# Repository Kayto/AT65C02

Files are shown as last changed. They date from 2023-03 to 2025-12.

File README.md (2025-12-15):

# AT65C02

**Latest News 15/12/2025**

**ATOS Software Released!** The main software suite for AT65C02 is now available in the Software_ATOS directory. ATOS (AT65C02 Operating System) provides a complete ROM-based monitor (SMON), interactive shell, trace/debugging commands, loadable program support, and integrated EhBASIC. The codebase has been extensively cleaned up and optimized with comprehensive documentation. This is now the recommended primary software for the AT65C02 platform.

**Hardware ideas 29/05/2025**

Picking up a few ideas for updates and improvements of the AT65C02.

1. How useful is the modem? Will i ever get around to testing this and integrating code? My vote is swinging to remove it. Opportunity to tidy the layout to better group a pinout for onboard rom programming.
2. I didn't add the possibility of using a MOS 6502! Looks like a simple jumper addition would allow this. 
3. The wireless UART doesnt have flow control - is there an alternative plug in wireless board that can provide this?
4. The HEX board resistor values...[sigh]!

**Previous News**
* **Minor fixes/additions to PCB to address some of the issues (see below revisions section).**
* **I am likely to pick up a futher revision 005 to address and consolidate some of the outstanding issues.**

## Introduction

Who doesn't want to build an 8 bit computer, if you don't, look away now.
I'm not a great coder or really an experienced maker but have enjoyed the magic of tinkering around with electronics since an early age. Whilst I have dabbled with 8 bit computing since the 80s, 40 years later I realise that I still do not really understand the inner workings of them. This project was to fill this knowledge gap.

Some of the best learning is obtained from example, making mistakes and getting your hands dirty. The only way for me is to actually break things down into individual steps, unpick the items then see how they all fit together and contribute.

I cant really credit myself with "designing" the AT65C02 - it borrows heavily from the work of others. However in breaking down these designs, incorporating changes and putting them together into my very own customised board, I have in many ways gained a much better understanding of how an 8 bit computer works. Result!

## Credits and thanks

Credits and thanks are worthy of being up front especially as I have leaned heavily on the work of others. Please follow the links to their respective documentation, they are far better at explaining and documenting than I can ever provide.

* <b>[Ben Eater's 8 bit computer](https://eater.net/8bit/)</b> \- the original inspiration\.
* <b>[Dawid Buchwald's](https://github.com/dbuchwald/6502)</b> DB6502 - this is brilliantly described and the designs form the basis for the AT65C02. The code examples and build environment are also the best for getting a solid base for coding. I recommend the github and [hackaday](https://hackaday.io/project/174128-db6502) report entries to really provide a deeper explanation of the design.
* <b>[Daryl Rictor](https://sbc.rictor.org/decoder.html)</b> \- for the DEC\-1 design\. The overall site also provides some great hobby computer examples\.
* <b>[AndersBNielsen](https://github.com/AndersBNielsen/SimpleModem)</b> for the "Simple Universal Modem" design.
* <b>[TEBL](https://github.com/tebl/C64-BlinkenDiag)</b> for the basis of the Blinkenlights.
* <b>[Michael Billington](https://github.com/mike42/6502-computer)</b> 65C02 computer - my first 65C02 build, super compact and a great starter for this journey.

## General Aims

* A 6502 build, as I am most familiar with this CPU and have at least a start at knowing some code and hardware requisities.
* Provide a learning platform for both the hardware and software. Ideally have a ready code base to get started with quickly.
* Avoid the hassles of masses of wiring and connections. To suit limited space, no mass of breadboards and able to tuck away in a cupboard to pick up quick.
* No great purist aspirations on the hardware, readily available components and no need to learn other code to get things running.

## Bespoke Aims

Some of these are really down to personal preference and perhaps held back a little by lack of knowledge.

* A load and save interface - to avoid pulling and burning ROMs every code example.
* Plenty of expansion - allows to tinker with interfacing displays and add ons.
* Wireless serial - the less wires the better.
* Adjustable memory decoder - because I can be indecisive and like to tinker.
* Blinkies - so I can get a real look at monitoring whats going on at an individual control signal, data and address line level.

## Final Features



In no particular order the main features in the final board are as follows.

* Onboard Step clock with manual and automatic tick. Speeds aprox 1-500Hz.
* Onboard 1mhz fixed clock.
* Seperate onboard serial clock.
* Blinky indicators - main signals, data and address, individual on/off switches.
* UART interface for external USB serial interface.
* ESP interface for wireless UART interface.
* Level shifter port for 5v and 3.3v signal conversion.
* Onboard 3.3v power regulator.
* Flexible IO and memory decoder via programable GAL. (this is now an add on board - it was too much to include on the same board).
* 2No VIAs - one for Keyboard, LCB and Blink LED - one spare for projects.
* Keyboard interface port (nice to have).
* LCD interface port.
* Onboard Blink LED (VIA1).
* VIA2 interface port.
* 4No. System Bus expansion interfaces (1No. via blinky latches).
* Modem audio interface.
* CPU extra signal breakout.
* LED brightness and LCD contrast adjusters - for late night blinky watching.
* Breakouts for ROM allow programming onboard via an Arduino or see below for ZIF option.
* Optional ZIF socket for ROM. Its a tight space but PCB ammended to accomodate the option of a ZIF socket at U8. **Please note that the ZIF socket interfers with the HEX expansion board. You will need a greater standoff to fit. The ZIF handle may also need shortening**.

## Memory Map

As will become clear when you tinker with 6502 builds, the hardware decisions up front impact the available memory size and locations.
Dawid Buchwald DB6502 provides a great explanation of the decisions around the choice of memory map and the differences with Ben Eater's design.
The default memory map for the AT65C02 is the same as DB6502 as follows.

| Segment | AT65C02 | Comment |
| --- | --- | --- |
| RAM | 0x0000-0x7fff | 32K |
| VIA1 | 0x9000 | Connected to keyboard/LCD/blink LED |
| VIA2 | 0x8800 | VIA 2 port |
| ACIA | 0x8400 |  |
| ROM | 0xa000-0xffff | 24K First 8K of 32K ROM are not accessible |

Given I can be indecisive and to allow some experimentation with alternative memory maps I have included the option of switching to a programmable memory decoder. This uses the DEC-1 design by Daryl Rictor. The default DEC-1 map is as follows but with a bit of programming of the GALV22V10, you can experiment with other maps.

| Segment | DEC-1 | Comment |
| --- | ----- | --- |
| RAM | $0000-$01FF | zero page and stack space |
| IO Device #1 | $0200-$020F | (16 bytes) |
| IO Device #2 | $0210-$021F | (16 bytes) |
| IO Device #3 | $0220-$022F | (16 bytes) |
| IO Device #4 | $0230-$023F | (16 bytes) |
| Unassigned | $0240-$02FF |  |
| RAM | $0300-$7FFF | 32K |
| ROM | $8000-$FFFF | 32K |

## AT65C02 Build

The Final Rev004 PCB corrects the errors in my test builds. This first (Rev002) and second (Rev003) and third (Rev004) build was documented on [twitter](https://twitter.com/AdamT117). Feel free to check out those posts.

**Rev003 Spolier Alert** \- I had high hopes that Rev003 would be the final but alas things never work out as they should\, especially when learning\. Rev003 board undergoing testing\. ROM and VIA address decoding \- tested working\. RAM was troublesome\. I had a short between RAM OE and the RAM CS at the 74HC00 gates\. Oddly this was still there with all ICs unpopulated so must be a hidden short or trace damage\. The bare PCBs were ok\, so ruled that one out\. Given lack of time and parts I couldn't face another full build of a spare board\. Temporarily bodging the 74HC00 \(until i can find time to reassemble another board\)\, the Programmable memory decoder works when added to the dedicated expansion port\. Tested working alternative map with ROM at $8000\. OS/1 tested working via wireless serial add ons\. There is an issue on loading anything over 1K via wireless serial but this looks to be a software problem\.

**Rev002 Spolier alert** -The issues I found were mainly related to incorporating the adjustable address decoder. In trying to incorporate both a fixed and programmable GAL decoder I inadvertently bridged the RAM and ROM OE/CS lines. This was fixed with a trace cut and bodge but rendered the programmable memory decoder useless. Troubleshooting for the rev003 modifications involved temporary wires and jumpers. Other minor issues were silkscreen errors, this led me down a rabbit hole on a few occasions. The UART labels were mixed up, the level shifter pinout order was on the bottom of the board, the oscillator orientation was not clearly marked etc. I also took the opportunity to add in additional breakout headers for some unused CPU lines and for the ROM - allowing onboard ROM programming.

The repository provides the files for you to create your very own AT65C02.

* [Schematics](https://github.com/Kayto/blob/main/KiCad/Rev004/AT65C02_Schematic.pdf)
* [KiCad project files](https://github.com/Kayto/tree/main/KiCad/Rev004)
* [Gerber files](https://github.com/Kayto/tree/main/Gerbers)
* [BOM](https://github.com/Kayto/blob/main/KiCad/Rev004/AT_65C02_Computer_Rev004.csv)


### REVISION STATUS & ISSUES

**REV 004 - for final issue**

* Main board, Hex board and Programmable Memory Decoder Tested working.
* Modem - UNTESTED AT THE MOMENT

**Slight annoyances (which may or may not be investigated/fixed)**

* Hex board - for data FF the low F is very low brightness. It really needs some further balancing of the resistor values and grounding.
* Blinkies - Data lines have a bit of jitter with the clock. No biggie but OCD spotted it.
* Wireless Serial - using Xmodem is fine with very small code uploads but the larger files fail. Workaround is to use a wired serial. I am hoping this can be helped with code but might wait until I can acquire the skills to troubleshoot! **Update 06/2024. Rather stupidly I forgot that the ESP-01 does not have flow control. Therefore anything bigger than the buffer (like large file transfers) fails. The ESP-01 therefore provides a useful serial input but its use is limited.**
* Wired UART Interface - Silkscreen RTS and CTS need swapping. Bit of a mistake as I was looking at a direct FTDI plug in. As FTDI programmers vary its no big issue to use jumper wires. **Fixed 08/2023**.
* Wireless or wired serial switching - would have been nice to have a jumper to switch out the wireless ESP-01 module rather than unplugging. **Fixed 08/2023**.
* Breakouts for x2 spare level shifter channels. **Fixed 08/2023**.
* Standardise some headers to even sizes. **Fixed 08/2023**.

## JUMPERS

There are a number of jumpers/headers on the PCB which may need some explanation?
I have created a separate page [here](https://github.com/Kayto/blob/main/Jumpers.md) to explain them.

## Software

### ATOS - Primary Software Suite (RECOMMENDED)

**[Software_ATOS](https://github.com/Kayto/AT65C02/tree/main/Software/Software%20_ATOS)** is the main firmware and software suite for the AT65C02. It provides a complete operating environment with ROM-based SMON monitor, interactive shell, comprehensive debugging tools, and loadable program support.

**Key Features:**
- ROM-based SMON monitor with full debugging capabilities
- Interactive shell with command history
- Trace commands: single-step (TW), breakpoints (TB), run-to-address (TQ/TS)
- Loadable program support via Intel HEX format
- Integrated EhBASIC interpreter
- LCD and serial I/O drivers
- Multiple UART support (6551, 6522, 6850)
- Complete build system using Docker (cc65 toolchain)
- VS Code integration with build tasks

**Quick Start:**
```bash
cd Software_ATOS
docker run --rm -v '${PWD}:/mnt/project' dawidbuchwald/cc65-tools-make all
```

See the [ATOS README]([Software_ATOS](https://github.com/Kayto/AT65C02/tree/main/Software/Software%20_ATOS)/README.md) for complete documentation.

### Alternative Software Options

As stated earlier Dawid Buchwald provides a suite of ROM and loadable sources in his github repo. This will get you on your way to coding quickly. If you are struggling with a build environment then he also has great tutorial examples and even provides a [docker image](https://github.com/dbuchwald/cc65-tools), great work.

I am trying to avoid duplication of the original code repos so where possible will only include the new or revised code. Please check the original author licence included in the folders and in the acknowledgments.

| Reference | Description | Credit |
| --- | --- | --- |
| **[50\_mem\_read](https://github.com/Kayto/tree/main/Software/50_mem_read)** | RAM test, VIA1 and VIA 2 test blinks | by me - needs to be combined with the DB6502 repo for compilation. |
| **[sbc2os](https://github.com/Kayto/tree/main/Software/sbc2os)** | I include here the revised TASS source as it needed changes for the default AT65C02 memory map. A binary is also included for those who may struggle with TASS. | Original by [Daryl Rictor](https://sbc.rictor.org/sbcos.html). The original author README is included. |
| **[EhBasic](https://github.com/Kayto/tree/main/Software/EhBasic)** | Using the DB6502 docker image for compilation | Refer to the included [license](https://github.com/Kayto/blob/main/Software/EhBasic/LICENSE) file. |
| **[smon6502](https://github.com/Kayto/tree/main/Software/smon6502)** | [dhansel smon6502](https://github.com/dhansel/smon6502) Using the DB6502 VASM docker image for compilation. | Refer to the included [Readme](https://github.com/Kayto/blob/main/Software/smon6502/readme.md) file. |
| **[sysmon65](https://github.com/Kayto/tree/main/Software/SYSMON65-main)** | [jdimeglio sysmon65](https://github.com/jdimeglio/SYSMON65) | Binary only ATM. Will include the relevant modified source files shortly. Use original source and replace files that have been modified. Compilation requires the Michal Kowalski assembler/simulator |

The only other code requirement is for the ATTiny4313, for the onboard keyboard controller. An explanation of this is in the [Arduino](https://github.com/Kayto/tree/main/Software/Arduino) folder.

## Expansion

### Hex Board



Gerbers and KiCad is provided in this repo for an expansion board. This PCB plugs into the expansion port next to the blinkies. It provides hexidecmal display output aligned with the blinkenlights. Look in the software folder for the .jed files for programming the GALs.

### Programmable IO and memory decoder



This is now a seperate PCB that plugs into the relevant marked ports. Gerbers and KiCad provided. Allows tinkering with IO and memory maps. The design is based on the DEC-1 so refer to the links to Daryl Rictor's site for the .jed file for the GAL.

## Future Expansion

I have a number of aspirations for future expansion boards which are part way into development or at least have me thinking about. Most will rely on code development so really have no fixed date for release.

#### Floppy Drive controller

Allowing connection and control of a 5.25inch floppy disc drive. There are a few existing examples by some clever folk that could be adapted for use. I envisage a vertical board into an expansion slot - there are also plenty of additional breakouts on the AT65C02 that could be jumper wired if needed. A connector on an expansion board is not that robust. I thought of providing space for a DIN connector on the main board to serve this future item - but will save as just an idea for now.

#### Case

This could be an easy one as by some fluke the board size seems to fit some IKEA storage boxes I use. Most of the switches used on the board can be jumpered as I have used header pins. Similarily any expansion could be wired up too.



#### Debugger Plug-in

**Coming Soon -** A plug in board to allow degugging and onboard ROM programming via an Arduino.

## Licenses & acknowledgement

Further to the links in the credit section.
The design is an extension of Ben Eater's 6502 computer tutorial, which is itself based on the work of the 6502.org community.

**6502 KiCad Library**

The PCB files use modified versions of the 6502 KiCad Library. Copyright 2018, Nicholas Parks Young. All Rights Reserved. The 6502 KiCad Library library is licensed under the GNU LGPL v2.1

**EhBASIC**

With the exception of the files noted below, code base © 2021 Michael Billington, and is licensed under a Creative Commons Attribution 4.0 International License.
The files in EhBasic/basic/ are derived from EhBASIC, developed by Lee Davidson. The EhBASIC license allows for non-commerical use only. The most recent release and manual is hosted here, and a mirror of Lee's website can be found here.

EhBASIC is free but not copyright free. For non commercial use there is only one restriction, any derivative work should include, in any binary image distributed, the string "Derived from EhBASIC" and in any distribution that includes human readable files a file that includes the above string in a human readable form e.g. not as a comment in an HTML file.

**DB6502 Code**

OS/1, related code examples and Arduino code is Copyright (c) 2020 Dawid Buchwald and is licensed under a MIT License.

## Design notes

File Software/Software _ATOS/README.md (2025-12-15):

# ATOS - AT65C02 Operating System

ATOS is the main firmware and software suite for the [AT65C02 computer](https://github.com/Kayto/AT65C02). It provides a complete operating environment with ROM-based monitor, shell, and loadable program support.

## Overview

ATOS combines SMON with an enhanced shell, LCD support, and EhBASIC integration to create a complete operating system for the AT65C02. The system supports loading and running programs from serial input, provides a comprehensive debugging environment, and includes built-in BASIC interpreter.

**Key Features:**

* ROM-based monitor (SMON) with full debugging support
* Interactive shell with command history and help system
* Trace/debugging commands: single-step, breakpoints, run-to-address
* Loadable program support via Intel HEX format
* Integrated EhBASIC interpreter
* LCD and serial I/O support
* Multiple UART options (6551, 6522, 6850)

## Quick Start

### Building Everything

``` bash
docker run --rm -v '${PWD}:/mnt/project' dawidbuchwald/cc65-tools-make all
```

This builds:

* **ROM firmware** (ATOS.ext.bin) - Flash to EEPROM at $A000-$FFFF
* **All loadable programs** \- Load via SMON `.L` command

### Building Just the ROM

``` bash
docker run --rm -v '${PWD}:/mnt/project' dawidbuchwald/cc65-tools-make -C rom/ATOS all
```

Output: `build/rom/ATOS.ext.bin` (24KB)

### Installing to EEPROM

``` bash
docker run --rm -v '${PWD}:/mnt/project' dawidbuchwald/cc65-tools-make -C rom/ATOS all install
```

Requires minipro programmer.

## Directory Structure

```
Software_ATOS/
├── rom/ATOS/           # ROM firmware source
│   ├── smon.s          # SMON monitor
│   ├── shell.s         # Interactive shell
│   ├── lcd.s           # LCD driver
│   ├── boot_anim.s     # Boot animation
│   ├── basic_rom.s     # EhBASIC integration
│   ├── kernal.s        # Kernal functions & UART drivers
│   ├── config.s        # System configuration
│   ├── uart_6551.s     # WDC 65C51 ACIA driver
│   ├── uart_6522.s     # MOS 6522 VIA UART driver
│   ├── uart_6850.s     # MC6850 UART driver
│   └── atos.cfg        # Linker configuration
├── load/               # Loadable programs
│   ├── ehbasic/        # EhBASIC loadable version ($2000)
│   ├── trace_test/     # SMON trace command test program
│   ├── lcd_hello/      # LCD hello world example
│   ├── serial_hello/   # Serial hello world example
│   ├── via2_led_flash/ # VIA2 LED flasher
│   ├── via_alternate/  # VIA LED alternate blink
│   └── via2_flash_trace/ # VIA2 with trace test
├── common/             # Build infrastructure
│   ├── makefile        # Common build rules
│   ├── load.cfg        # Loadable program linker config
│   ├── bin2hex.py      # Binary to Intel HEX converter
│   └── loadtrim.py     # Loadable binary trimmer
└── BASIC/              # EhBASIC example programs
```

## Memory Map

ATOS uses the DB6502-compatible memory map:

| Address Range | Usage | Size |
| --- | ----- | ---- |
| $0000-$00FF | Zero page | 256 bytes |
| $0100-$01FF | Stack | 256 bytes |
| $0200-$0FFF | System RAM | 3.5 KB |
| $1000-$7FFF | User RAM | 28 KB |
| $8000-$8FFF | Filler (unmapped) | 4 KB |
| $9000-$9FFF | VIA1 | 4 KB window |
| $8800-$8FFF | VIA2 | 2 KB window |
| $8400-$87FF | ACIA | 1 KB window |
| $A000-$FFFF | ROM (ATOS) | 24 KB |

**Hardware addresses:**

* VIA1: $9000 (Keyboard/LCD/Blink LED)
* VIA2: $8800 (Expansion port)
* ACIA: $8400 (Serial communication)

**Loadable programs** run from $1000-$3000 (trace\_test, lcd\_hello, serial\_hello) or $2000-$8000 (ehbasic).

## SMON Monitor Commands

SMON provides a comprehensive debugging and development environment:

### Memory Operations

* `M xxxx yyyy` \- Memory dump from xxxx to yyyy
* `:xxxx nn nn...` \- Store bytes starting at xxxx
* `C xxxx yyyy zzzz` \- Copy memory from xxxx\-yyyy to zzzz
* `F xxxx yyyy nn` \- Fill memory from xxxx to yyyy with byte nn

### Execution & Tracing

* `G xxxx` \- Run to BRK from address xxxx \(fast execution\)
* `TW xxxx` \- Single\-step with keypress \(trace walk\)
* `TB xxxx nn` \- Breakpoint with hit count \(trace breakpoint\)
* `TQ xxxx` \- Run to breakpoint\, then single\-step \(trace queue\)
* `TS xxxx yyyy` \- Run until address \(trace stop\)

### Loading & Running

* `.L` \- Load Intel HEX file from serial
* `.T xxxx` \- Test/hexdump memory from xxxx
* `.R` \- Reset system
* `B` \- Run EhBASIC \($A000\)

### Disassembly & Utilities

* `D xxxx yyyy` \- Disassemble from xxxx to yyyy
* `A xxxx` \- Assemble at address xxxx
* `R` \- Display/modify registers
* `? xxxx+yyyy` \- Add hex values
* `? xxxx-yyyy` \- Subtract hex values
* `# xxxx` \- Convert hex to decimal
* `$ nnnn` \- Convert decimal to hex
* `% bbbb` \- Convert binary to hex
* `H` \- Display help

### Configuration

* `O` \- Display configuration
* `W n` \- Set UART type \(1=6522\, 2=6551\, 3=6850\)

See [load/trace\_test/TESTING.md](load/trace_test/TESTING.md) for detailed trace command examples and debugging workflow.

## Loadable Programs

### Loading Programs

1. Build the program to generate `.hex` file
2. Connect to ATOS via serial (19200 baud, 8N1)
3. Enter SMON command: `.L`
4. Send the Intel HEX file content via the terminal
5. Run with `G xxxx` (where xxxx is load address)

### Example Programs

**trace\_test** ($1000) - SMON trace command test suite

```
.L [send trace_test.load.hex]
TW 1000    # Single-step through program
TB 1004 3  # Breakpoint at $1004, stop on 3rd hit
```

**lcd\_hello** ($1000) - LCD "Hello World" demonstration

```
.L [send lcd_hello.load.hex]
G 1000     # Run program
```

**serial\_hello** ($1000) - Serial "Hello World"

```
.L [send serial_hello.load.hex]
G 1000
```

**ehbasic** ($2000) - Full EhBASIC interpreter (loadable version)

```
.L [send ehbasic.hex]
G 2000     # Start BASIC
```

Or use ROM-based version: `B` command

## Building Custom Programs

### Minimal Assembly Program

``` assembly
; Load at $1000
.org $1000

start:
    LDA #$FF      ; Your code here
    BRK           ; Return to SMON
```

### Build with Common Makefile

Create `makefile`:

``` makefile
PROJECT_NAME=myprogram
BUILD_TYPE=load

ASM_SOURCES=myprogram.s
C_SOURCES=

include ../../common/makefile
```

Build:

``` bash
docker run --rm -v '${PWD}:/mnt/project' dawidbuchwald/cc65-tools-make -C load/myprogram all
```

Output: `build/load/myprogram/myprogram.load.hex`

## Configuration

### UART Selection

Edit [rom/ATOS/config.s](rom/ATOS/config.s):

``` assembly
; UART options: 6522, 6551, or 6850
UART_TYPE = 6551
```

Rebuild ROM after changes.

### System Parameters

**config.s** settings:

* `VIA` \- VIA1 base address \(default $9000\)
* `RAMTOP` \- Highest RAM address \(default $7FFF\)
* `CPU_CLOCK_RATE` \- Clock frequency for UART timing \(default 1MHz\)
* `UART_TYPE` \- UART chip selection

## VS Code Integration

The project includes VS Code tasks for common operations:

* **Ctrl+Shift+B** \- Build All \(default\)
* Build ATOS - ROM firmware only
* Build Loadable Program - Select from list
* Clean All / Clean ATOS / Clean Loadable Program
* Install ATOS to EEPROM - Build and flash

## Testing

### Trace Test Suite

The [trace\_test](load/trace_test) program validates all SMON trace commands:

```
.L [send trace_test.load.hex]
TW 1000        # Walk through each instruction
TB 1004 0E     # Break on 15th hit of loop
TQ 1000
TS 1000 1011        # Run until after subroutine
```

See [TESTING.md](load/trace_test/TESTING.md) for complete test procedures.

### LCD Hello Test

Assuming you have a 20 x 4 LCD connected.

```
.L [send lcd_hello.load.hex]
G 1000
```

Should display:

```
Line 1: Hello
Lin2 2: World
Line 3: Test!
Line 4: Done!
```

## Troubleshooting

### Build Issues

**Docker not found:**

``` bash
# Install Docker Desktop or Docker Engine
# Verify: docker --version
```

**Permission denied:**

``` bash
# Linux/Mac - ensure proper volume mount permissions
docker run --rm -v "$(pwd):/mnt/project" ...
```

**Windows path issues:**

``` powershell
# Use forward slashes in PowerShell
docker run --rm -v '${PWD}:/mnt/project' ...
```

### Runtime Issues

**No serial output:**

* Check UART\_TYPE matches your hardware (config.s)
* Verify baud rate: 19200 8N1
* Check serial cable wiring (TX/RX crossed)

**Program won't load:**

* Verify `.L` command entered before sending HEX
* Check Intel HEX format (starts with `:`)
* Ensure no extra characters in HEX file

**Trace commands slow:**

* TB/TQ/TS use VIA timer (normal \~30s per screen)
* For faster execution use `G xxxx` (runs at full speed to BRK)

**LCD not working:**

* Check LCD wiring to VIA1 port
* Verify 4-bit mode connections (PB4-PB7 data, PB1-PB3 control)
* Adjust contrast potentiometer

## Build System

ATOS uses a unified makefile-based build system:

**Root makefile** \- Orchestrates ROM and loadable builds
**rom/ATOS/Makefile** \- Standalone ROM firmware build \(ca65/ld65\)
**common/makefile** \- Shared rules for loadable programs
**load/\*/makefile** \- Individual program makefiles

All builds use Docker container: `dawidbuchwald/cc65-tools`

## License

ATOS is composed of multiple components with different licenses:

**SMON Monitor** \- Public domain \(1984 magazine code\, adapted by David Hansel\)
**AT65C02 Modifications** \- MIT License \(kayto@github\.com\)
**EhBASIC** \- Non\-commercial use only \(Lee Davidson\)
**Build Infrastructure** \- MIT License \(Dawid Buchwald\)
**Build Tools (cc65)** \- BSD\-style license

See [LICENSE.txt](LICENSE.txt) and [NOTICE.txt](NOTICE.txt) for complete details.

## Credits

**SMON Monitor** \- Originally published in 1984 by Norfried Mann and Dietrich Weineck\, extensively modified by David Hansel \([dhansel/smon6502](https://github.com/dhansel/smon6502))

**AT65C02 Hardware** \- Designed by kayto \([Kayto/AT65C02](https://github.com/Kayto/AT65C02))

**Build System & Framework** \- Dawid Buchwald \([dbuchwald/6502](https://github.com/dbuchwald/6502))

**EhBASIC** \- Lee Davidson's Enhanced BASIC for 6502

**cc65 Toolchain** \- Ullrich von Bassewitz and contributors

## Resources

* [AT65C02 Hardware Repository](https://github.com/Kayto/AT65C02) \- PCB designs\, schematics\, BOM
* [SMON Documentation](https://github.com/dhansel/smon6502) \- Original SMON source and docs
* [DB6502 Project](https://github.com/dbuchwald/6502) \- Build system inspiration
* [cc65 Documentation](https://cc65.github.io/) \- Assembler and toolchain docs
* [6502.org](http://6502.org/) \- 6502 programming resources

## Contributing

Contributions are welcome! Please:

1. Fork the repository
2. Create a feature branch
3. Make your changes
4. Test on actual AT65C02 hardware if possible!

**Areas for contribution:**

* Additional loadable programs
* Shell command enhancements
* Hardware driver improvements
* Documentation updates
* Bug fixes

## Changelog

**December 2025**

* First issue v0.1

## Support

For hardware issues, see the [AT65C02 repository](https://github.com/Kayto/AT65C02).

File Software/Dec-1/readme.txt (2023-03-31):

DEC-1 Memory Decoder Project

DEC-1.PLD is the WinCUPL Source file
DEC-1.JED is the JEDEC output file

Source file compiled with WinCUPL V5.30.4

ALL material is (c) 2010 by Daryl Rictor

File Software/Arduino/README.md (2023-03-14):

# Attiny4313

The code is available from Dawid Buchwald's DB6502 project. I include a precompiled file in this my repo for ease.

I must admit this chip can be quite elusive and perhaps breaks one of my aims of using readily available chips. That said its not critical to have it - it just allows connection of a PS/2 keyboard directly to the board. You can still interact via terminal keyboard if you dont have it.

Programming the chip could also be more involved if you are not familiar with microcontroller programming and dont already have a programmer handy.

You need a USBAsp programmer, to program on the board or you can remove the chip to program in a seperate programer like say the TL866.

Some steps to program the chip are included here.

* Disconnect AT65C02 from the power and use the onboard headers to connect the USBAsp programmer.

* Sometimes the USBAsp programmer can be a pain to get connected, this is due to the default speed setting of the chip versus the programmer speed. The best option for me was to use AVRDudess (avrdude GUI), look for the -B Bit Clock setting and lower the default value. This should get you connected. From this you can change the fuses and lock bits. Make sure the "divide clock by 8 internally; [CKDIV8=0]" is not set by changing the Low bit to 0xE2.

* Setup the ATTiny boards within the ArduinoIDE. Add the following into your additional boards http://drazzy.com/package_drazzy.com_index.json and add the board via board manager.
* Grab the ATTinycore arduino libraries.

* Having changed the Low bit you now should be able to compile and upload the code to the chip from the ArduinoIDE. The only setting I fiddled with was to make sure the clock was set to 8Mhz(internal). Dont forget to change the programmer to USBAsp in "tools" and upload via "sketch"-"Upload using programmer", rather than the normal verify and upload route.

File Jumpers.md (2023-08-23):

## Jumpers

There are numerous jumpers/headers/sockets on the board to adjust the function and provide expansion. It was worthy of more explanation - hence a fresh page.

Note that all on/off switches have been substituted for 2.54mm pitch male pin headers that require shunts to bridge for on/off etc. Similarily this applies to chip select/enables and all LEDs on the board with the exception of the power light. This approach was mainly to save cost but there is something about slide switches that never last that long. If you dont want to waste the headers you can just default bridge the through holes.

Personally I find it useful that you can enable/disable the blinkies - given that at clock speeds over 500Hz they really cannot be read and waste power - carbon saving bonus. 

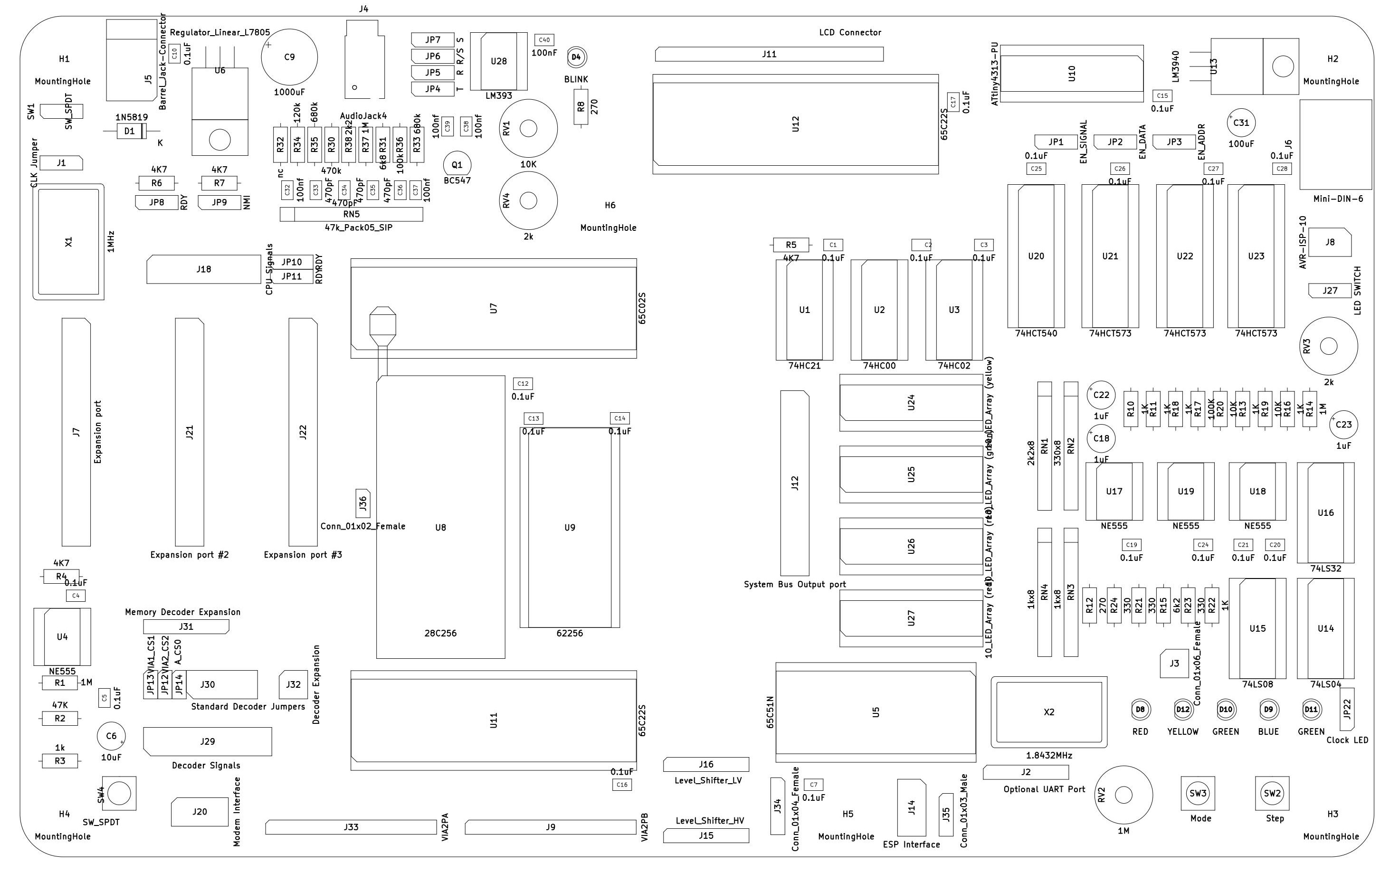
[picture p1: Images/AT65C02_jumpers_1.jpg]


The following **ports** are located on the board with a brief explanation.

| PCB Reference| Description | Comment |
|---|---|---|
| J2 | UART port |- |
| J3 | Clock signal breakout |- |
| J4 | Modem Audio input/output |- |
| J5 | Power connector 12v DC |- |
| J6 | Mini DIN for Keyboard |- |
| J7 | Expansion port #1 |- |
| J8 | AVR ISP port for programming keyboard controller |- |
| J9 | VIA2PB |VIA 2 Port B |
| J11 | LCD Connector |LCD port (4- bit) |
| J12 | System Bus Output port |Output port via blinky latches |
| J14 | ESP Interface |Wireless (ESP) port |
| J15 | HV Level Shifter port H1, H2 |HV Level Shifter port |
| J16 | LV Level shifter port L1, L2 |LV Level shifter port |
| J18 | CPU Signal Port |Breakout port for various CPU signals. **Note - ROM WE needs wire jumper to +5V or else all hell breaks loose!**|
| J20 | Modem Interface |- |
| J21 | Expansion port #2 |- |
| J22 | Expansion port #3 |- |
| J29 | Decoder Signals |memory decoder signal port - default bridge all for onboard decoder |
| J30 | Standard Decoder Jumpers | IO and RAM signal port -  default bridge all for onboard decoder |
| J31 | Memory Decoder Expansion |address signal port for adjustable decoder |
| J32 | Decoder Expansion |memory decoder signal port - default bridge all for onboard decoder |
| J33 | VIA2PA |VIA 2 Port A |
| J34 | H1,H2,L1,L2 port |Breakout port for spare level shifter I/O |
| J36 | ROM OE CS port for onboard ROM programming |- |
| JP4 | T |Modem jack TRRS pattern jumpers |
| JP5 | R |Modem jack TRRS pattern jumpers |
| JP6 | R/S |Modem jack TRRS pattern jumpers |
| JP7 | S |Modem jack TRRS pattern jumpers |
| JP8 | RDY HI  LO - CPU RDY pin tie |adjustable - default pulled up to +5V through a pull-up resistor |
| JP9 | NMI HI  LO -CPU NMI pin tie |adjustable - default pulled up to +5V through a pull-up resistor |
| JP10 | SO HI  LO -CPU SO pin tie |adjustable - default pulled up to +5V |
| JP11 | BE HI  LO -CPU BE pin tie |adjustable - default pulled up to +5V |
| JP12 | Onboard VIA2_CS2 enable |When bridged enables onboard VIA |
| JP13 | Onboard VIA1_CS1 enable |When bridged enables onboard ACIA |
| JP14 | Onboard A_CS0 enable |When bridged enables onboard VIA |

The following **switch headers** are located on the board with a brief explanation.
| PCB Reference| Description | Comment |
|---|---|---|
| J1 | Clock Selector |Switch between fixed clock and step clock |
| J27 | LED On Off |On/Off for Signal/Data/Address Blink LED |
| J35 | ESP On Off |On/Off for Wireless (ESP) port |
| JP1 | Signal LED On Off |enables/disables blinky latch Chip Select |
| JP2 | Data LED On Off |enables/disables blinky latch Chip Select |
| JP3 | Address LED On Off |enables/disables blinky latch Chip Select |
| JP22 | CLK LED On Off |On/Off for step clock LEDs |
| SW1 | Power On Off |Power Switch |
| SW2 | Single Step push button |Switch between fixed clock and step clock |
| SW3 | Mode selector button - step or continuous |Mode selector button - step or continuous |
| SW4 | Reset push button |Reset push button |

Default jumper setting are shown below.

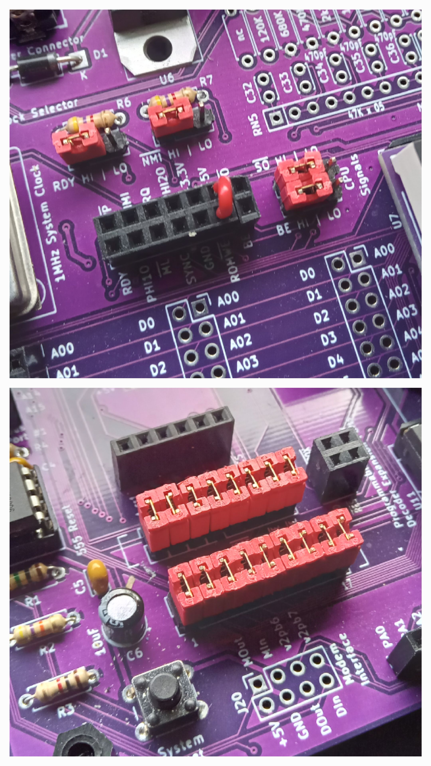
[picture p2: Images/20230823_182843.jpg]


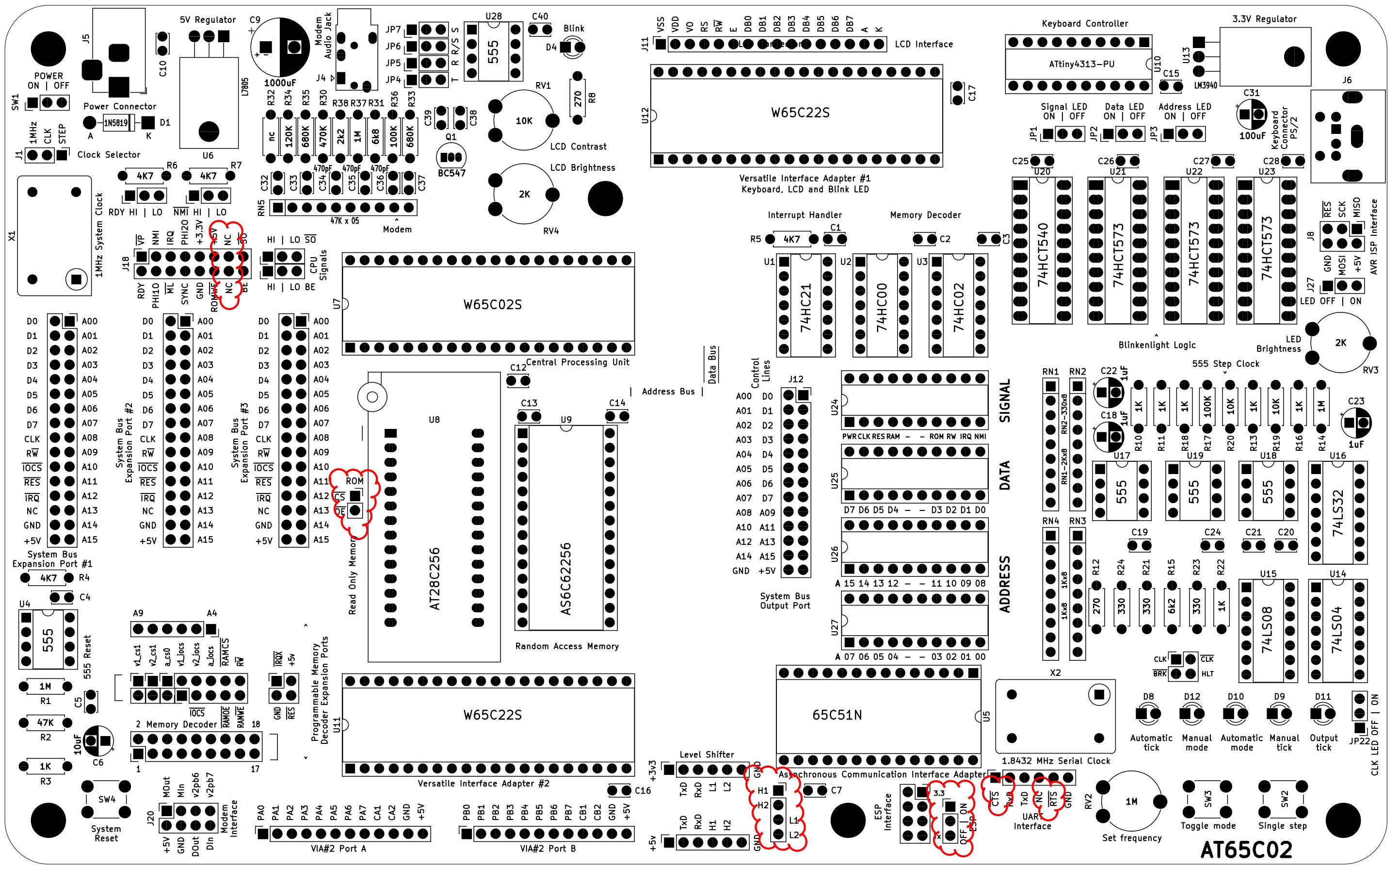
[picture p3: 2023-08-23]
Images/AT65C02_PCB_Silkscreen_1.jpg

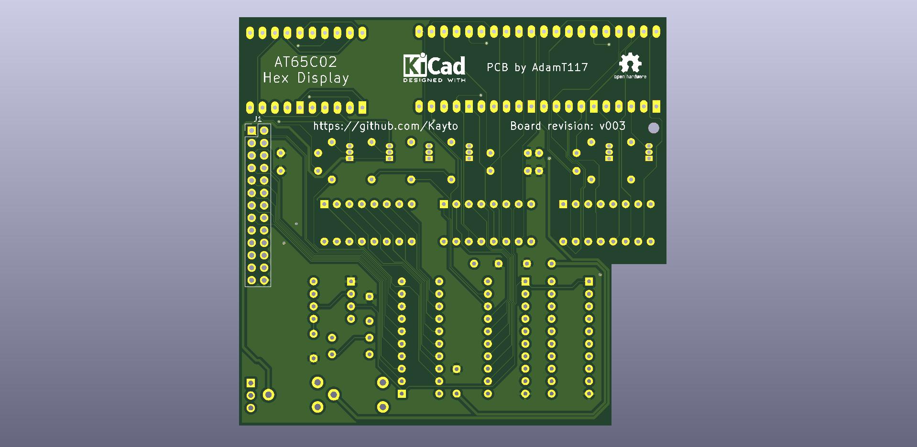
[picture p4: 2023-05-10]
KiCad/Hex Display Rev003/AT65C02_HEX_rev003_PCB_BACK.jpg

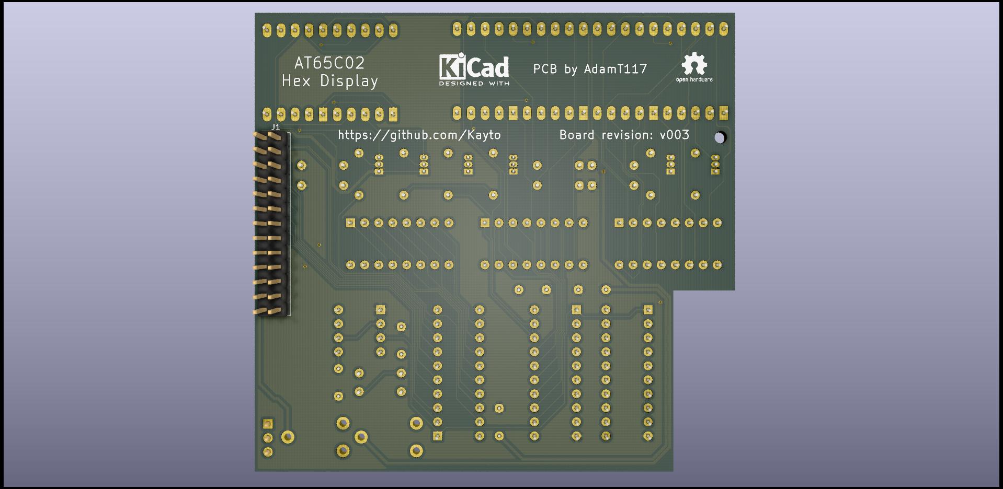
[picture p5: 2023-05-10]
KiCad/Hex Display Rev003/AT65C02_HEX_rev003_BACK.jpg

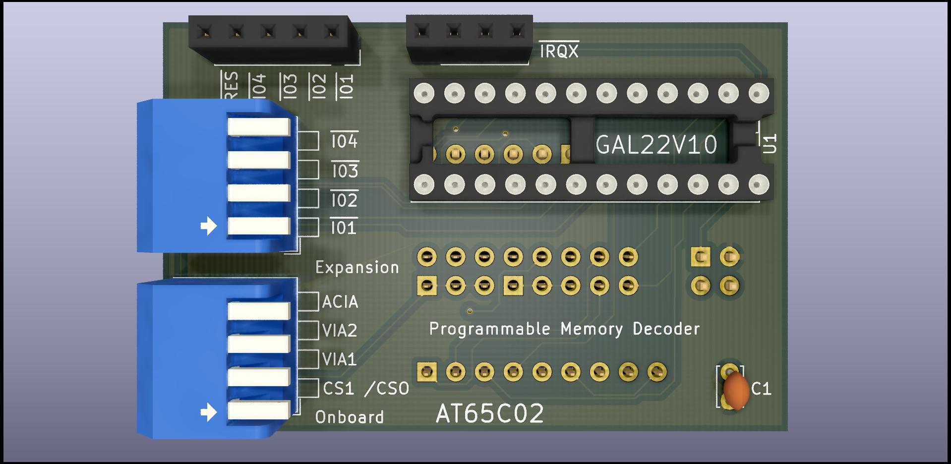
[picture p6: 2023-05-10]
KiCad/Memory Decoder/Memory Decoder_front.jpg

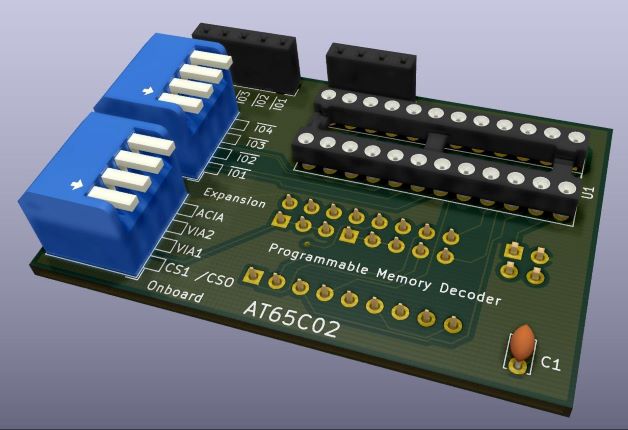
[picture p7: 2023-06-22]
KiCad/Hex Display Rev003/Memory Decoder.jpg

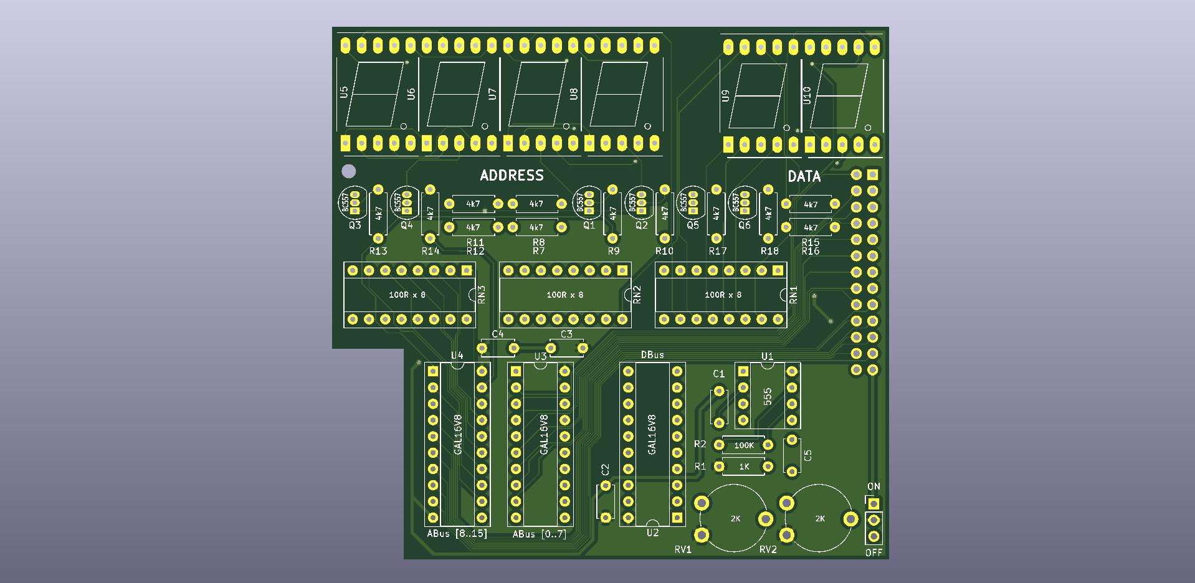
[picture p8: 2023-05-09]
KiCad/Hex Display Rev003/AT65C02_HEX_rev003_PCB_FRONT.jpg

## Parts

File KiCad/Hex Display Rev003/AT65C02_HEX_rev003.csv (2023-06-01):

Source: | C:\Users\Adam\Documents\GitHub\AT_65C02\KiCad\Hex Display Rev003\AT65C02_HEX_rev003.sch
Date: | 01/06/2023 16:07:12
Tool: | Eeschema (5.1.9)-1
Generator: | C:\Program Files\KiCad\bin\scripting\plugins/bom_csv_grouped_by_value.py
Component Count: | 43
Individual Components:
Item | Qty | Reference(s) | Value | LibPart | Footprint | Datasheet
 |  | C1 | 0.01uF | Device:C | Capacitor_THT:C_Disc_D5.0mm_W2.5mm_P5.00mm | ~
 |  | C2 | 100n | Device:C | Capacitor_THT:C_Disc_D5.0mm_W2.5mm_P5.00mm | ~
 |  | C3 | 100n | Device:C | Capacitor_THT:C_Disc_D5.0mm_W2.5mm_P5.00mm | ~
 |  | C4 | 100n | Device:C | Capacitor_THT:C_Disc_D5.0mm_W2.5mm_P5.00mm | ~
 |  | C5 | 0.01uF | Device:C | Capacitor_THT:C_Disc_D5.0mm_W2.5mm_P5.00mm | ~
 |  | H1 | MountingHole | Mechanical:MountingHole | MountingHole:MountingHole_2.2mm_M2 | ~
 |  | J1 | Expansion Connector | Connector_Generic:Conn_02x13_Odd_Even | Connector_PinHeader_2.54mm:PinHeader_2x13_P2.54mm_Vertical | ~
 |  | J3 | Conn_01x03 | Connector_Generic:Conn_01x03 | Connector_PinHeader_2.54mm:PinHeader_1x03_P2.54mm_Vertical | ~
 |  | Q1 | BC557 | Transistor_BJT:BC557 | Package_TO_SOT_THT:TO-92_Inline | https://www.onsemi.com/pub/Collateral/BC556BTA-D.pdf
 |  | Q2 | BC557 | Transistor_BJT:BC557 | Package_TO_SOT_THT:TO-92_Inline | https://www.onsemi.com/pub/Collateral/BC556BTA-D.pdf
 |  | Q3 | BC557 | Transistor_BJT:BC557 | Package_TO_SOT_THT:TO-92_Inline | https://www.onsemi.com/pub/Collateral/BC556BTA-D.pdf
 |  | Q4 | BC557 | Transistor_BJT:BC557 | Package_TO_SOT_THT:TO-92_Inline | https://www.onsemi.com/pub/Collateral/BC556BTA-D.pdf
 |  | Q5 | BC557 | Transistor_BJT:BC557 | Package_TO_SOT_THT:TO-92_Inline | https://www.onsemi.com/pub/Collateral/BC556BTA-D.pdf
 |  | Q6 | BC557 | Transistor_BJT:BC557 | Package_TO_SOT_THT:TO-92_Inline | https://www.onsemi.com/pub/Collateral/BC556BTA-D.pdf
 |  | R1 | 1k | Device:R | Resistor_THT:R_Axial_DIN0207_L6.3mm_D2.5mm_P7.62mm_Horizontal | ~
 |  | R2 | 100k | Device:R | Resistor_THT:R_Axial_DIN0207_L6.3mm_D2.5mm_P7.62mm_Horizontal | ~
 |  | R7 | 4k7 | Device:R | Resistor_THT:R_Axial_DIN0207_L6.3mm_D2.5mm_P7.62mm_Horizontal | ~
 |  | R8 | 4k7 | Device:R | Resistor_THT:R_Axial_DIN0207_L6.3mm_D2.5mm_P7.62mm_Horizontal | ~
 |  | R9 | 18k | Device:R | Resistor_THT:R_Axial_DIN0207_L6.3mm_D2.5mm_P7.62mm_Horizontal | ~
 |  | R10 | 18k | Device:R | Resistor_THT:R_Axial_DIN0207_L6.3mm_D2.5mm_P7.62mm_Horizontal | ~
 |  | R11 | 4k7 | Device:R | Resistor_THT:R_Axial_DIN0207_L6.3mm_D2.5mm_P7.62mm_Horizontal | ~
 |  | R12 | 4k7 | Device:R | Resistor_THT:R_Axial_DIN0207_L6.3mm_D2.5mm_P7.62mm_Horizontal | ~
 |  | R13 | 18k | Device:R | Resistor_THT:R_Axial_DIN0207_L6.3mm_D2.5mm_P7.62mm_Horizontal | ~
 |  | R14 | 18k | Device:R | Resistor_THT:R_Axial_DIN0207_L6.3mm_D2.5mm_P7.62mm_Horizontal | ~
 |  | R15 | 2k2 | Device:R | Resistor_THT:R_Axial_DIN0207_L6.3mm_D2.5mm_P7.62mm_Horizontal | ~
 |  | R16 | 2k2 | Device:R | Resistor_THT:R_Axial_DIN0207_L6.3mm_D2.5mm_P7.62mm_Horizontal | ~
 |  | R17 | 680 | Device:R | Resistor_THT:R_Axial_DIN0207_L6.3mm_D2.5mm_P7.62mm_Horizontal | ~
 |  | R18 | 680 | Device:R | Resistor_THT:R_Axial_DIN0207_L6.3mm_D2.5mm_P7.62mm_Horizontal | ~
 |  | RN1 | 100 | Device:R_Pack08 | Package_DIP:DIP-16_W7.62mm_Socket | ~
 |  | RN2 | 100 | Device:R_Pack08 | Package_DIP:DIP-16_W7.62mm_Socket | ~
 |  | RN3 | 100 | Device:R_Pack08 | Package_DIP:DIP-16_W7.62mm_Socket | ~
 |  | RV1 | R_POT_Small | Device:R_POT_Small | Potentiometer_THT:Potentiometer_Piher_PT-10-V10_Vertical | ~
 |  | RV2 | R_POT_Small | Device:R_POT_Small | Potentiometer_THT:Potentiometer_Piher_PT-10-V10_Vertical | ~
 |  | U1 | NE555P | Timer:NE555P | Package_DIP:DIP-8_W7.62mm_Socket | http://www.ti.com/lit/ds/symlink/ne555.pdf
 |  | U2 | GAL16V8 | Logic_Programmable:GAL16V8 | Package_DIP:DIP-20_W7.62mm_Socket
 |  | U3 | GAL16V8 | Logic_Programmable:GAL16V8 | Package_DIP:DIP-20_W7.62mm_Socket
 |  | U4 | GAL16V8 | Logic_Programmable:GAL16V8 | Package_DIP:DIP-20_W7.62mm_Socket
 |  | U5 | E10561 | Display_Character:LuckyLight_KWI-561AVB | Display_7Segment:7SegmentLED_LTS6760_LTS6780 | http://www.kingbrightusa.com/images/catalog/SPEC/sc39-11gwa.pdf
 |  | U6 | E10561 | Display_Character:LuckyLight_KWI-561AVB | Display_7Segment:7SegmentLED_LTS6760_LTS6780 | http://www.kingbrightusa.com/images/catalog/SPEC/sc39-11gwa.pdf
 |  | U7 | E10561 | Display_Character:LuckyLight_KWI-561AVB | Display_7Segment:7SegmentLED_LTS6760_LTS6780 | http://www.kingbrightusa.com/images/catalog/SPEC/sc39-11gwa.pdf
 |  | U8 | E10561 | Display_Character:LuckyLight_KWI-561AVB | Display_7Segment:7SegmentLED_LTS6760_LTS6780 | http://www.kingbrightusa.com/images/catalog/SPEC/sc39-11gwa.pdf
 |  | U9 | E10561 | Display_Character:LuckyLight_KWI-561AVB | Display_7Segment:7SegmentLED_LTS6760_LTS6780 | http://www.kingbrightusa.com/images/catalog/SPEC/sc39-11gwa.pdf
 |  | U10 | E10561 | Display_Character:LuckyLight_KWI-561AVB | Display_7Segment:7SegmentLED_LTS6760_LTS6780 | http://www.kingbrightusa.com/images/catalog/SPEC/sc39-11gwa.pdf
Collated Components:
Item | Qty | Reference(s) | Value | LibPart | Footprint | Datasheet
1 | 2 | C1, C5 | 0.01uF | Device:C | Capacitor_THT:C_Disc_D5.0mm_W2.5mm_P5.00mm | ~
2 | 3 | C2, C3, C4 | 100n | Device:C | Capacitor_THT:C_Disc_D5.0mm_W2.5mm_P5.00mm | ~
3 | 1 | H1 | MountingHole | Mechanical:MountingHole | MountingHole:MountingHole_2.2mm_M2 | ~
4 | 1 | J1 | Expansion Connector | Connector_Generic:Conn_02x13_Odd_Even | Connector_PinHeader_2.54mm:PinHeader_2x13_P2.54mm_Vertical | ~
5 | 1 | J3 | Conn_01x03 | Connector_Generic:Conn_01x03 | Connector_PinHeader_2.54mm:PinHeader_1x03_P2.54mm_Vertical | ~
6 | 6 | Q1, Q2, Q3, Q4, Q5, Q6 | BC557 | Transistor_BJT:BC557 | Package_TO_SOT_THT:TO-92_Inline | https://www.onsemi.com/pub/Collateral/BC556BTA-D.pdf
7 | 1 | R1 | 1k | Device:R | Resistor_THT:R_Axial_DIN0207_L6.3mm_D2.5mm_P7.62mm_Horizontal | ~
8 | 1 | R2 | 100k | Device:R | Resistor_THT:R_Axial_DIN0207_L6.3mm_D2.5mm_P7.62mm_Horizontal | ~
9 | 4 | R7, R8, R11, R12 | 4k7 | Device:R | Resistor_THT:R_Axial_DIN0207_L6.3mm_D2.5mm_P7.62mm_Horizontal | ~
10 | 4 | R9, R10, R13, R14 | 18k | Device:R | Resistor_THT:R_Axial_DIN0207_L6.3mm_D2.5mm_P7.62mm_Horizontal | ~
11 | 2 | R15, R16 | 2k2 | Device:R | Resistor_THT:R_Axial_DIN0207_L6.3mm_D2.5mm_P7.62mm_Horizontal | ~
12 | 2 | R17, R18 | 680 | Device:R | Resistor_THT:R_Axial_DIN0207_L6.3mm_D2.5mm_P7.62mm_Horizontal | ~
13 | 3 | RN1, RN2, RN3 | 100 | Device:R_Pack08 | Package_DIP:DIP-16_W7.62mm_Socket | ~
14 | 2 | RV1, RV2 | R_POT_Small | Device:R_POT_Small | Potentiometer_THT:Potentiometer_Piher_PT-10-V10_Vertical | ~
15 | 1 | U1 | NE555P | Timer:NE555P | Package_DIP:DIP-8_W7.62mm_Socket | http://www.ti.com/lit/ds/symlink/ne555.pdf
16 | 3 | U2, U3, U4 | GAL16V8 | Logic_Programmable:GAL16V8 | Package_DIP:DIP-20_W7.62mm_Socket
17 | 6 | U5, U6, U7, U8, U9, U10 | E10561 | Display_Character:LuckyLight_KWI-561AVB | Display_7Segment:7SegmentLED_LTS6760_LTS6780 | http://www.kingbrightusa.com/images/catalog/SPEC/sc39-11gwa.pdf

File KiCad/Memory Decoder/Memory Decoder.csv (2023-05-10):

Source: | C:\Users\Adam\Documents\GitHub\AT_65C02\KiCad\Memory Decoder\Memory Decoder.sch
Date: | 10/05/2023 20:40:51
Tool: | Eeschema (5.1.9)-1
Generator: | C:\Program Files\KiCad\bin\scripting\plugins/bom_csv_grouped_by_value.py
Component Count: | 11
Individual Components:
Item | Qty | Reference(s) | Value | LibPart | Footprint | Datasheet
 |  | C1 | 0.1uF | Memory-Decoder-rescue:C-Device-65C02_Computer-rescue | Capacitor_THT:C_Disc_D3.4mm_W2.1mm_P2.50mm | ~
 |  | J1 | IOCS/Decoder Signals Expansion #5 | Connector_Generic:Conn_02x05_Odd_Even | Connector_PinSocket_2.54mm:PinSocket_2x05_P2.54mm_Vertical | ~
 |  | J2 | Conn_02x02_Odd_Even | Connector_Generic:Conn_02x02_Odd_Even | Connector_PinHeader_2.54mm:PinHeader_2x02_P2.54mm_Vertical | ~
 |  | J3 | Decoder Signals | Connector_Generic:Conn_01x09 | Connector_PinSocket_2.54mm:PinSocket_1x09_P2.54mm_Vertical | ~
 |  | J4 | Conn_02x03_Odd_Even | Connector_Generic:Conn_02x03_Odd_Even | Connector_PinSocket_2.54mm:PinSocket_2x03_P2.54mm_Vertical | ~
 |  | J5 | Memory Decoder Expansion | Connector:Conn_01x06_Male | Connector_PinHeader_2.54mm:PinHeader_1x06_P2.54mm_Vertical | ~
 |  | J6 | ~IOx | Connector_Generic:Conn_01x05 | Connector_PinSocket_2.54mm:PinSocket_1x05_P2.54mm_Vertical | ~
 |  | J7 | ~IRQx | Connector_Generic:Conn_01x04 | Connector_PinSocket_2.54mm:PinSocket_1x04_P2.54mm_Vertical | ~
 |  | SW1 | SW_DIP_x04 | Switch:SW_DIP_x04 | Button_Switch_THT:SW_DIP_SPSTx04_Piano_10.8x11.72mm_W7.62mm_P2.54mm | ~
 |  | SW2 | SW_DIP_x04 | Switch:SW_DIP_x04 | Button_Switch_THT:SW_DIP_SPSTx04_Piano_10.8x11.72mm_W7.62mm_P2.54mm | ~
 |  | U1 | Flexible Memory Decoder | Logic_Programmable:PAL20RS10 | Package_DIP:DIP-24_W7.62mm_Socket
Collated Components:
Item | Qty | Reference(s) | Value | LibPart | Footprint | Datasheet
1 | 1 | C1 | 0.1uF | Memory-Decoder-rescue:C-Device-65C02_Computer-rescue | Capacitor_THT:C_Disc_D3.4mm_W2.1mm_P2.50mm | ~
2 | 1 | J1 | IOCS/Decoder Signals Expansion #5 | Connector_Generic:Conn_02x05_Odd_Even | Connector_PinSocket_2.54mm:PinSocket_2x05_P2.54mm_Vertical | ~
3 | 1 | J2 | Conn_02x02_Odd_Even | Connector_Generic:Conn_02x02_Odd_Even | Connector_PinHeader_2.54mm:PinHeader_2x02_P2.54mm_Vertical | ~
4 | 1 | J3 | Decoder Signals | Connector_Generic:Conn_01x09 | Connector_PinSocket_2.54mm:PinSocket_1x09_P2.54mm_Vertical | ~
5 | 1 | J4 | Conn_02x03_Odd_Even | Connector_Generic:Conn_02x03_Odd_Even | Connector_PinSocket_2.54mm:PinSocket_2x03_P2.54mm_Vertical | ~
6 | 1 | J5 | Memory Decoder Expansion | Connector:Conn_01x06_Male | Connector_PinHeader_2.54mm:PinHeader_1x06_P2.54mm_Vertical | ~
7 | 1 | J6 | ~IOx | Connector_Generic:Conn_01x05 | Connector_PinSocket_2.54mm:PinSocket_1x05_P2.54mm_Vertical | ~
8 | 1 | J7 | ~IRQx | Connector_Generic:Conn_01x04 | Connector_PinSocket_2.54mm:PinSocket_1x04_P2.54mm_Vertical | ~
9 | 2 | SW1, SW2 | SW_DIP_x04 | Switch:SW_DIP_x04 | Button_Switch_THT:SW_DIP_SPSTx04_Piano_10.8x11.72mm_W7.62mm_P2.54mm | ~
10 | 1 | U1 | Flexible Memory Decoder | Logic_Programmable:PAL20RS10 | Package_DIP:DIP-24_W7.62mm_Socket

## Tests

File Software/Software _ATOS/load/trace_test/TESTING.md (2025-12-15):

# Trace Test - SMON Command Validation

## Intel HEX to Load

```hex
:10100000A200A9AA9D0002E8E010D0F8201510A9BE
:0B101000FF00EAEAEAA0048888600004
:00000001FF
```

## Program Disassembly

```
$1000: A2 00        LDX #$00           ; Initialize counter to 0
$1002: A9 AA        LDA #$AA           ; Load test pattern $AA
$1004: 9D 00 02     STA $0200,X        ; Store to memory [LOOP START]
$1007: E8           INX                ; Increment X
$1008: E0 10        CPX #$10           ; Compare with 16
$100A: D0 F8        BNE $1004          ; Loop back if X != 16
$100C: 20 15 10     JSR $1015          ; Call subroutine at $1015
$100F: A9 FF        LDA #$FF           ; Load final value $FF
$1011: 00           BRK                ; Return to monitor
$1012: EA           NOP                ; Padding
$1013: EA           NOP                ; Padding
$1014: EA           NOP                ; Padding
$1015: A0 04        LDY #$04           ; Subroutine: Load Y=4
$1017: 88           DEY                ; Y=3
$1018: 88           DEY                ; Y=2
$1019: 60           RTS                ; Return
```

---

## Test Procedure

### Load Program

```
> M
.L
:10100000A200A9AA9D0002E8E010D0F8201510A9BE
:0B101000FF00EAEAEAA0048888600004
:00000001FF
+++
```

### Verify Load

```
.M 1000 101A
:1000 A2 00 A9 AA 9D 00 02 E8  E0 10 D0 F8 20 15 10 A9         ........ .... ...
:1010 FF 00 EA EA EA A0 04 88  88 60 00                        ........ .`.

.D 1000 1019
,1000  A2 00     LDX #00
,1002  A9 AA     LDA #AA
,1004  9D 00 02  STA 0200,X
,1007  E8        INX
,1008  E0 10     CPX #10
,100A  D0 F8     BNE 1004
,100C  20 15 10  JSR 1015
,100F  A9 FF     LDA #FF
,1011  00        BRK
,1012  EA        NOP
,1013  EA        NOP
,1014  EA        NOP
,1015  A0 04     LDY #04
,1017  88        DEY
,1018  88        DEY
,1019  60        RTS
```

---

## Test 1: G Command (Run to BRK)

**Purpose:** Basic execution test - run program until BRK

**Status:** ✓ **WORKING**

```
.G 1000         ; Run from start

Expected output:
  PC  SR AC XR YR SP  NV-BDIZC
;1012 B1 FF 10 02 FD  10110001

Result: ✓ PASS
- PC=1012 (after BRK at $1011)
- A=FF (from LDA #$FF at $100F)
- X=10 (loop ran 16 times, 0→F, then incremented to 10)
- Y=02 (subroutine set Y=4, then DEY twice)
- SP=FD (decreased from FF)
```

---

## Test 2: TW (Trace Walk - Single Step with Keypress)

**Purpose:** Execute program ONE INSTRUCTION AT A TIME, waiting for keypress after each

**Expected Behavior:**
- Execute ONE instruction
- Display register state
- **WAIT for keypress:**
  - Press **any key** (SPACE, ENTER, etc.): Execute next instruction
  - Press **ESC**: Abort trace, return to monitor prompt
  - Press **J**: Execute current subroutine in real-time (if at JSR)

**Status:** ✓ **WORKING**

```
.TW 1000        ; Single-step from $1000

<WAIT FOR KEYPRESS>
(user presses key)
 1002 23 FF 00 02 FD  LDA #AA
Display: After LDX #$00 executed, X=00

<WAIT FOR KEYPRESS>
(user presses key)
 1004 A1 AA 00 02 FD  STA 0200,X
Display: After LDA #$AA executed, A=AA

<WAIT FOR KEYPRESS>
(user presses key)
 1007 A1 AA 00 02 FD  INX
Display: After STA executed, memory[$0200]=AA

<WAIT FOR KEYPRESS>
(user presses key)
 1008 21 AA 01 02 FD  CPX #10
Display: After INX executed, X=01

... (user continues pressing key through 16 loop iterations) ...

Loop iteration examples showing X incrementing:
 1004 A0 AA 01 02 FD  STA 0200,X    ; X=1
 1004 A0 AA 02 02 FD  STA 0200,X    ; X=2
 1004 A0 AA 03 02 FD  STA 0200,X    ; X=3
 ...
 1004 A0 AA 0F 02 FD  STA 0200,X    ; X=F (last iteration)

After loop completes:
 100A 23 AA 10 02 FD  BNE 1004      ; X=10, Z set, branch not taken
 100C 23 AA 10 02 FD  JSR 1015      ; About to call subroutine

Inside subroutine (if stepping through):
 1015 23 AA 10 02 FB  LDY #04       ; SP=FB (decreased from JSR)
 1017 21 AA 10 04 FB  DEY           ; Y=3
 1018 21 AA 10 03 FB  DEY           ; Y=2
 1019 21 AA 10 02 FB  RTS           ; Return

After subroutine:
 100F 21 AA 10 02 FD  LDA #FF       ; SP=FD (restored)
 1011 A1 FF 10 02 FD  BRK           ; Final instruction

  PC  SR AC XR YR SP  NV-BDIZC
;1013 B1 FF 10 02 FD  10110001
```

**Result:** ✓ PASS - TW correctly waits for keypress after each instruction

**Key Features Verified:**
- ✓ Executes one instruction per keypress
- ✓ Displays register state after each instruction
- ✓ Shows loop iterations clearly (X incrementing 0→10)
- ✓ Shows JSR/RTS with SP changes (FF→FB→FD)
- ✓ Can step through entire program instruction-by-instruction (73 instructions total)
- ⚠️ ESC abort (needs testing)
- ⚠️ J (jump over subroutine) (needs testing)

---

## Test 3: TB (Trace Breakpoint) + TQ (Trace Quick)

**Purpose:** Set breakpoint with hit count, run at full speed, break into single-step mode

**How it works:**
1. **TB xxxx yy** - Set breakpoint at address xxxx, trigger after (yy+1) hits
2. **TQ xxxx** - Run from xxxx at full speed
3. When breakpoint triggers, switches to TW single-step mode (waits for keypress)

**Status:** ✓ **WORKING**

### Test Case 1: Break on 15th loop iteration (TB 1004 0E)

```
.TB 1004 0E     ; Break on (14+1)=15th hit at $1004
.TQ 1000        ; Run from $1000 at full speed

Actual output:
 1004 A0 AA 0E 02 FD  STA 0200,X    ; X=0E (14th iteration completed)
 1007 A0 AA 0E 02 FD  INX           ; X becomes 0F
 1008 20 AA 0F 02 FD  CPX #10       ; Compare X=0F with 16
 100A A0 AA 0F 02 FD  BNE 1004      ; Branch back (15th iteration)
 1004 A0 AA 0F 02 FD  STA 0200,X    ; 15th hit! Breakpoint triggered
 1007 A0 AA 0F 02 FD  INX           ; Now in single-step mode
 1008 20 AA 10 02 FD  CPX #10       ; X=10, loop done
 100A 23 AA 10 02 FD  BNE 1004      ; Don't branch (Z set)
 100C 23 AA 10 02 FD  JSR 1015      ; Call subroutine
 1015 23 AA 10 02 FB  LDY #04       ; SP=FB
 1017 21 AA 10 04 FB  DEY           ; Y=3
 1018 21 AA 10 03 FB  DEY           ; Y=2
 1019 21 AA 10 02 FB  RTS           ; Return
 100F 21 AA 10 02 FD  LDA #FF       ; SP=FD
 1011 A1 FF 10 02 FD  BRK           ; Break

  PC  SR AC XR YR SP  NV-BDIZC
;1013 B1 FF 10 02 FD  10110001
```

**Result:** ✓ PASS
- Runs first 14 iterations at full speed (no output)
- Hits breakpoint on 15th iteration at $1004 when X=0F
- Switches to TW single-step mode
- User presses keys to step through remaining instructions
- Shows complete execution from breakpoint to BRK

### Test Case 2: Break on 11th loop iteration (TB 1004 0A)

```
.TB 1004 0A     ; Break on (10+1)=11th hit at $1004
.TQ 1000        ; Run from $1000 at full speed

Actual output:
 1004 A0 AA 0A 02 FD  STA 0200,X    ; 11th hit! X=0A (10)
 1007 A0 AA 0A 02 FD  INX           ; Single-step mode
 1008 20 AA 0B 02 FD  CPX #10       ; X=0B
 100A A0 AA 0B 02 FD  BNE 1004      ; Branch back
 1004 A0 AA 0B 02 FD  STA 0200,X    ; X=0B
 1007 A0 AA 0B 02 FD  INX           ; X=0C
 1008 20 AA 0C 02 FD  CPX #10
 100A A0 AA 0C 02 FD  BNE 1004
 1004 A0 AA 0C 02 FD  STA 0200,X    ; X=0C
 1007 A0 AA 0C 02 FD  INX           ; X=0D
 1008 20 AA 0D 02 FD  CPX #10
 100A A0 AA 0D 02 FD  BNE 1004
 1004 A0 AA 0D 02 FD  STA 0200,X    ; X=0D
 1007 A0 AA 0D 02 FD  INX           ; X=0E
 1008 20 AA 0E 02 FD  CPX #10
 100A A0 AA 0E 02 FD  BNE 1004
 1004 A0 AA 0E 02 FD  STA 0200,X    ; X=0E
 1007 A0 AA 0E 02 FD  INX           ; X=0F
 1008 20 AA 0F 02 FD  CPX #10
 100A A0 AA 0F 02 FD  BNE 1004
 1004 A0 AA 0F 02 FD  STA 0200,X    ; X=0F (last iteration)
 1007 A0 AA 0F 02 FD  INX           ; X=10
 1008 20 AA 10 02 FD  CPX #10       ; Equal!
 100A 23 AA 10 02 FD  BNE 1004      ; Don't branch
 100C 23 AA 10 02 FD  JSR 1015      ; Call subroutine
 1015 23 AA 10 02 FB  LDY #04
 1017 21 AA 10 04 FB  DEY
 1018 21 AA 10 03 FB  DEY
 1019 21 AA 10 02 FB  RTS
 100F 21 AA 10 02 FD  LDA #FF
 1011 A1 FF 10 02 FD  BRK

  PC  SR AC XR YR SP  NV-BDIZC
;1013 B1 FF 10 02 FD  10110001
```

**Result:** ✓ PASS
- Runs first 10 iterations at full speed (no output)
- Hits breakpoint on 11th iteration at $1004 when X=0A
- Switches to TW single-step mode
- Shows remaining 6 loop iterations (X=0A through 0F)
- User presses keys to step through to completion

**Key Features Verified:**
- ✓ TB sets breakpoint with correct hit count
- ✓ TQ runs at full speed until breakpoint
- ✓ Breakpoint triggers at exact iteration (yy+1)
- ✓ Automatically switches to TW single-step mode
- ✓ User can step through remaining code after breakpoint
- ✓ Shows complete register state at each step

---

## Test 4: TS (Trace Stop - Run Until Address)

**Purpose:** Run at full speed from xxxx until PC reaches yyyy, then display registers

**Status:** ✓ **WORKING**

### Test Case 1: Stop at loop start (TS 1000 1004)

```
.TS 1000 1004   ; Run from $1000 until PC=$1004

  PC  SR AC XR YR SP  NV-BDIZC
;1004 B0 AA 00 02 FD  10110000

Result: ✓ PASS
- Stopped at $1004 (loop start)
- A=AA (loaded by LDA #$AA)
- X=00 (initialized by LDX #$00)
- Executed: LDX #$00, LDA #$AA
```

### Test Case 2: Stop at branch decision (TS 1004 100A)

```
.TS 1004 100A   ; Run from $1004 until PC=$100A

  PC  SR AC XR YR SP  NV-BDIZC
;100A B0 AA 01 02 FD  10110000

Result: ✓ PASS
- Stopped at $100A (BNE instruction)
- X=01 (incremented once)
- Executed: STA $0200,X, INX, CPX #10
```

### Test Case 3: Stop at BRK (TS 1000 1011)

```
.TS 1000 1011   ; Run from $1000 until PC=$1011 (BRK)

  PC  SR AC XR YR SP  NV-BDIZC
;1011 B1 FF 10 02 FD  10110001

Result: ✓ PASS
- Stopped at $1011 (BRK instruction)
- A=FF (from LDA #$FF)
- X=10 (loop completed 16 iterations)
- Y=02 (subroutine executed: LDY #$04, DEY, DEY)
- Complete program execution verified
```

**Key Features Verified:**
- ✓ Runs at full speed from start to stop address (silent)
- ✓ Stops exactly when PC reaches target address
- ✓ Displays register state at stop point
- ✓ Can be used to skip to any address in program
- ✓ Perfect for skipping known-good code sections

---

## Test 5: Memory Verification

**Purpose:** Verify loop wrote to memory

```
.M 0200 020F
:0200 AA AA AA AA AA AA AA AA  AA AA AA AA AA AA AA AA
Expected: 16 bytes of $AA at $0200-$020F
```

**Result:** ✓ PASS if all 16 bytes are $AA

---

## Test 6: G Command (Run to BRK)

**Purpose:** Basic execution test

```
.G 1000         ; Run from start

Hello World from SMON!

  PC  SR AC XR YR SP  NV-BDIZC
;1011 34 FF 10 02 FB  00110100
Expected: PC=1011 (at BRK), A=FF, X=10, Y=02
```

**Result:** ✓ PASS if stops at BRK with correct registers

---

## Summary of Test Results

| Test | Command | Expected Behavior | Actual Result | Status |
|---|---|---|---|---|
| **Test 1** | **G xxxx** | Run to BRK at full speed | Runs to BRK correctly | ✓ **PASS** |
| **Test 2** | **TW xxxx** | Single-step, wait for keypress | Waits for keypress | ✓ **PASS** |
| **Test 3** | **TB/TQ xxxx** | Set breakpoint, run, switch to single-step | Works perfectly | ✓ **PASS** |
| **Test 4** | **TS xxxx yyyy** | Run until address yyyy | Stops at target address | ✓ **PASS** |
| **Test 5** | **M xxxx yyyy** | Display memory | Works | ✓ **PASS** |
| **Test 6** | **D xxxx yyyy** | Disassemble | Works | ✓ **PASS** |

### Working Trace Commands - All Verified! ✓

✓ **G xxxx** - Run to BRK at full speed  
✓ **TW xxxx** - Single-step with keypress (ESC aborts, J skips subroutines)  
✓ **TB xxxx yy** - Set breakpoint with hit count (triggers after yy+1 hits)  
✓ **TQ xxxx** - Run to breakpoint at full speed, then switch to single-step  
✓ **TS xxxx yyyy** - Run from xxxx until PC reaches yyyy (silent, fast)

---

## Memory Map

- **$1000-$1019**: Program code (26 bytes)
- **$0200-$020F**: Loop writes $AA here (16 bytes)
- **Stack**: Grows down from $01FF (SP starts at $FF)

## Key Findings

✓ **ALL trace commands work perfectly!**  
✓ **TW** - Single-steps with keypress wait, shows register state after each instruction  
✓ **TB/TQ** - Breakpoints with hit counts, seamless switch to single-step mode  
✓ **TS** - Fast execution to specific address, perfect for skipping code sections  
✓ **VIA timer fully functional** - Required for TB/TQ/TS breakpoint/address monitoring  
✓ **G command reliable** - Fast execution to BRK

## Recommended Debugging Workflow

1. **Quick test**: Use `G 1000` to verify program runs correctly
2. **Skip to problem area**: Use `TS 1000 xxxx` to jump to specific address
3. **Break at iteration**: Use `TB xxxx yy` to break at specific loop iteration, then single-step
4. **Detailed debug**: Use `TW 1000` to see every instruction from start
5. **Check results**: Use `M xxxx yyyy` to verify memory, `R` for registers

## Quick Reference

| Command | Purpose | Example | Notes |
|---|---|---|---|
| **G xxxx** | Run to BRK (fast) | G 1000 | Silent execution |
| **TW xxxx** | Single-step mode | TW 1000 | Press key to advance, ESC to abort |
| **TB xxxx yy** | Set breakpoint | TB 1004 0E | Break on (yy+1)th hit |
| **TQ xxxx** | Run to breakpoint | TQ 1000 | Runs fast until breakpoint |
| **TS xxxx yyyy** | Run until address | TS 1000 100C | Silent, stops at yyyy |
| **M xxxx yyyy** | Display memory | M 1000 101A | Shows hex dump |
| **D xxxx yyyy** | Disassemble | D 1000 1019 | Shows assembly |
| **R** | Display registers | R | Current CPU state |
| **X** | Exit to shell | X | Leave monitor |

---

## Practical Example: Debugging lcd_hello Program

This example shows how to use trace commands with a real program that prints 4 lines to the LCD.

### Program Structure (lcd_hello.load.hex)

```assembly
$1000: JSR $104C          ; LCD init
$1003: LDA #$80           ; Line 1 position
$1005: JSR $10BA          ; Set cursor
$1008-$1014: Print "Line 1: Hello" (loop)
$1015: LDA #$C0           ; Line 2 position
$1017: JSR $10BA          ; Set cursor
$101A-$1026: Print "Line 2: World" (loop)
$1027: LDA #$94           ; Line 3 position
$1029: JSR $10BA          ; Set cursor
$102C-$1038: Print "Line 3: Test!" (loop)
$1039: LDA #$D4           ; Line 4 position
$103B: JSR $10BA          ; Set cursor
$103E-$104A: Print "Line 4: Done!" (loop)
$104B: BRK                ; End
```

### Use Case: Test LCD After First 2 Lines

**Goal:** Check LCD display after printing Lines 1 and 2 (halfway point)

```
> M
.L
:10100000204C10A98020BA10A200BD5611F0062075
:10101000C410E8D0F5A9C020BA10A200BD6411F038
:101020000620C410E8D0F5A99420BA10A200BD7221
:1010300011F00620C410E8D0F5A9D420BA10A200FF
:10104000BD8011F00620C410E8D0F500AD02900973
:10105000FE8D0290A964204C11A930209B10A90597
:10106000204C11A930209B10A901204C11A930203F
:101070009B10A901204C11A920209B10A901204CF4
:1010800011A92820BA10A90C20BA10A90120BA1061
:10109000A902204C11A90620BA106048AD00902981
:1010A0000185206829F005208D009009088D0090A9
:1010B000EAEAEAEA49088D0090601820C910A901FF
:1010C000204C11603820C910604808201A11286887
:1010D0008522B006A90085218004A9028521AD00E2
:1010E00090290105218521AD029009FE8D0290A570
:1010F0002229F005218D009009088D009049088D66
:101100000090A522290F0A0A0A0A05218D009009DC
:10111000088D009049088D009060AD02902901096A
:101120000E8D0290AD0090290109048D00900908F0
:101130008D0090AD0090852349088D009009088DA1
:10114000009049088D0090A52330D960AAA0FA88A4
:10115000D0FDCAD0F8604C696E6520313A204865F0
:101160006C6C6F004C696E6520323A20576F726C60
:1011700064004C696E6520333A2054657374210015
:0E1180004C696E6520343A20446F6E65210084
:00000001FF
+++

.TB 1027 00     ; Breakpoint at Line 3 start (after Line 1+2 printed)
.TQ 1000        ; Run from start (VIA steps through, takes ~30 seconds)

<Wait for VIA to step through instructions>
<VIA monitors PC at each step>
<Eventually reaches $1027>

 1027 ... ... .. .. ..  LDA #94        ; Breakpoint hit!

<Check LCD now shows:>
┌────────────────────┐
│Line 1: Hello       │
│Line 2: World       │
│                    │  <-- Lines 3 & 4 not printed yet
│                    │
└────────────────────┘

Options from here:
1. Press ESC to return to monitor (LCD stays as-is)
2. Press keys to single-step through Line 3 character-by-character (~50 keypresses)
3. Press ESC, then G to complete at full speed
```

### Performance Notes

**TQ with VIA Stepping:**
- VIA timer steps through each instruction checking for breakpoint
- Takes time (~30 seconds for 200+ instructions to reach $1027)
- No keypresses needed - runs automatically
- **After breakpoint hits**, switches to TW single-step mode (requires keypresses)

**Fast Alternative (No Breakpoint Check):**
```
.TS 1000 1027   ; Run until $1027 (VIA monitors, ~30 seconds)
                ; Stops at $1027, shows registers
                ; Back at monitor prompt (no single-step mode)
```

**Fastest (No Monitoring):**
```
.G 1000         ; Run to completion at full CPU speed
                ; No VIA monitoring overhead
                ; Shows all 4 lines instantly
```

### Other Useful Breakpoints for lcd_hello

```
.TB 1003 00     ; After LCD init, before any printing
.TB 1015 00     ; After Line 1 printed
.TB 1027 00     ; After Lines 1+2 printed (halfway)
.TB 1039 00     ; After Lines 1+2+3 printed
.TB 104B 00     ; At BRK (all 4 lines printed)
```

### Speed Comparison

| Method | Speed | Monitoring | LCD Check Points |
|---|---|---|---|
| **G 1000** | ⚡ Instant | None | End only (all 4 lines) |
| **TS 1000 1027** | 🐌 ~30s | VIA checks PC | At $1027 (2 lines) |
| **TB/TQ** | 🐌 ~30s + keypresses | VIA checks PC + hit count | At breakpoint + single-step |
| **TW 1000** | 👆 100s+ of keypresses | VIA steps + keypress | Every instruction |

**Recommendation:** Use **TS** for checkpoints without debugging, **TB/TQ** when you need to debug after the checkpoint.

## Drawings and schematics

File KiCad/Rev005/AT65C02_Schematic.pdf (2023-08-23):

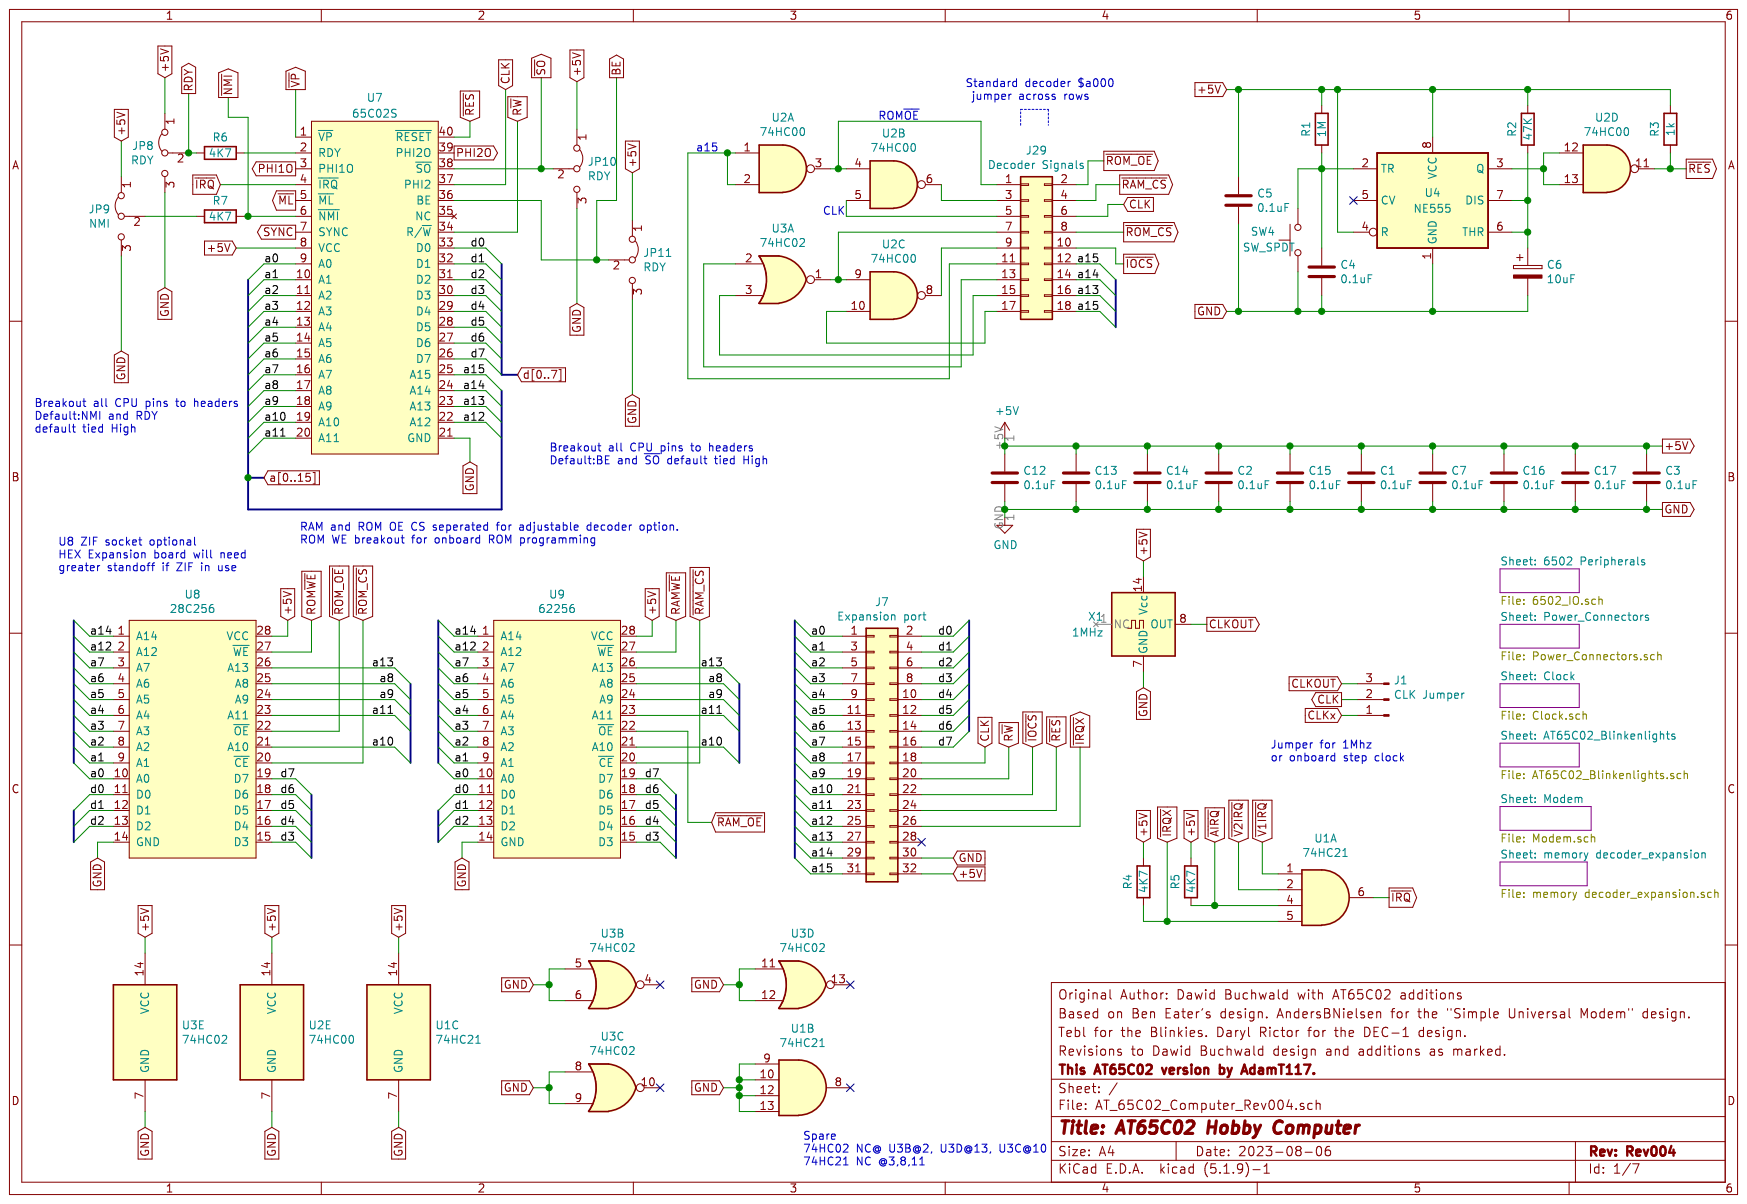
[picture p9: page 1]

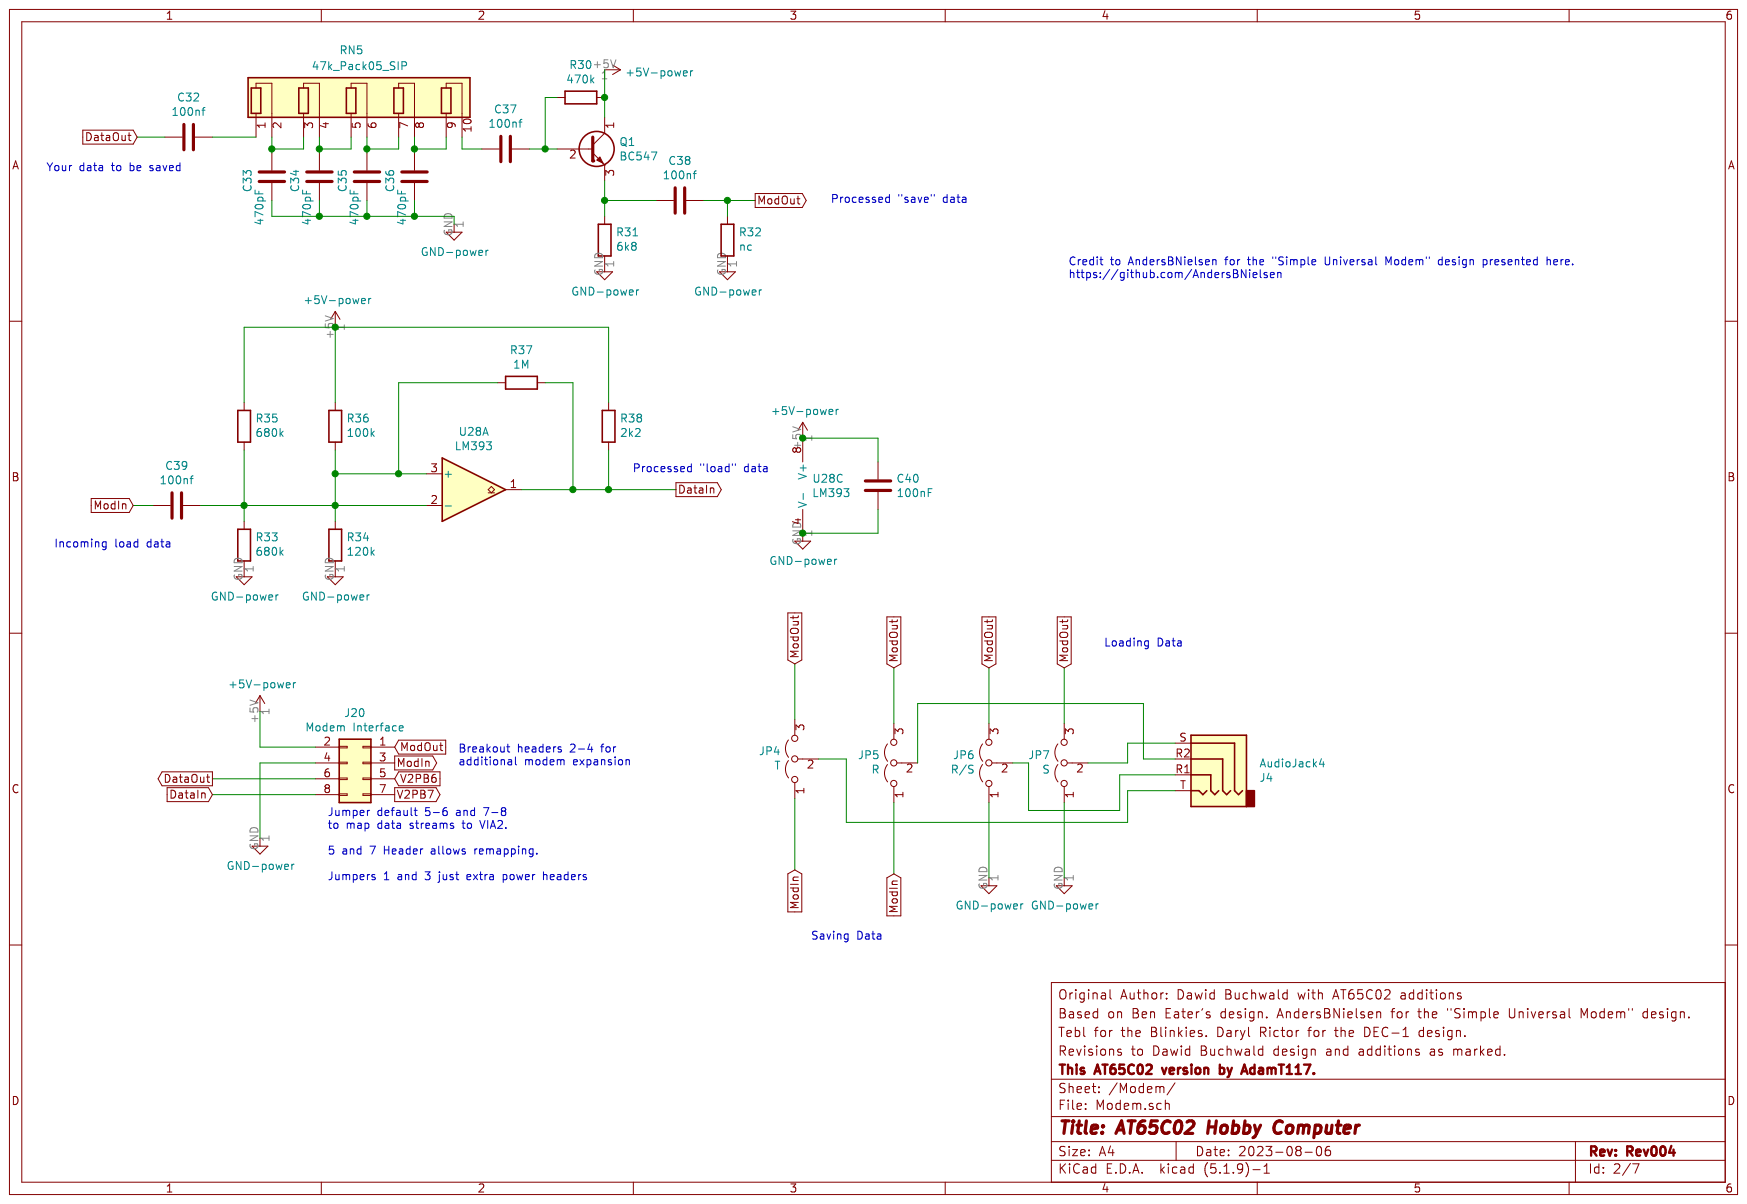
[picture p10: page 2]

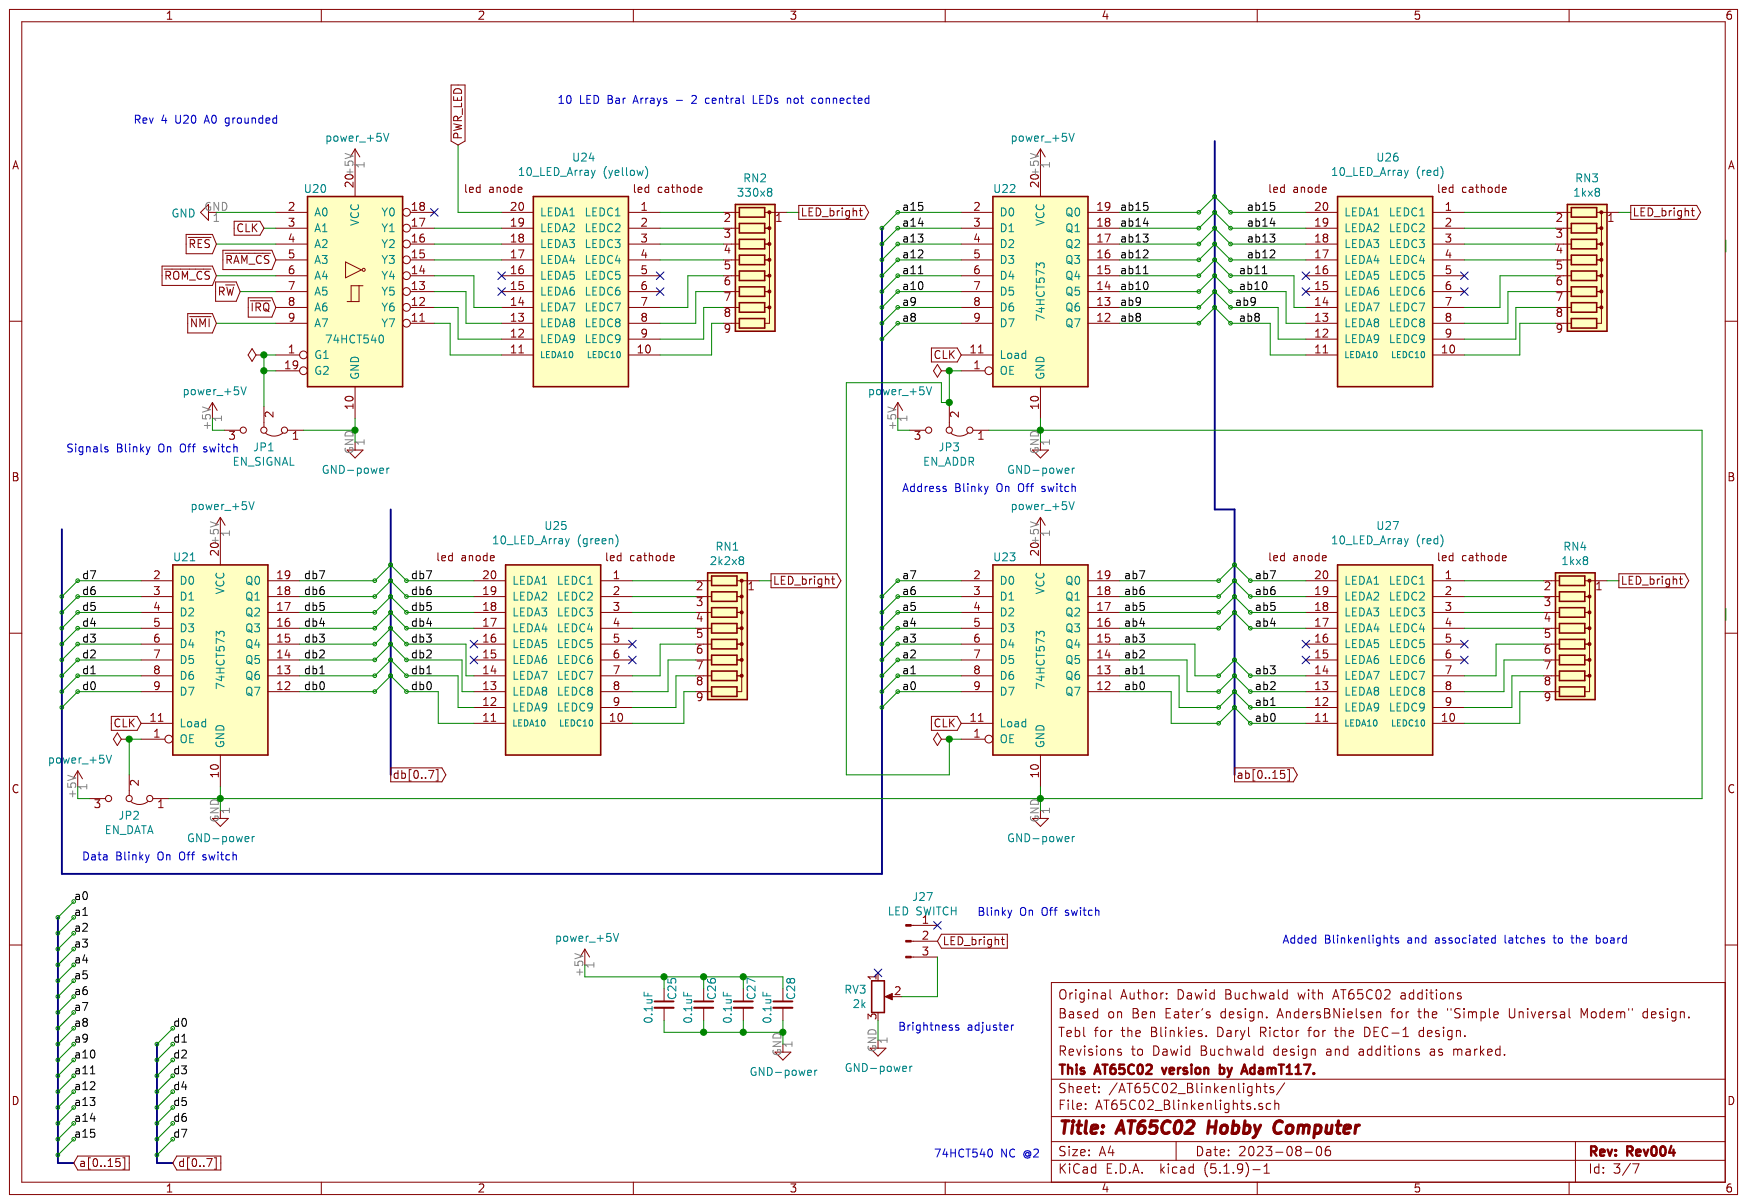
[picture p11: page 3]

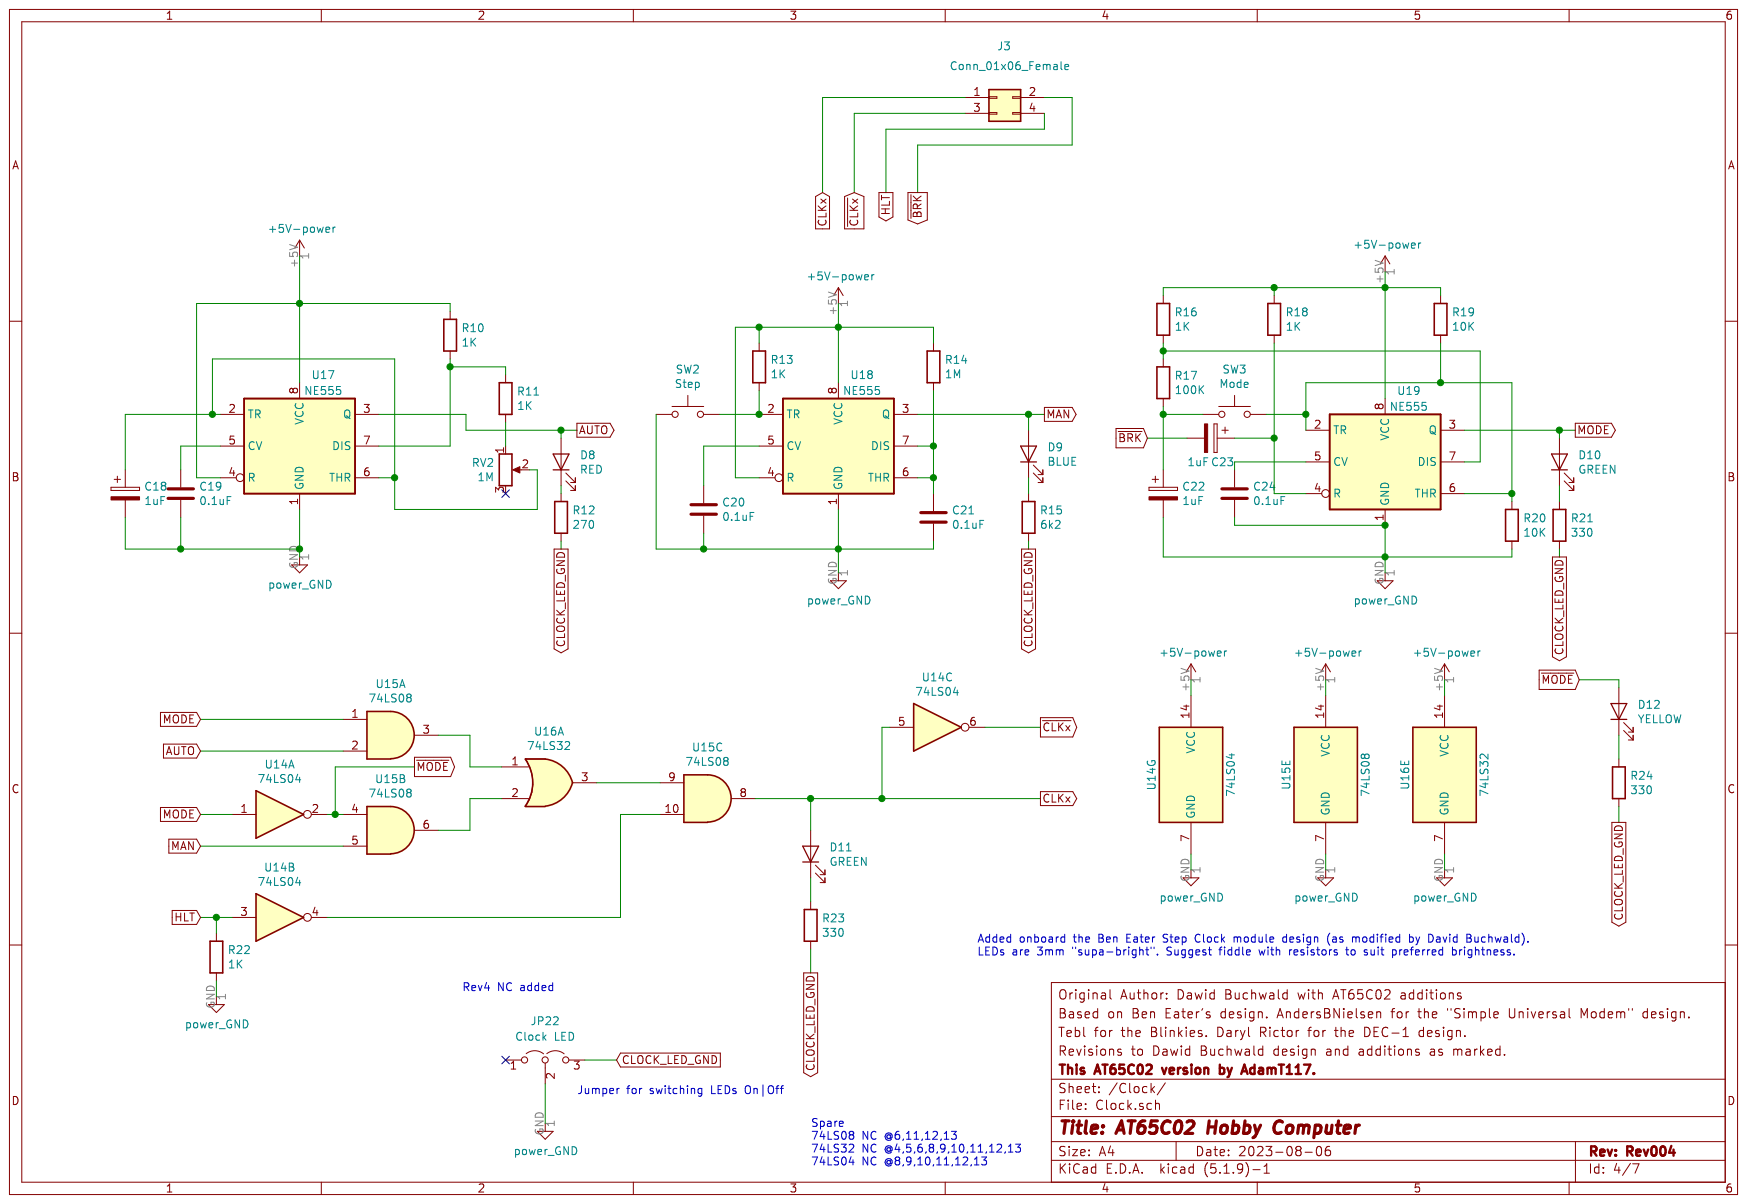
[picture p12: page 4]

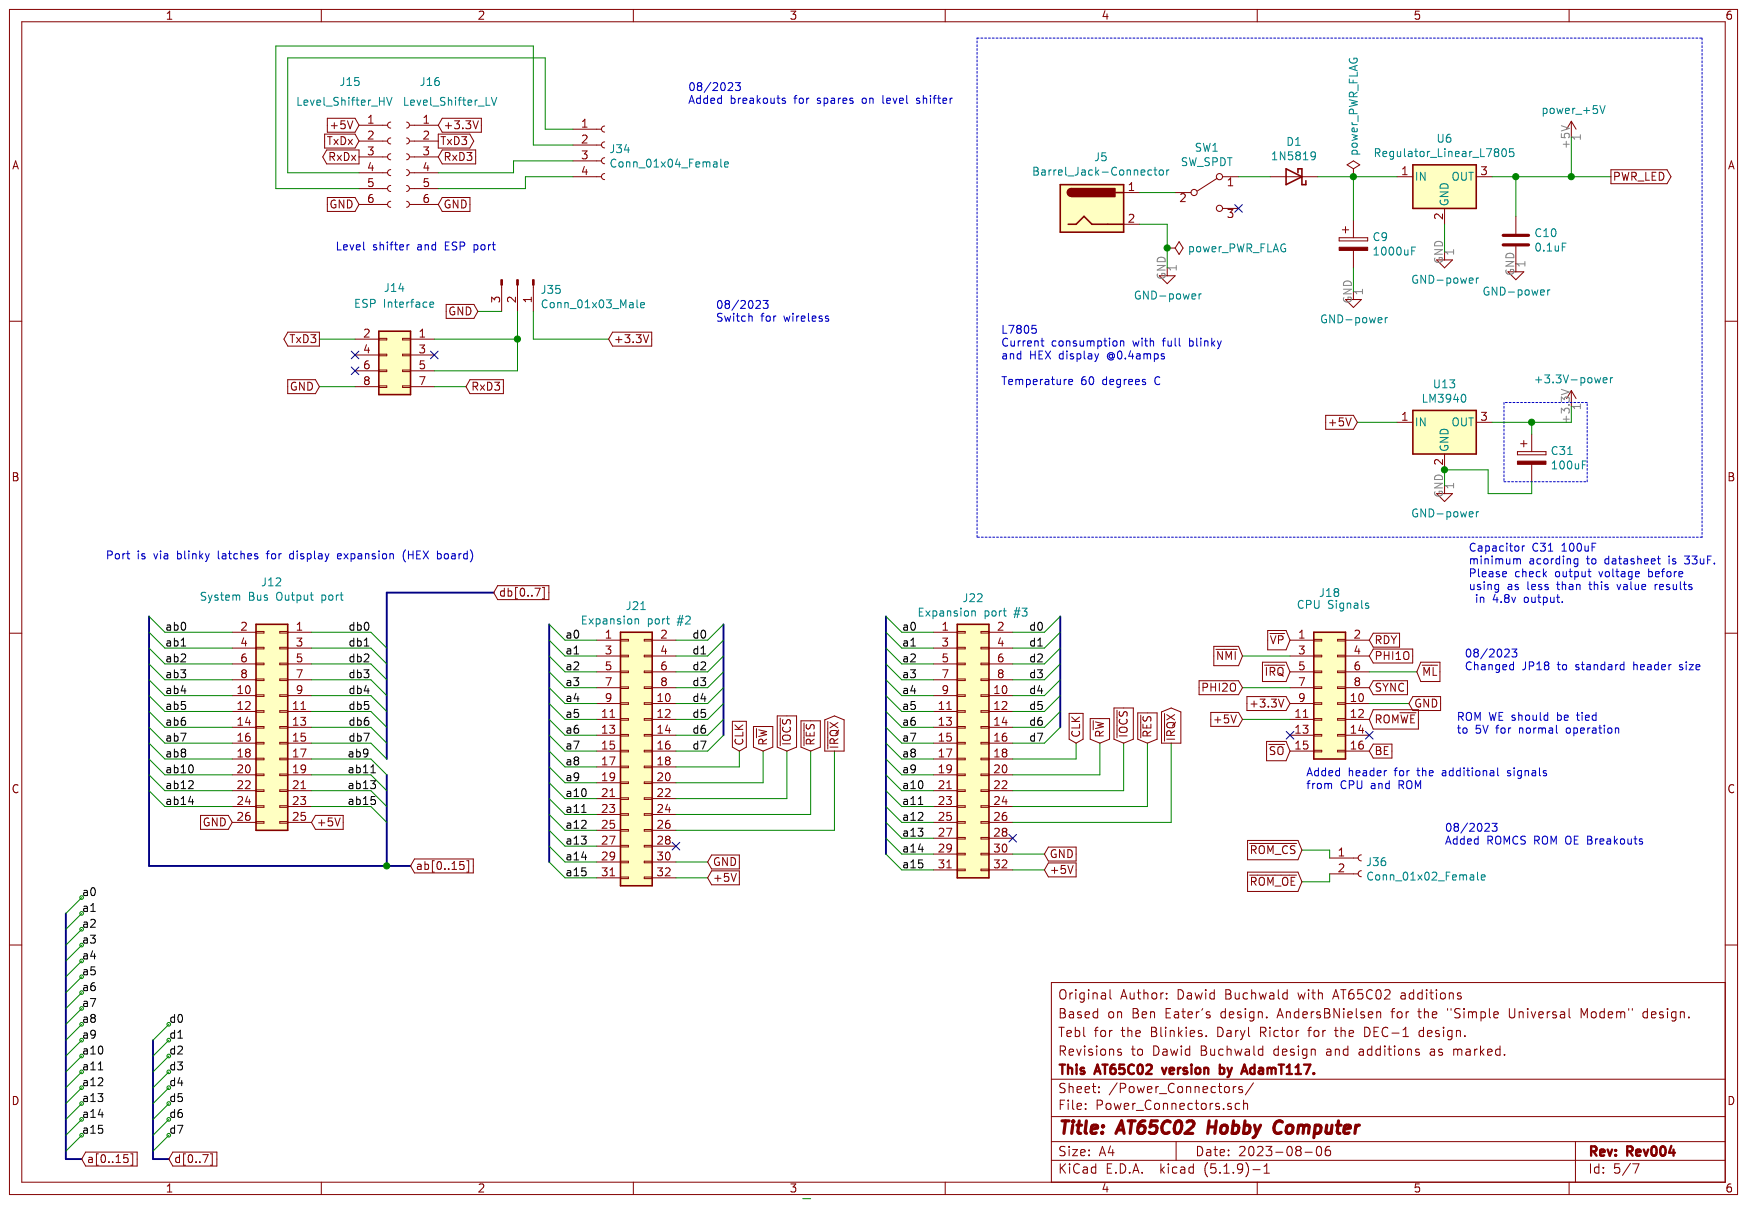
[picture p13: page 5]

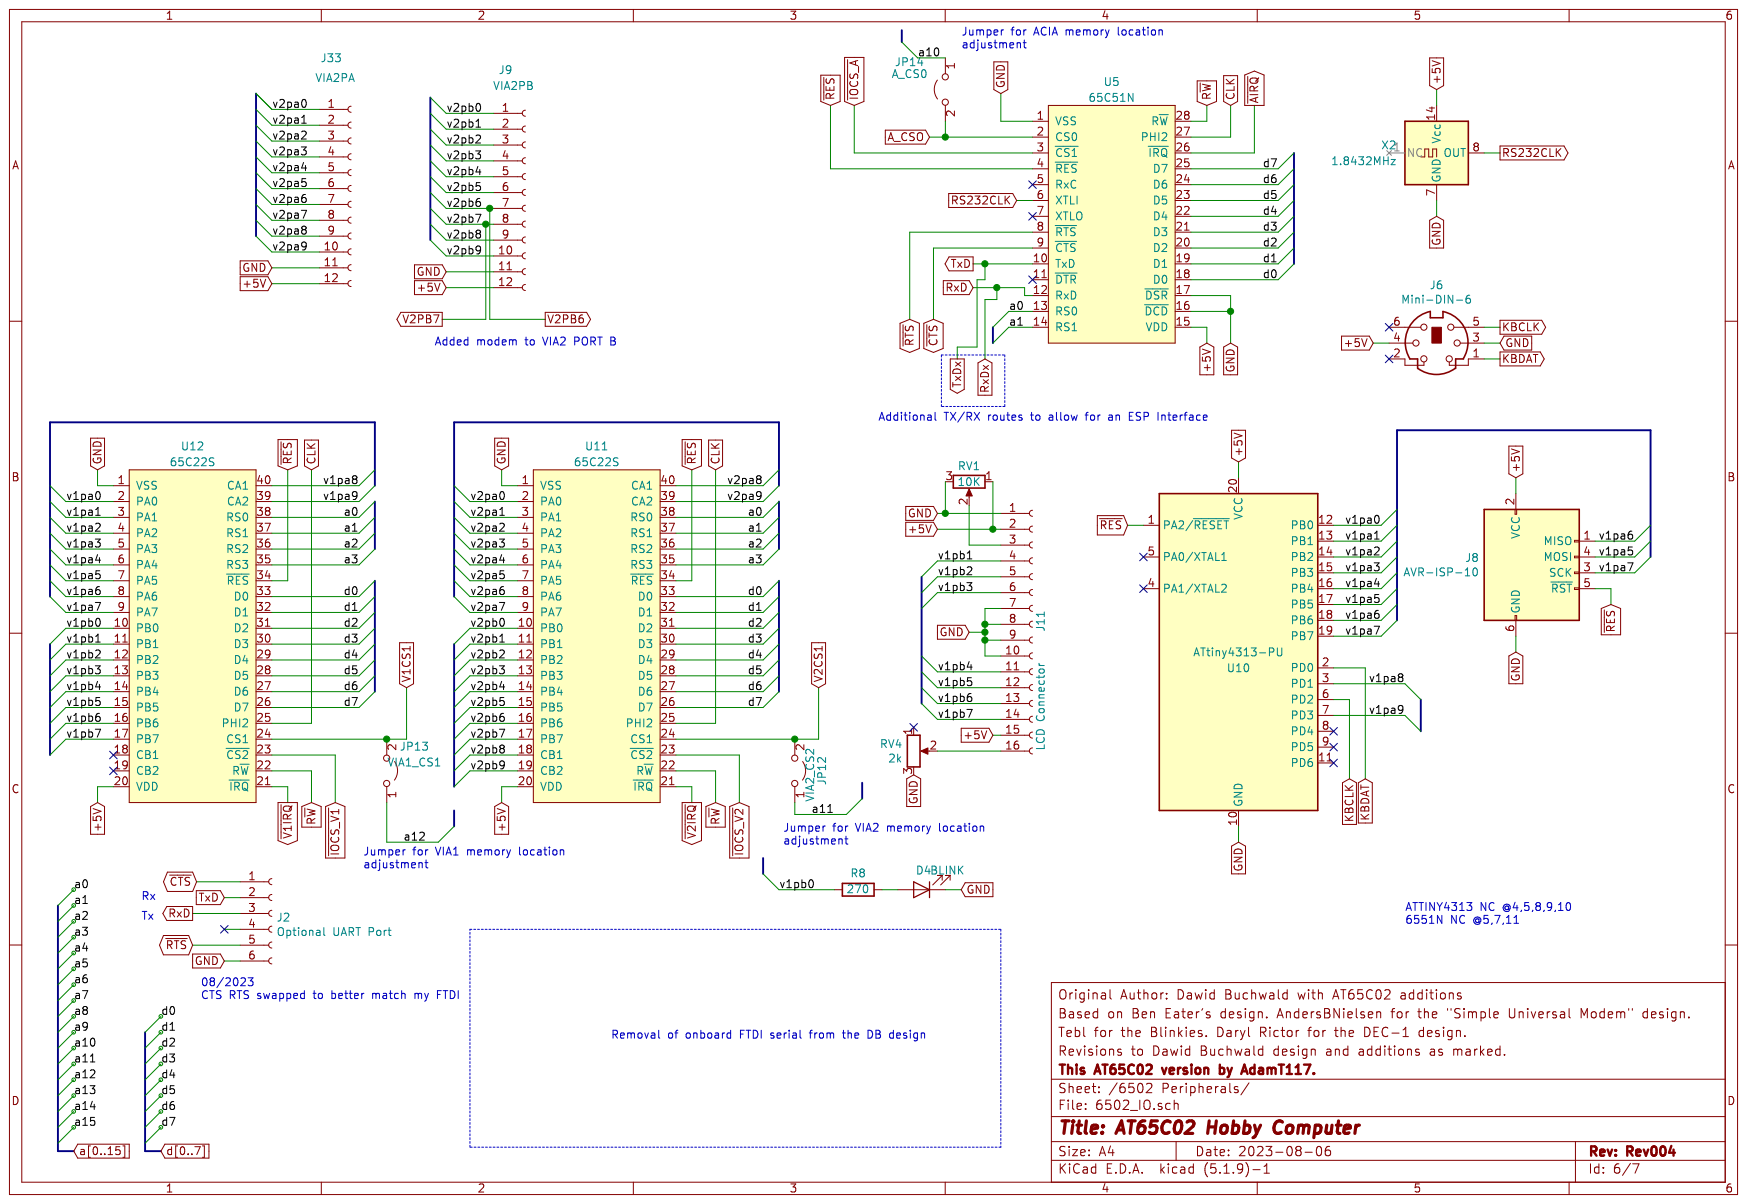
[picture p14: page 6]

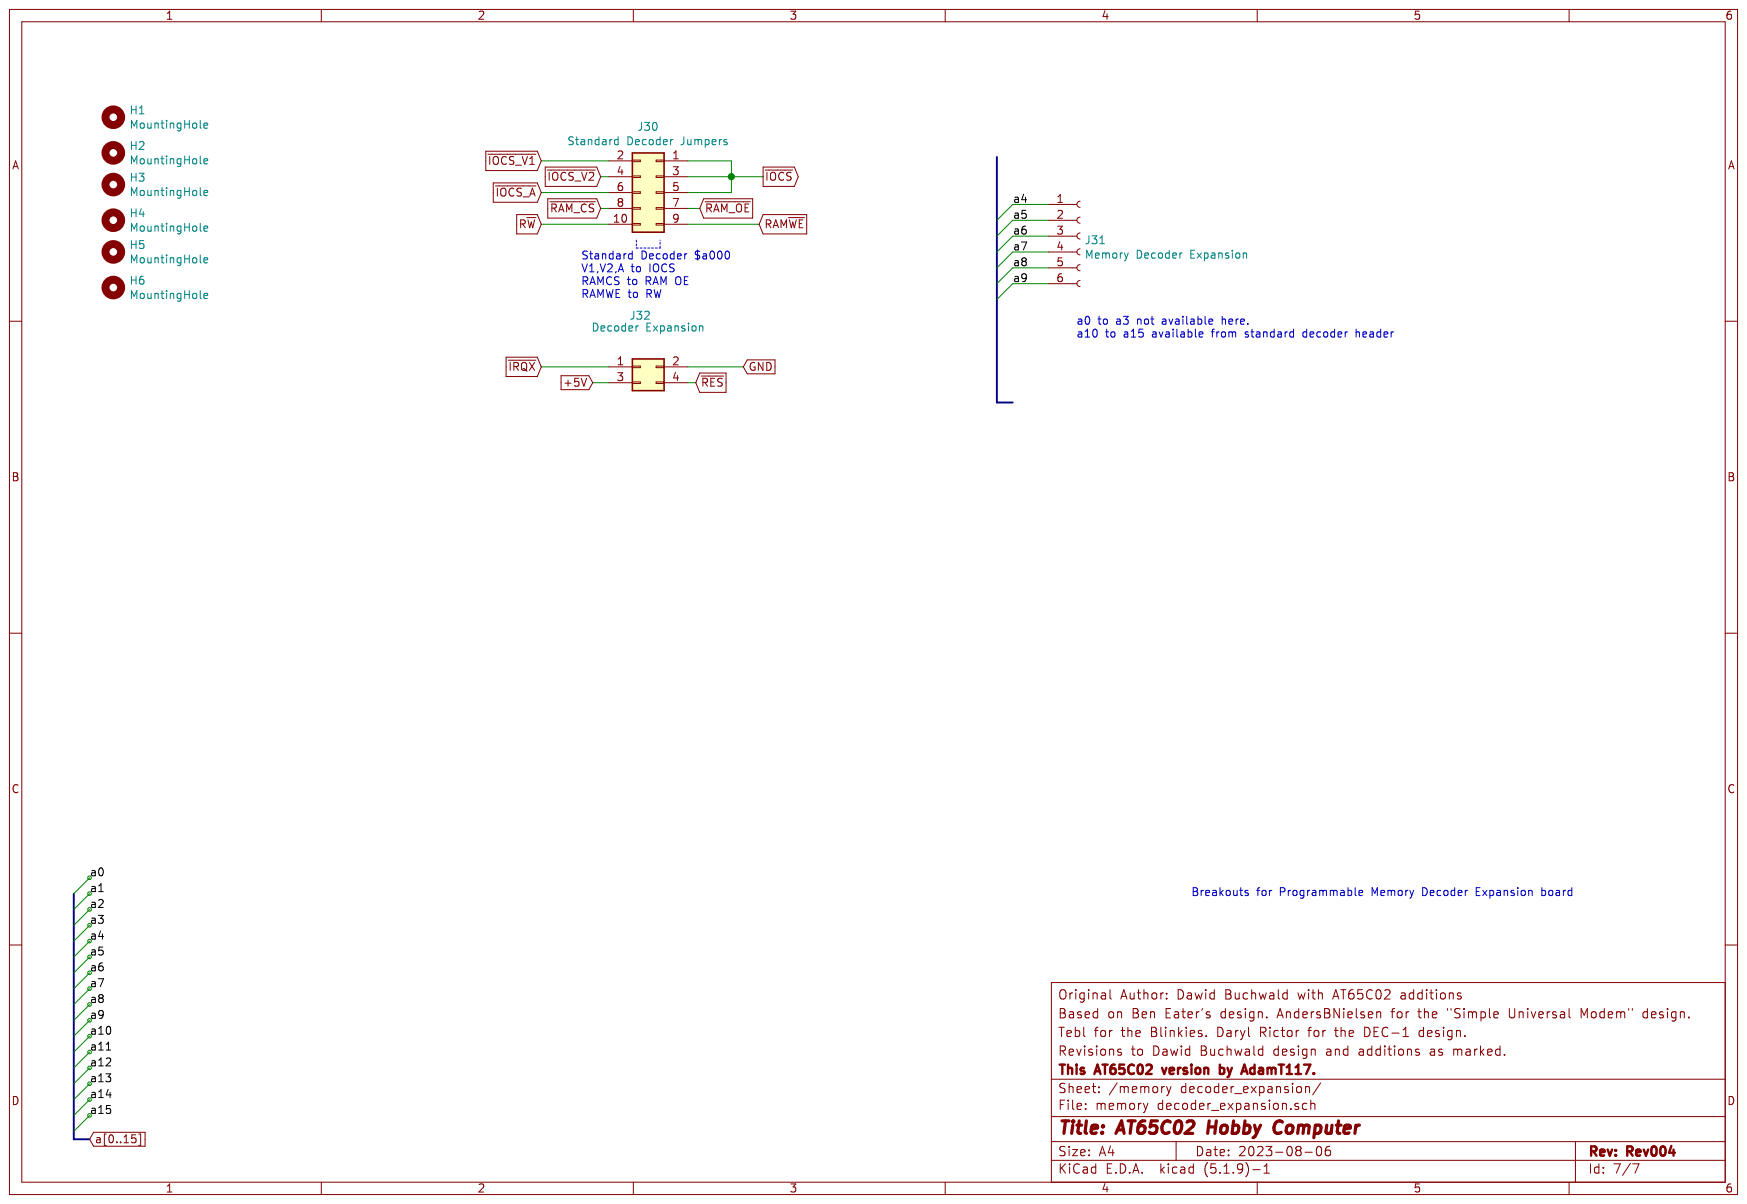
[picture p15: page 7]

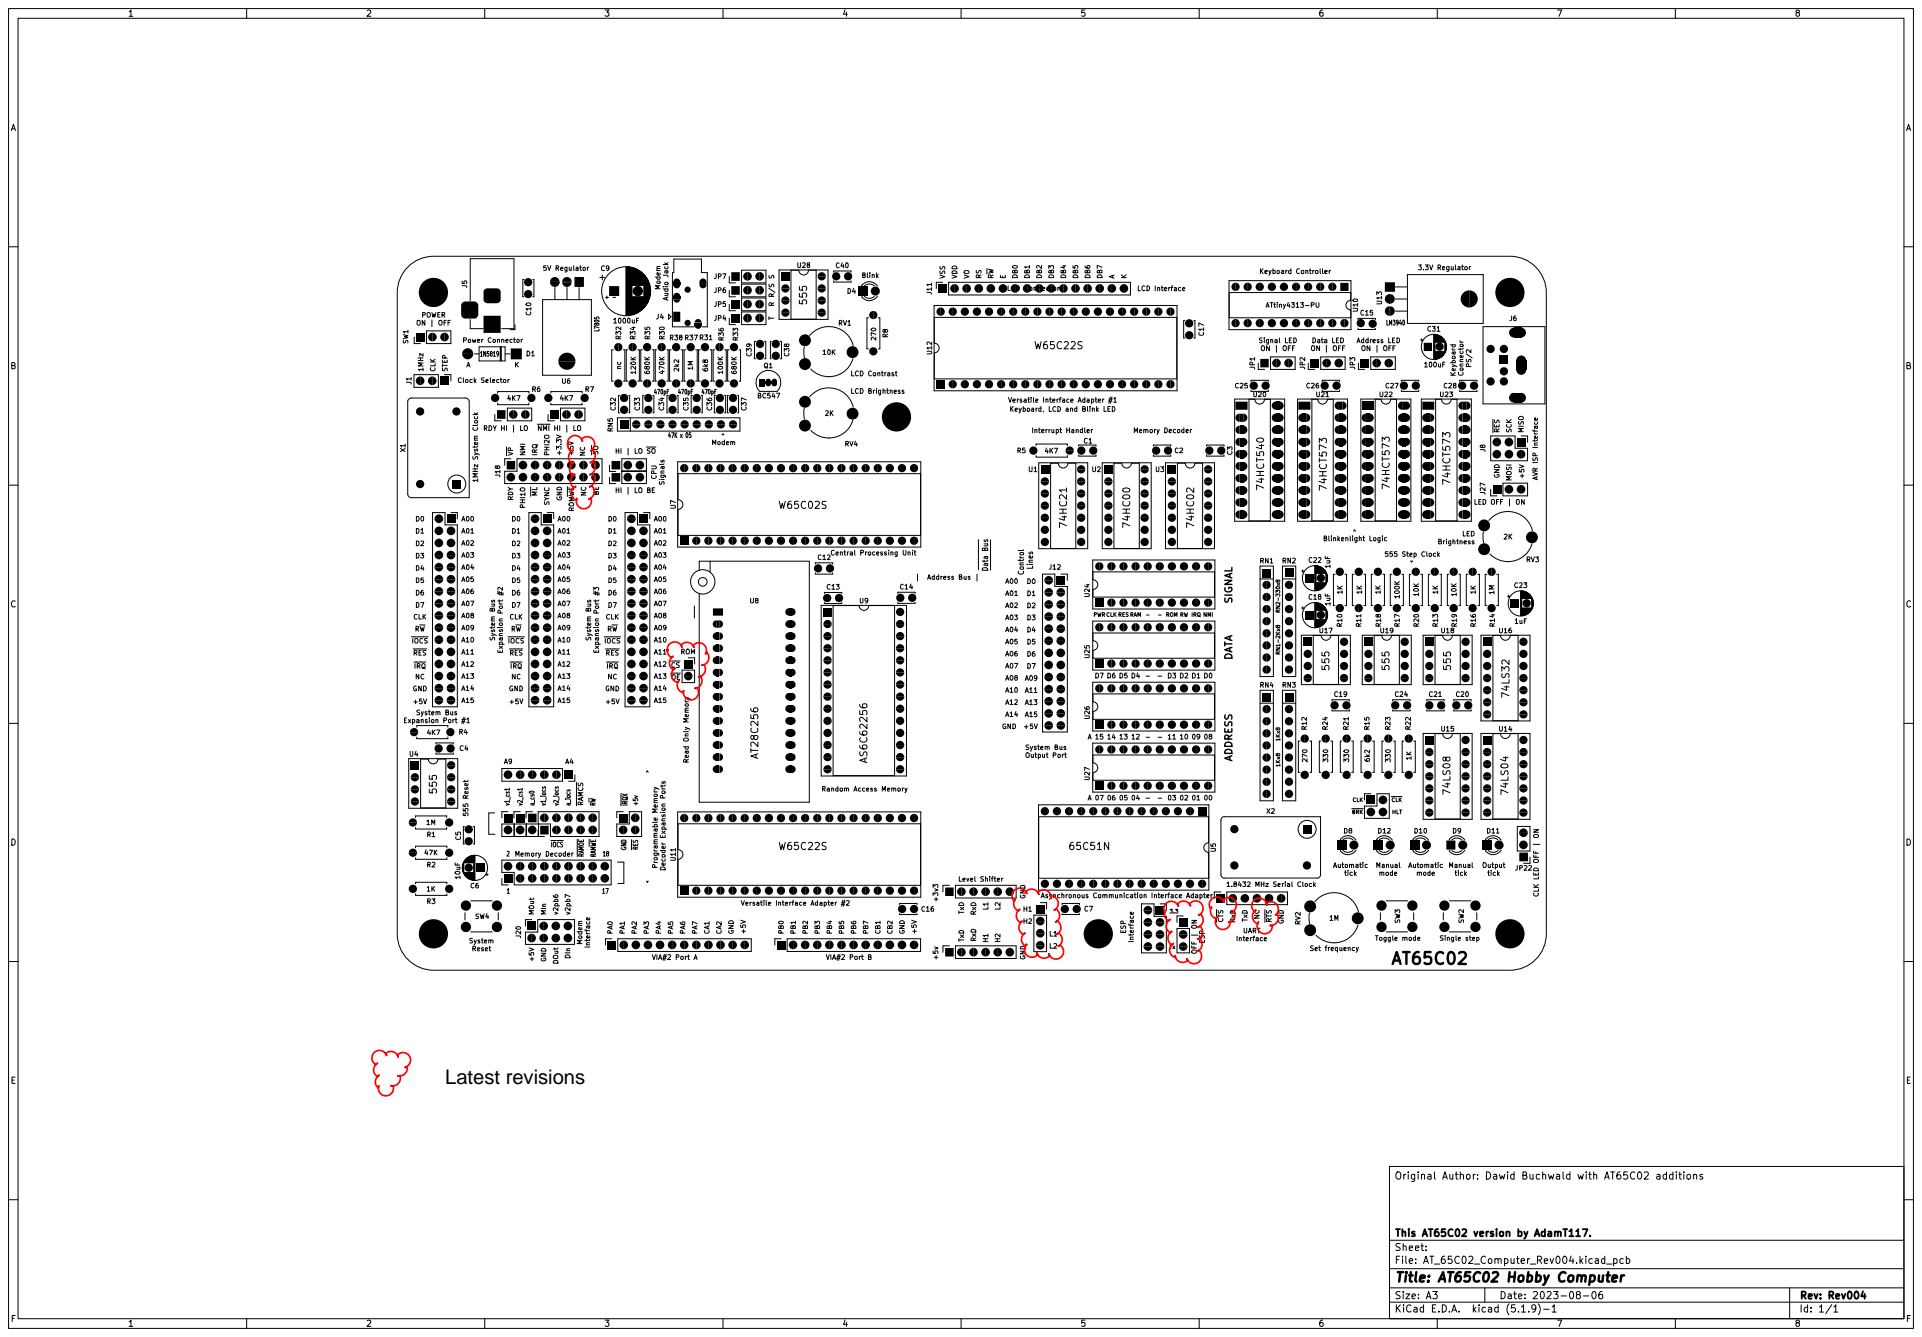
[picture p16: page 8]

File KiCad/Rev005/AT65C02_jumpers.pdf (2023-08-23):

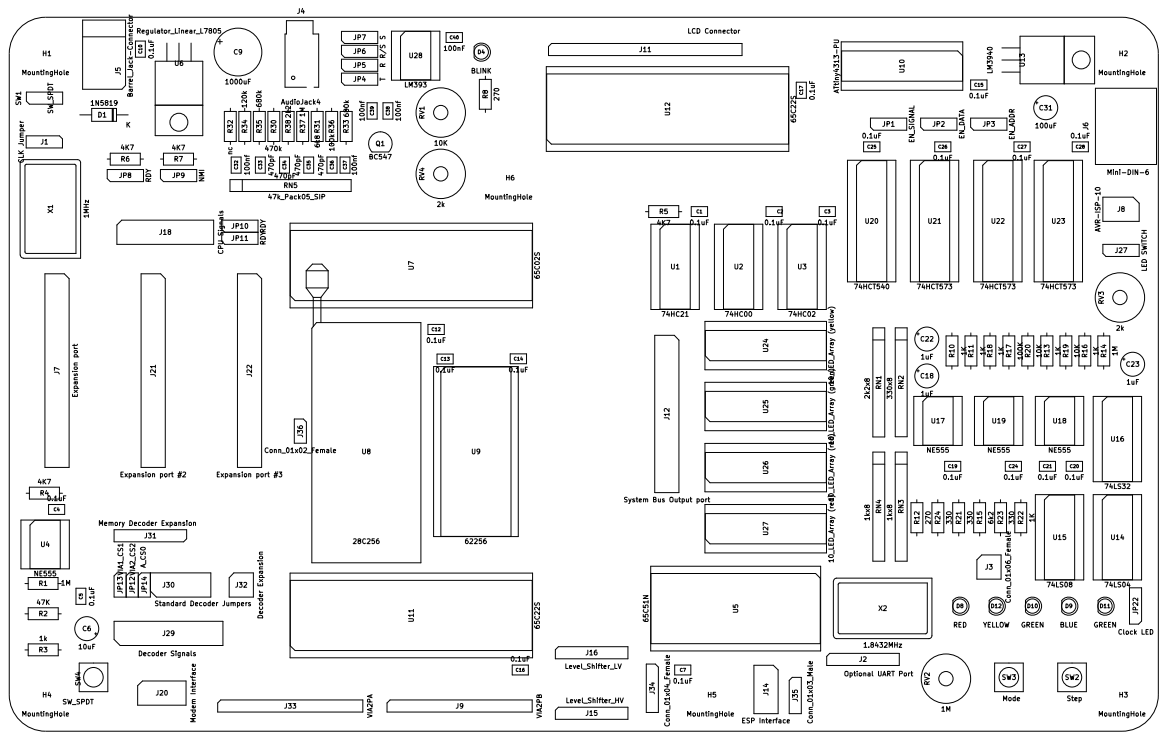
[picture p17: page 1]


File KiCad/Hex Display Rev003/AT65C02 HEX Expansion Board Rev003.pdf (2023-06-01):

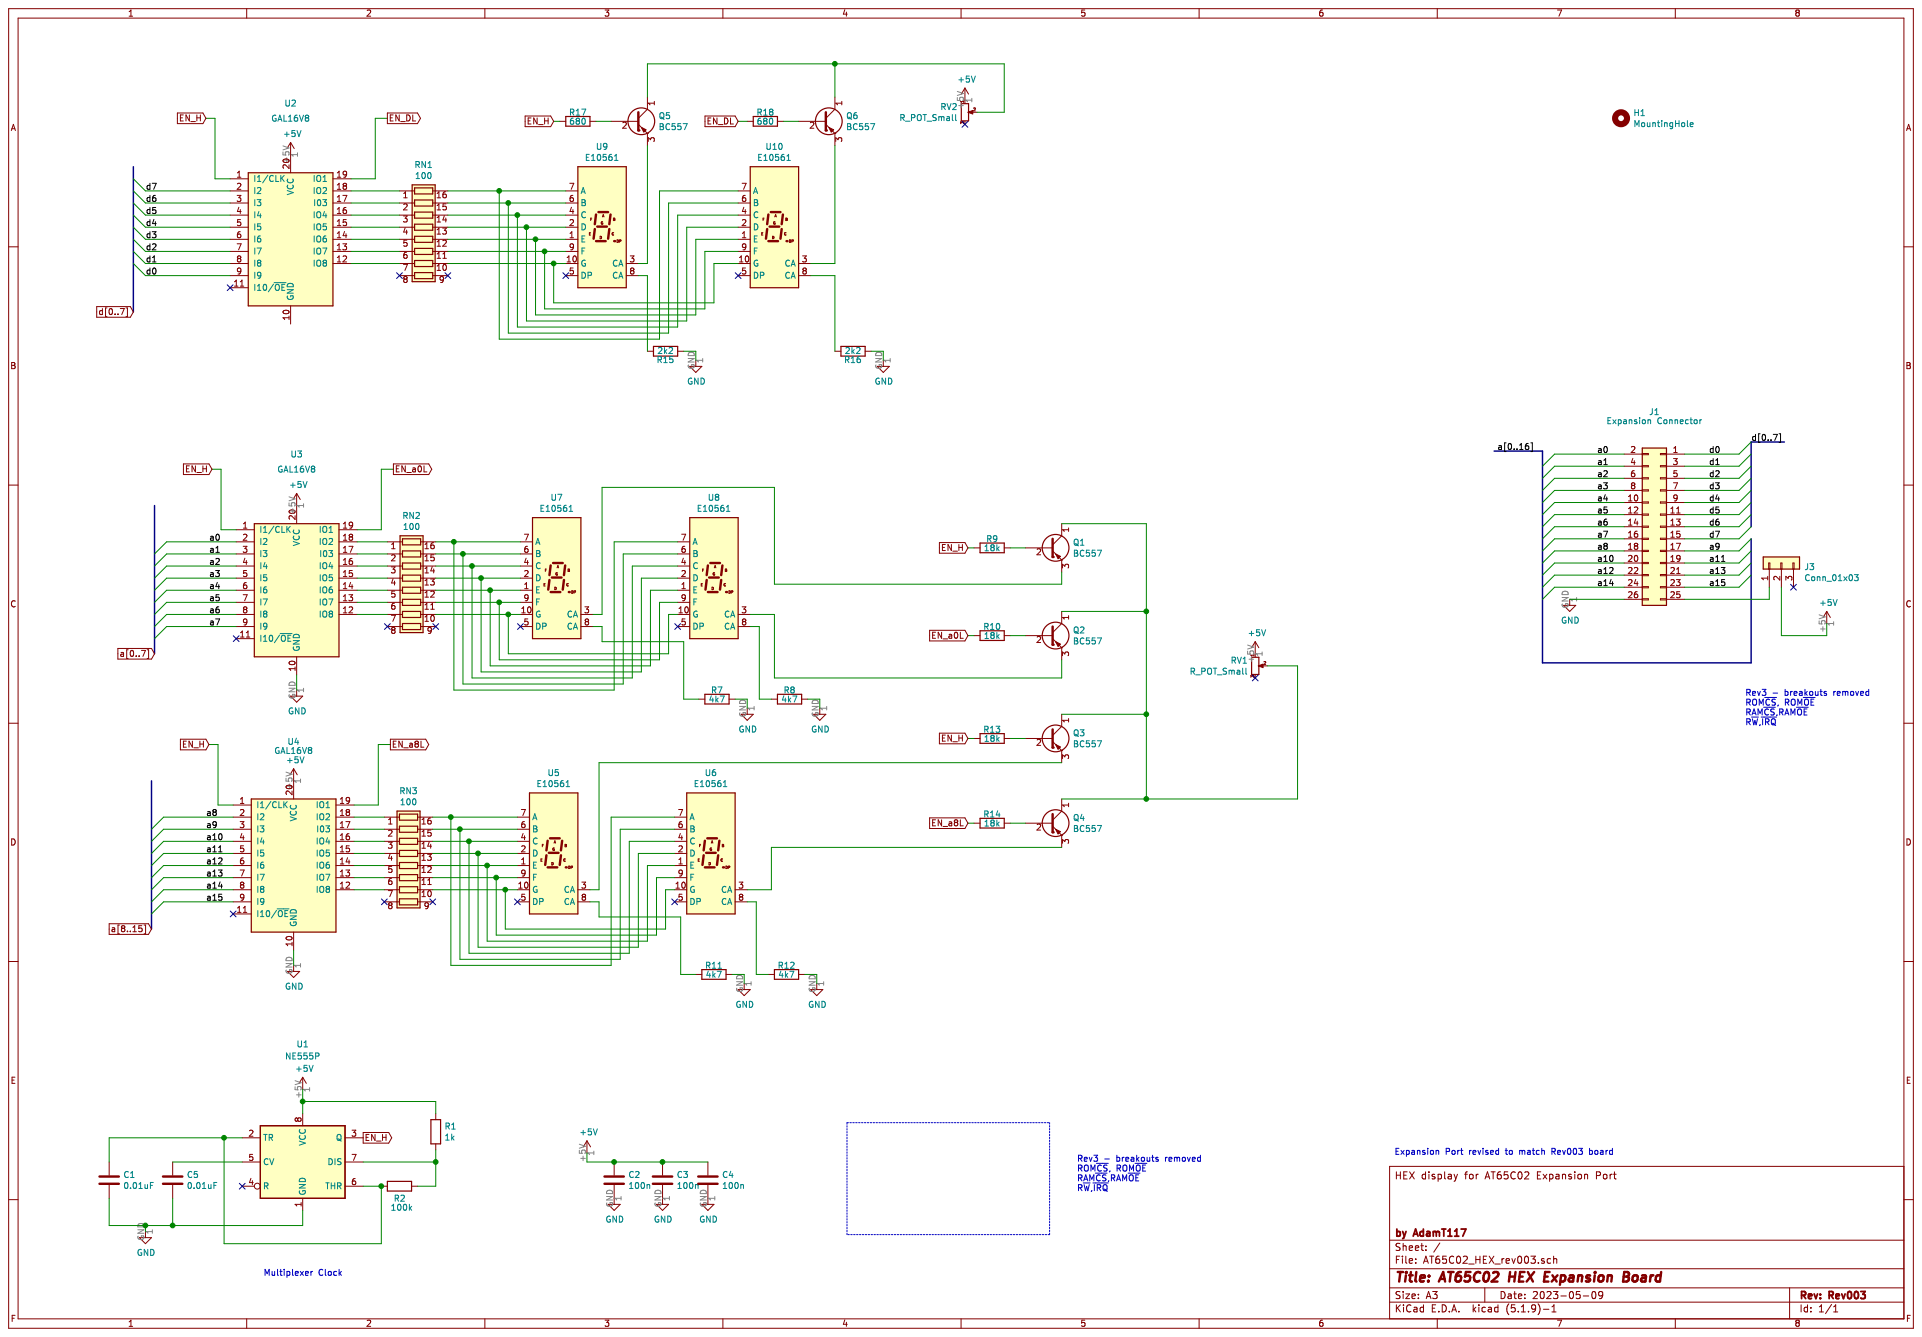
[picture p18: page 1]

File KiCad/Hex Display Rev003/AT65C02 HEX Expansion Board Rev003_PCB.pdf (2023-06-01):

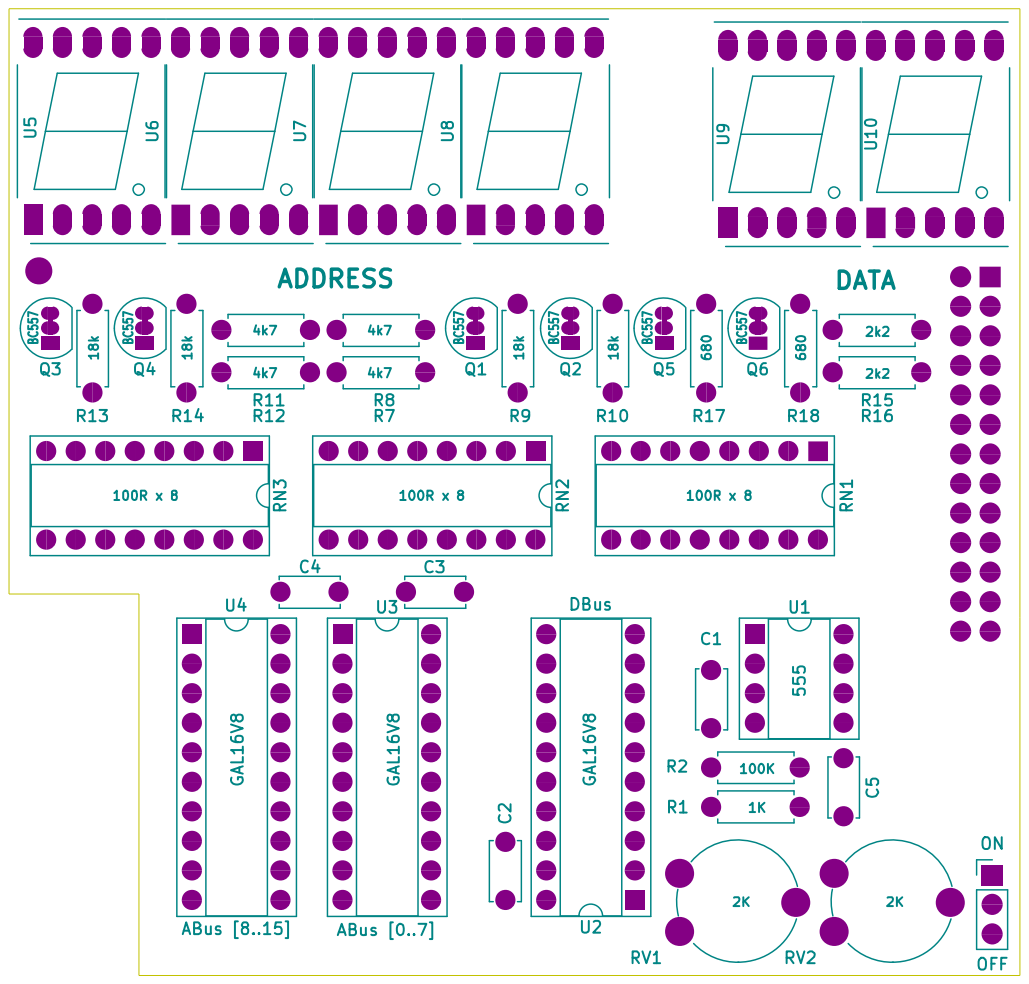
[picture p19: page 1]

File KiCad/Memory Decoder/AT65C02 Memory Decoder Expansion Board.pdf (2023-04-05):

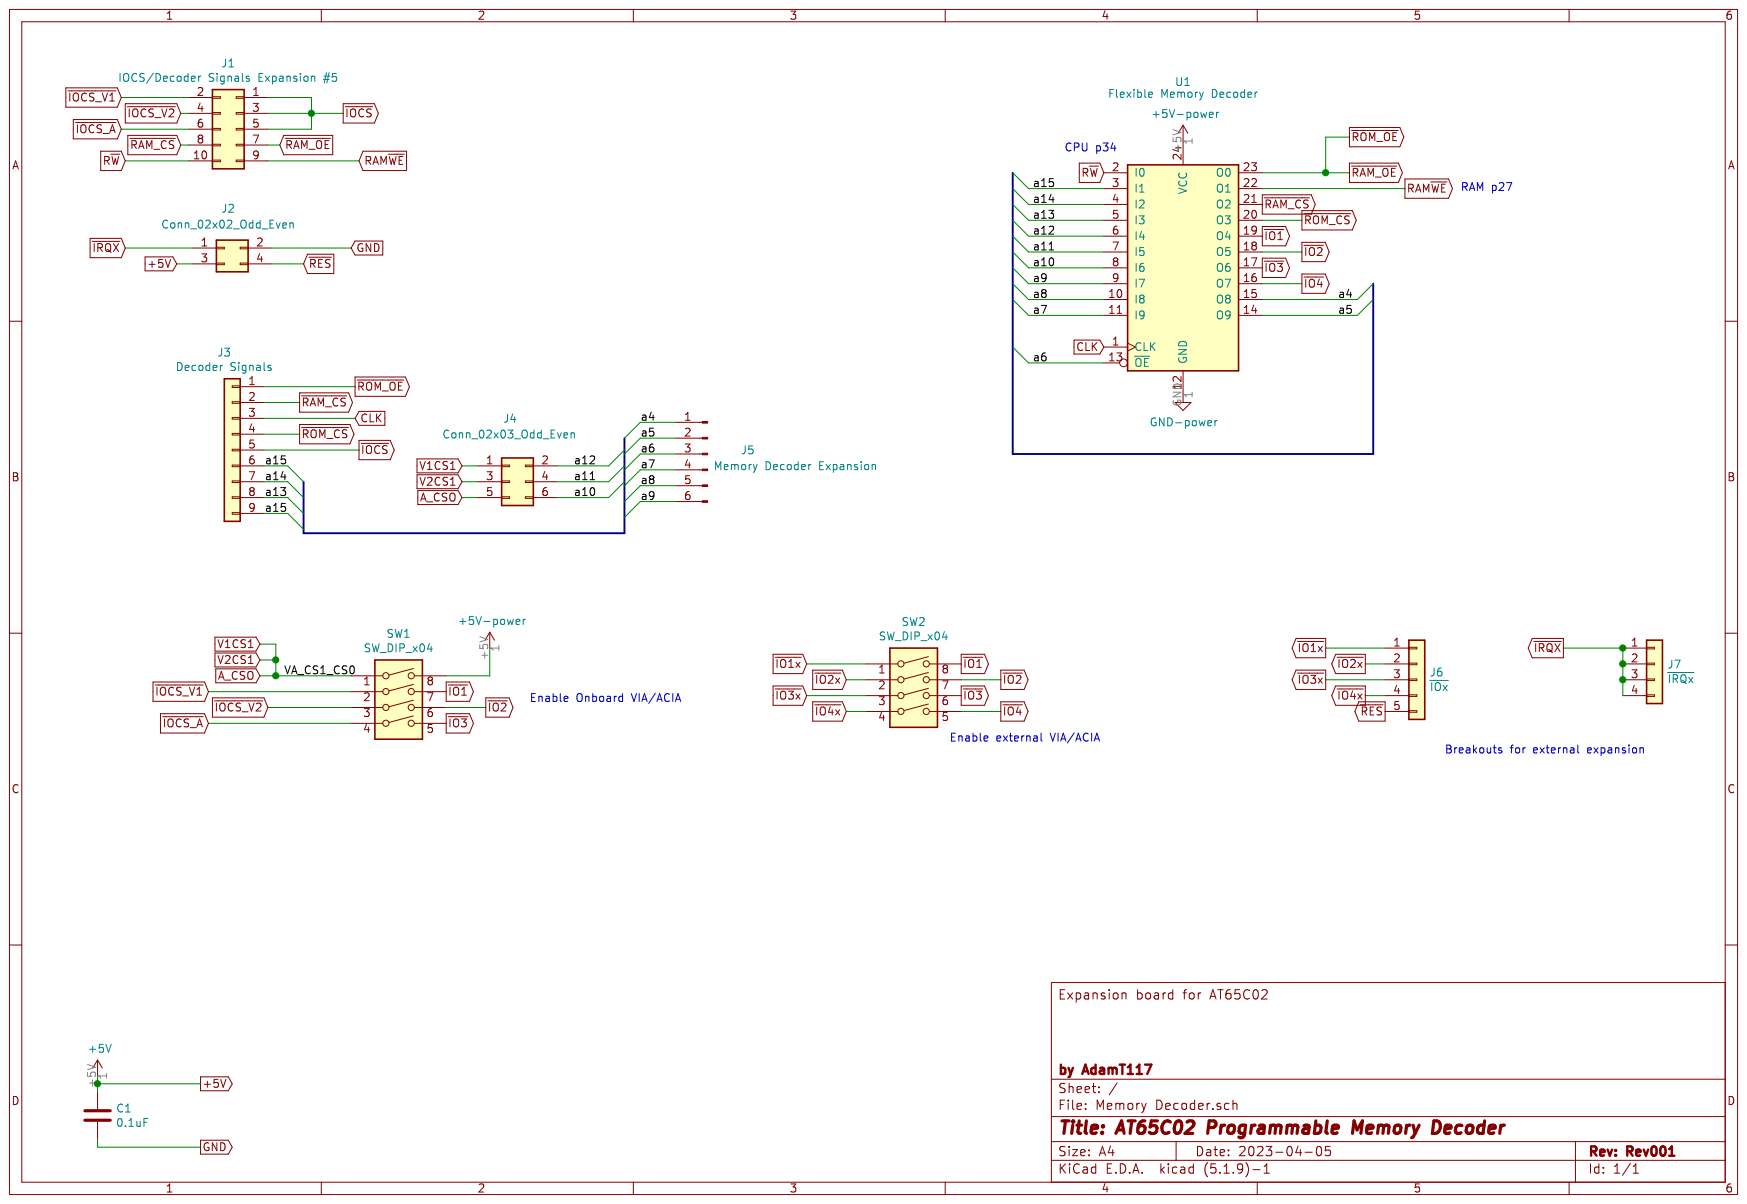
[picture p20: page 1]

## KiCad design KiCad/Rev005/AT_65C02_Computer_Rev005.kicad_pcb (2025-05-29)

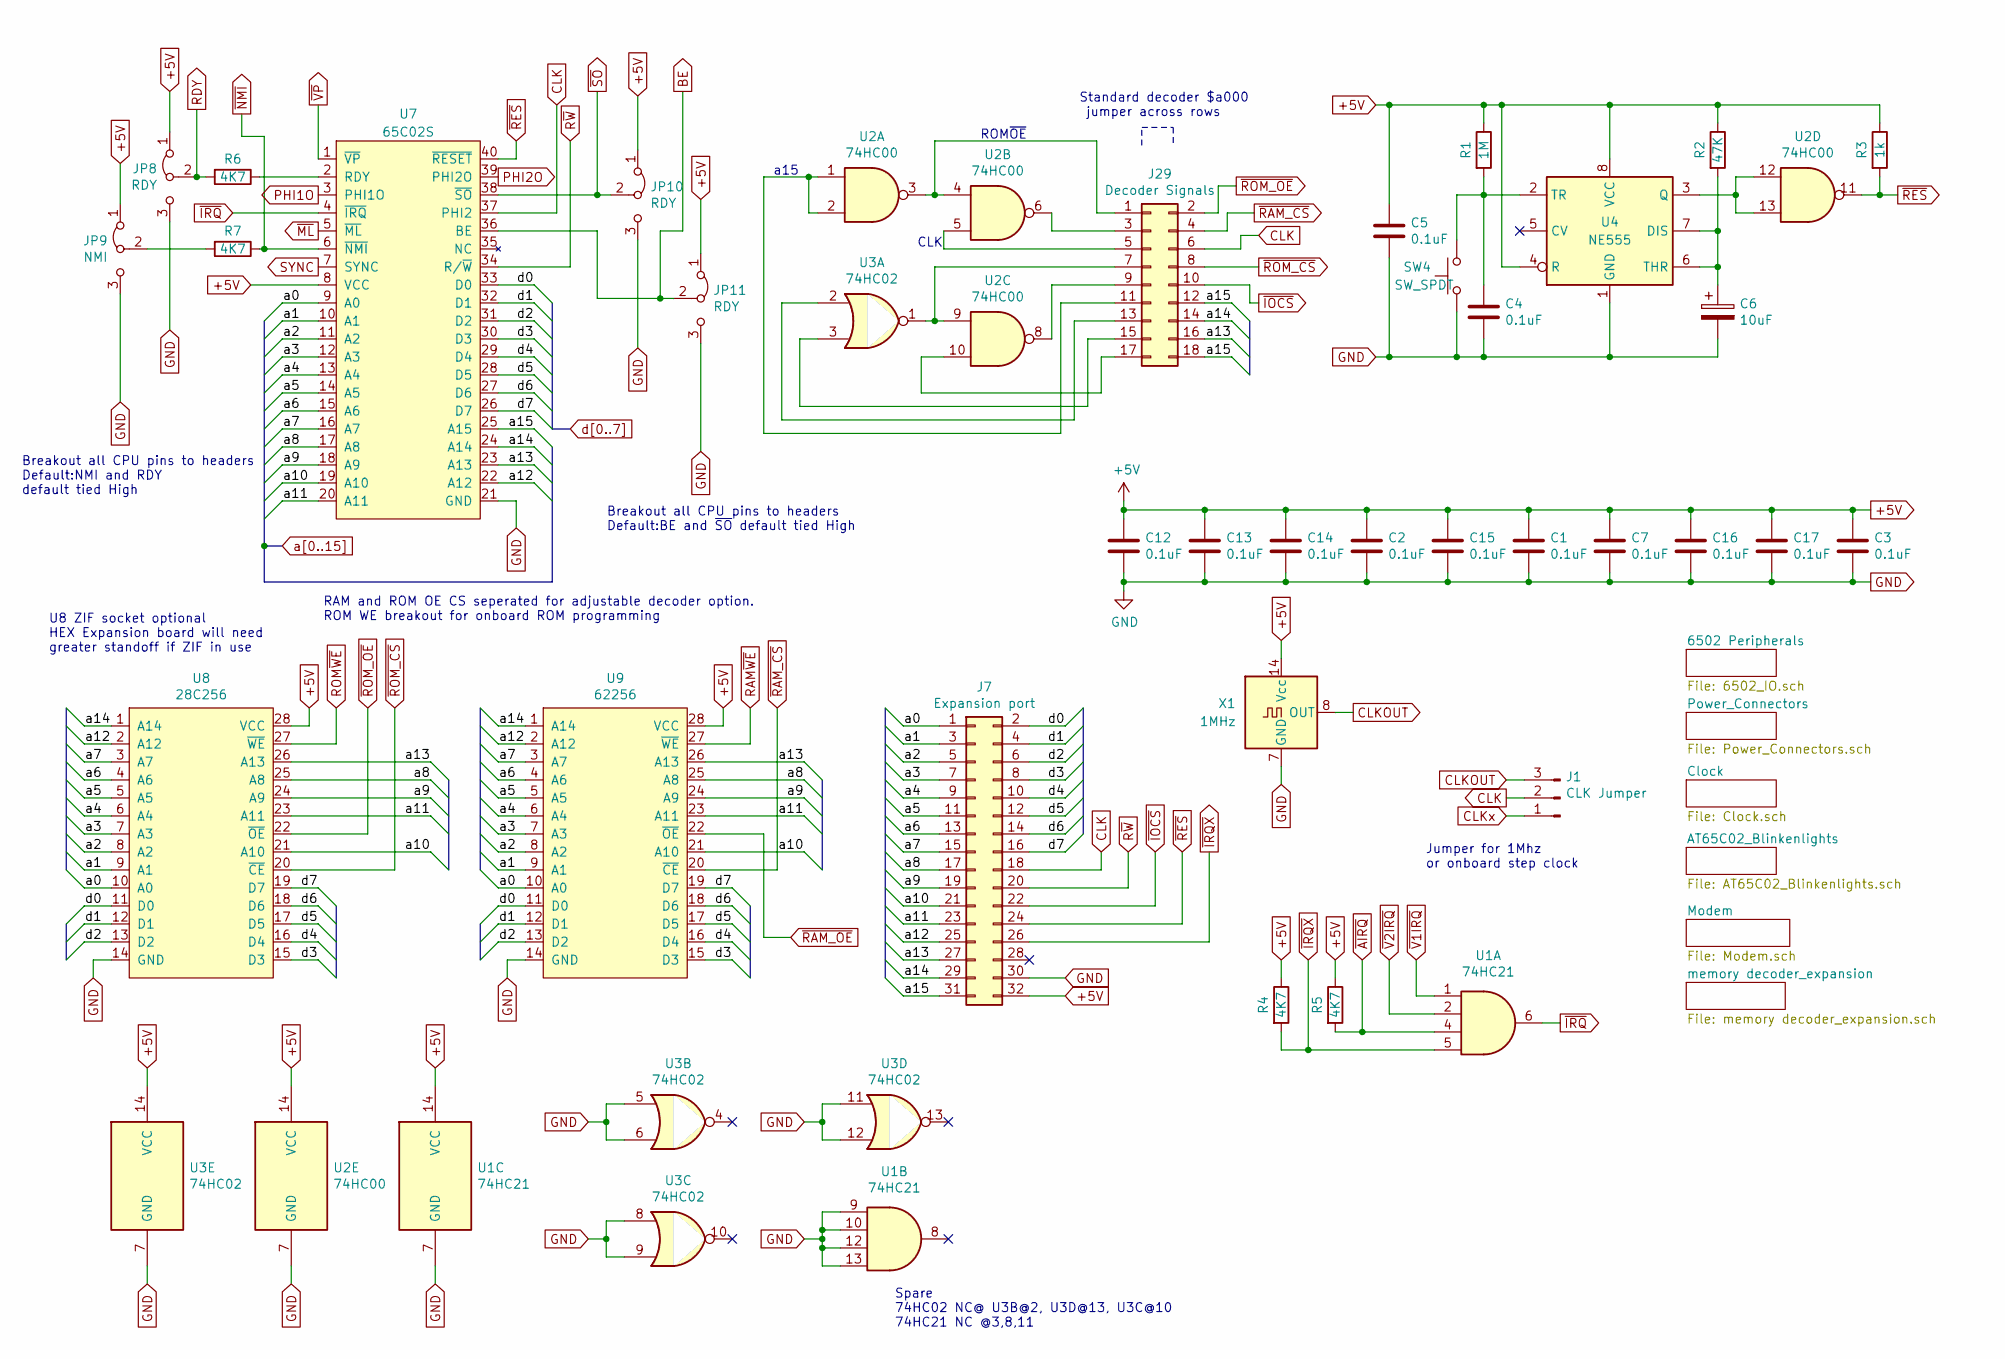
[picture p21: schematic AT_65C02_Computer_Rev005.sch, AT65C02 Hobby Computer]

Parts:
C1, C2, C3, C4, C5, C7, C12, C13, C14, C15, C16, C17: 0.1uF; C_Disc_D3.4mm_W2.1mm_P2.50mm
C6: 10uF; CP_Radial_D5.0mm_P2.50mm
J1: CLK Jumper; PinHeader_1x03_P2.54mm_Vertical
J7: Expansion port; PinSocket_2x16_P2.54mm_Vertical
J29: Decoder Signals; PinHeader_2x09_P2.54mm_Vertical
JP8, JP10, JP11: RDY; PinHeader_1x03_P2.54mm_Vertical
JP9: NMI; PinHeader_1x03_P2.54mm_Vertical
R1: 1M; R_Axial_DIN0207_L6.3mm_D2.5mm_P7.62mm_Horizontal
R2: 47K; R_Axial_DIN0207_L6.3mm_D2.5mm_P7.62mm_Horizontal
R3: 1k; R_Axial_DIN0207_L6.3mm_D2.5mm_P7.62mm_Horizontal
R4, R5, R6, R7: 4K7; R_Axial_DIN0207_L6.3mm_D2.5mm_P7.62mm_Horizontal
SW4: SW_SPDT; SW_PUSH_6mm
U1: 74HC21; DIP-14_W7.62mm_Socket
U2: 74HC00; DIP-14_W7.62mm_Socket
U3: 74HC02; DIP-14_W7.62mm_Socket
U4: NE555; DIP-8_W7.62mm_Socket
U7: 65C02S; DIP-40_W15.24mm_Socket
U8: 28C256; DIP_Socket-28_W11.9_W12.7_W15.24_W17.78_W18.5_3M_228-1277-0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
U9: 62256; DIP-28_W15.24mm_Socket
X1: 1MHz; Oscillator_DIP-14

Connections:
BE: JP11.2 (C), U7.36 (BE); also elsewhere on the board
CLK: J1.2, J7.18, J29.6, U7.37 (PHI2); also elsewhere on the board
CLKOUT: J1.3, X1.8 (OUT)
CLKx: J1.1; also elsewhere on the board
unnamed: C4.1, R1.2, SW4.2, U4.2 (TR)
unnamed: C6.1, R2.2, U4.6 (THR), U4.7 (DIS)
unnamed: J29.1, U2.3, U2.4
unnamed: J29.3, U2.6
unnamed: J29.5, U2.5
unnamed: J29.7, U2.9, U3.1
unnamed: J29.9, U2.8
unnamed: J29.11, U2.1, U2.2
unnamed: J29.13, U3.2
unnamed: J29.15, U3.3
unnamed: J29.17, U2.10
unnamed: JP9.2 (C), R7.2
unnamed: R6.1, U7.2 (RDY)
unnamed: U2.12, U2.13, U4.3 (Q)
PHI1O: U7.3 (PHI1O); also elsewhere on the board
PHI2O: U7.39 (PHI2O); also elsewhere on the board
RAM~WE~: U9.27 (~WE); also elsewhere on the board
RDY: JP8.2 (C), R6.2; also elsewhere on the board
ROM~WE: U8.27 (~WE); also elsewhere on the board
R~W: J7.20, U7.34 (R/~W); also elsewhere on the board
SYNC: U7.7 (SYNC); also elsewhere on the board
a0: J7.1, U7.9 (A0), U8.10 (A0), U9.10 (A0); also elsewhere on the board
a1: J7.3, U7.10 (A1), U8.9 (A1), U9.9 (A1); also elsewhere on the board
a2: J7.5, U7.11 (A2), U8.8 (A2), U9.8 (A2); also elsewhere on the board
a3: J7.7, U7.12 (A3), U8.7 (A3), U9.7 (A3); also elsewhere on the board
a4: J7.9, U7.13 (A4), U8.6 (A4), U9.6 (A4); also elsewhere on the board
a5: J7.11, U7.14 (A5), U8.5 (A5), U9.5 (A5); also elsewhere on the board
a6: J7.13, U7.15 (A6), U8.4 (A6), U9.4 (A6); also elsewhere on the board
a7: J7.15, U7.16 (A7), U8.3 (A7), U9.3 (A7); also elsewhere on the board
a8: J7.17, U7.17 (A8), U8.25 (A8), U9.25 (A8); also elsewhere on the board
a9: J7.19, U7.18 (A9), U8.24 (A9), U9.24 (A9); also elsewhere on the board
a10: J7.21, U7.19 (A10), U8.21 (A10), U9.21 (A10); also elsewhere on the board
a11: J7.23, U7.20 (A11), U8.23 (A11), U9.23 (A11); also elsewhere on the board
a12: J7.25, U7.22 (A12), U8.2 (A12), U9.2 (A12); also elsewhere on the board
a13: J7.27, J29.16, U7.23 (A13), U8.26 (A13), U9.26 (A13); also elsewhere on the board
a14: J7.29, J29.14, U7.24 (A14), U8.1 (A14), U9.1 (A14); also elsewhere on the board
a15: J7.31, J29.12, J29.18, U7.25 (A15); also elsewhere on the board
d0: J7.2, U7.33 (D0), U8.11 (D0), U9.11 (D0); also elsewhere on the board
d1: J7.4, U7.32 (D1), U8.12 (D1), U9.12 (D1); also elsewhere on the board
d2: J7.6, U7.31 (D2), U8.13 (D2), U9.13 (D2); also elsewhere on the board
d3: J7.8, U7.30 (D3), U8.15 (D3), U9.15 (D3); also elsewhere on the board
d4: J7.10, U7.29 (D4), U8.16 (D4), U9.16 (D4); also elsewhere on the board
d5: J7.12, U7.28 (D5), U8.17 (D5), U9.17 (D5); also elsewhere on the board
d6: J7.14, U7.27 (D6), U8.18 (D6), U9.18 (D6); also elsewhere on the board
d7: J7.16, U7.26 (D7), U8.19 (D7), U9.19 (D7); also elsewhere on the board
~AIRQ: R5.2, U1.4; also elsewhere on the board
~IOCS: J7.22, J29.10; also elsewhere on the board
~IRQ: U1.6, U7.4 (~IRQ); also elsewhere on the board
~IRQX: J7.26, R4.2, U1.5; also elsewhere on the board
~ML: U7.5 (~ML); also elsewhere on the board
~NMI: R7.1, U7.6 (~NMI); also elsewhere on the board
~RAM_CS: J29.4, U9.20 (~CE); also elsewhere on the board
~RAM_OE: U9.22 (~OE); also elsewhere on the board
~RES: J7.24, R3.2, U2.11, U7.40 (~RESET); also elsewhere on the board
~ROM_CS: J29.8, U8.20 (~CE); also elsewhere on the board
~ROM_OE: J29.2, U8.22 (~OE); also elsewhere on the board
~SO: JP10.2 (C), U7.38 (~SO); also elsewhere on the board
~V1IRQ: U1.1; also elsewhere on the board
~V2IRQ: U1.2; also elsewhere on the board
~VP: U7.1 (~VP); also elsewhere on the board

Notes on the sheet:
Breakout all CPU pins to headers Default:NMI and RDY default tied High
RAM and ROM OE CS seperated for adjustable decoder option. ROM WE breakout for onboard ROM programming
Jumper for 1Mhz or onboard step clock
Spare 74HC02 NC@ U3B@2, U3D@13, U3C@10 74HC21 NC @3,8,11
Standard decoder $a000 jumper across rows
Breakout all CPU pins to headers Default:BE and ~SO~ default tied High
U8 ZIF socket optional HEX Expansion board will need greater standoff if ZIF in use
ROM~OE
a15
CLK

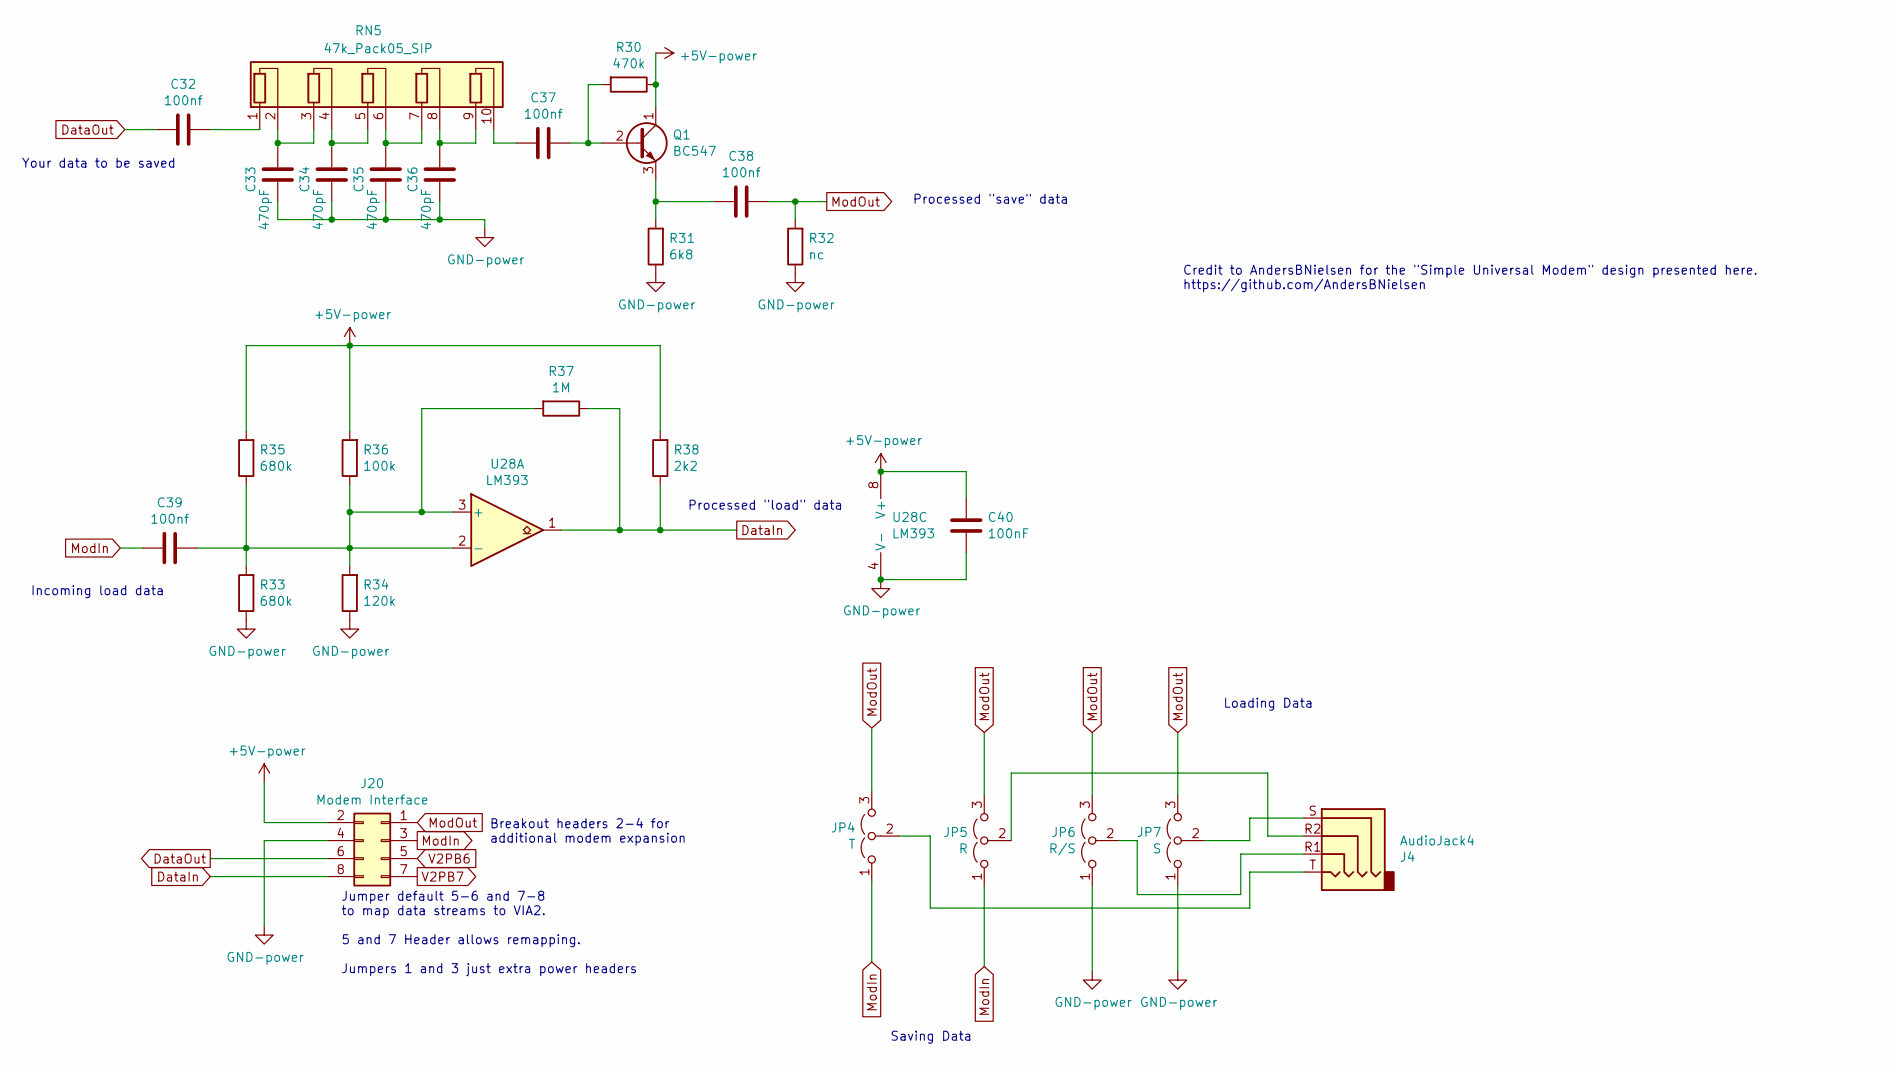
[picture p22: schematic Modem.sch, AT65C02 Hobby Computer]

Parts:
C32, C37, C38, C39: 100nf; C_Disc_D3.4mm_W2.1mm_P2.50mm
C33, C34, C35, C36: 470pF; C_Disc_D3.4mm_W2.1mm_P2.50mm
C40: 100nF; C_Disc_D3.4mm_W2.1mm_P2.50mm
J4: AudioJack4; Jack_3.5mm_PJ320E_Horizontal
J20: Modem Interface; PinSocket_2x04_P2.54mm_Vertical
JP4: T; PinHeader_1x03_P2.54mm_Vertical
JP5: R; PinHeader_1x03_P2.54mm_Vertical
JP6: R/S; PinHeader_1x03_P2.54mm_Vertical
JP7: S; PinHeader_1x03_P2.54mm_Vertical
Q1: BC547; TO-92_Inline
R30: 470k; R_Axial_DIN0207_L6.3mm_D2.5mm_P7.62mm_Horizontal
R31: 6k8; R_Axial_DIN0207_L6.3mm_D2.5mm_P7.62mm_Horizontal
R32: nc; R_Axial_DIN0207_L6.3mm_D2.5mm_P7.62mm_Horizontal
R33, R35: 680k; R_Axial_DIN0207_L6.3mm_D2.5mm_P7.62mm_Horizontal
R34: 120k; R_Axial_DIN0207_L6.3mm_D2.5mm_P7.62mm_Horizontal
R36: 100k; R_Axial_DIN0207_L6.3mm_D2.5mm_P7.62mm_Horizontal
R37: 1M; R_Axial_DIN0207_L6.3mm_D2.5mm_P7.62mm_Horizontal
R38: 2k2; R_Axial_DIN0207_L6.3mm_D2.5mm_P7.62mm_Horizontal
RN5: 47k_Pack05_SIP; R_Array_SIP10
U28: LM393; DIP-8_W7.62mm_Socket

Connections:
DataIn: J20.8, R37.1, R38.1, U28.1
DataOut: C32.2, J20.6
ModIn: C39.2, J20.3, JP4.1 (A), JP5.1 (A)
ModOut: C38.1, J20.1, JP4.3 (B), JP5.3 (B), JP6.3 (B), JP7.3 (B), R32.2
unnamed: C32.1, RN5.1 (R1.1)
unnamed: C33.2, RN5.2 (R1.2), RN5.3 (R2.1)
unnamed: C34.2, RN5.4 (R2.2), RN5.5 (R3.1)
unnamed: C35.2, RN5.6 (R3.2), RN5.7 (R4.1)
unnamed: C36.2, RN5.8 (R4.2), RN5.9 (R5.1)
unnamed: C37.1, Q1.2 (B), R30.2
unnamed: C37.2, RN5.10 (R5.2)
unnamed: C38.2, Q1.3 (E), R31.2
unnamed: C39.1, R33.2, R34.2, R35.1, R36.1, R37.2, U28.2 (-), U28.3 (+)
unnamed: J4.R1, JP6.2 (C)
unnamed: J4.R2, JP5.2 (C)
unnamed: J4.S, JP7.2 (C)
unnamed: J4.T, JP4.2 (C)
V2PB6: J20.5; also elsewhere on the board
V2PB7: J20.7; also elsewhere on the board

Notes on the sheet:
Credit to AndersBNielsen for the "Simple Universal Modem" design presented here. https://github.com/AndersBNielsen
Loading Data
Saving Data
Breakout headers 2-4 for additional modem expansion
Jumper default 5-6 and 7-8 to map data streams to VIA2. 5 and 7 Header allows remapping. Jumpers 1 and 3 just extra power headers
Processed "load" data
Processed "save" data
Your data to be saved
Incoming load data

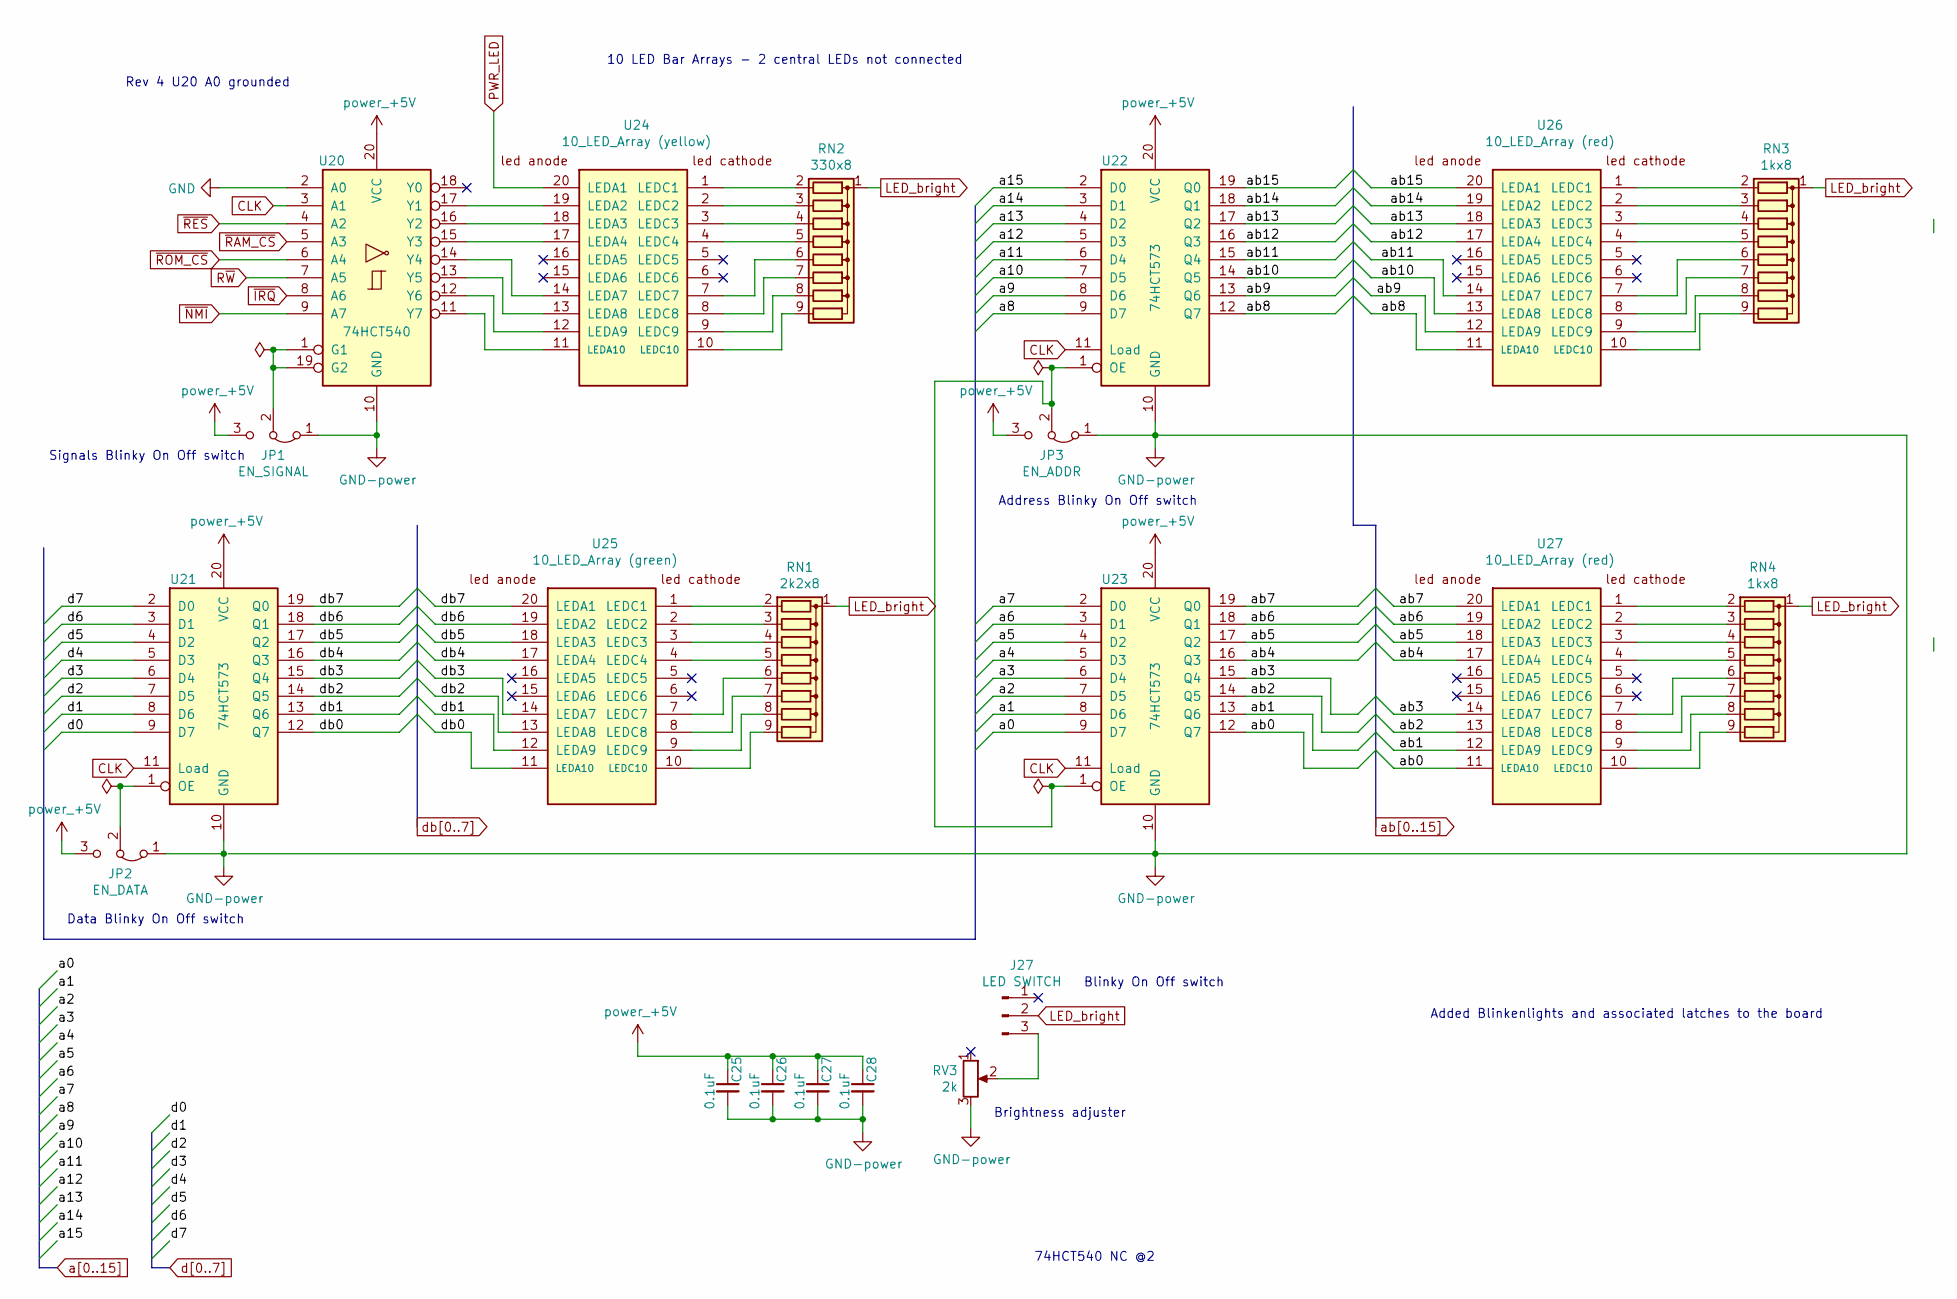
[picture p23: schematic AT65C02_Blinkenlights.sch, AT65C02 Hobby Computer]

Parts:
C25, C26, C27, C28: 0.1uF; C_Disc_D3.4mm_W2.1mm_P2.50mm
J27: LED SWITCH; PinHeader_1x03_P2.54mm_Vertical
JP1: EN_SIGNAL; PinHeader_1x03_P2.54mm_Vertical
JP2: EN_DATA; PinHeader_1x03_P2.54mm_Vertical
JP3: EN_ADDR; PinHeader_1x03_P2.54mm_Vertical
RN1: 2k2x8; R_Array_SIP9
RN2: 330x8; R_Array_SIP9
RN3, RN4: 1kx8; R_Array_SIP9
RV3: 2k; Potentiometer_Piher_PT-10-V10_Vertical
U20: 74HCT540; DIP-20_W7.62mm_Socket_LongPads
U21, U22, U23: 74HCT573; DIP-20_W7.62mm_Socket_LongPads
U24: 10_LED_Array (yellow); DIP-20_W7.62mm_Socket
U25: 10_LED_Array (green); DIP-20_W7.62mm_Socket
U26, U27: 10_LED_Array (red); DIP-20_W7.62mm_Socket

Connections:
CLK: U20.3 (A1), U21.11 (Load), U22.11 (Load), U23.11 (Load); also elsewhere on the board
LED_bright: J27.2, RN1.1 (common), RN2.1 (common), RN3.1 (common), RN4.1 (common)
unnamed: J27.3, RV3.2
unnamed: JP1.2 (C), U20.1 (G1), U20.19 (G2)
unnamed: JP2.2 (C), U21.1 (OE)
unnamed: JP3.2 (C), U22.1 (OE), U23.1 (OE)
unnamed: RN1.2 (R1), U25.1 (LEDC1)
unnamed: RN1.3 (R2), U25.2 (LEDC2)
unnamed: RN1.4 (R3), U25.3 (LEDC3)
unnamed: RN1.5 (R4), U25.4 (LEDC4)
unnamed: RN1.6 (R5), U25.7 (LEDC7)
unnamed: RN1.7 (R6), U25.8 (LEDC8)
unnamed: RN1.8 (R7), U25.9 (LEDC9)
unnamed: RN1.9 (R8), U25.10 (LEDC10)
unnamed: RN2.2 (R1), U24.1 (LEDC1)
unnamed: RN2.3 (R2), U24.2 (LEDC2)
unnamed: RN2.4 (R3), U24.3 (LEDC3)
unnamed: RN2.5 (R4), U24.4 (LEDC4)
unnamed: RN2.6 (R5), U24.7 (LEDC7)
unnamed: RN2.7 (R6), U24.8 (LEDC8)
unnamed: RN2.8 (R7), U24.9 (LEDC9)
unnamed: RN2.9 (R8), U24.10 (LEDC10)
unnamed: RN3.2 (R1), U26.1 (LEDC1)
unnamed: RN3.3 (R2), U26.2 (LEDC2)
unnamed: RN3.4 (R3), U26.3 (LEDC3)
unnamed: RN3.5 (R4), U26.4 (LEDC4)
unnamed: RN3.6 (R5), U26.7 (LEDC7)
unnamed: RN3.7 (R6), U26.8 (LEDC8)
unnamed: RN3.8 (R7), U26.9 (LEDC9)
unnamed: RN3.9 (R8), U26.10 (LEDC10)
unnamed: RN4.2 (R1), U27.1 (LEDC1)
unnamed: RN4.3 (R2), U27.2 (LEDC2)
unnamed: RN4.4 (R3), U27.3 (LEDC3)
unnamed: RN4.5 (R4), U27.4 (LEDC4)
unnamed: RN4.6 (R5), U27.7 (LEDC7)
unnamed: RN4.7 (R6), U27.8 (LEDC8)
unnamed: RN4.8 (R7), U27.9 (LEDC9)
unnamed: RN4.9 (R8), U27.10 (LEDC10)
unnamed: U20.11 (Y7), U24.11 (LEDA10)
unnamed: U20.12 (Y6), U24.12 (LEDA9)
unnamed: U20.13 (Y5), U24.13 (LEDA8)
unnamed: U20.14 (Y4), U24.14 (LEDA7)
unnamed: U20.15 (Y3), U24.17 (LEDA4)
unnamed: U20.16 (Y2), U24.18 (LEDA3)
unnamed: U20.17 (Y1), U24.19 (LEDA2)
R~W: U20.7 (A5); also elsewhere on the board
a0: U23.9 (D7); also elsewhere on the board
a1: U23.8 (D6); also elsewhere on the board
a2: U23.7 (D5); also elsewhere on the board
a3: U23.6 (D4); also elsewhere on the board
a4: U23.5 (D3); also elsewhere on the board
a5: U23.4 (D2); also elsewhere on the board
a6: U23.3 (D1); also elsewhere on the board
a7: U23.2 (D0); also elsewhere on the board
a8: U22.9 (D7); also elsewhere on the board
a9: U22.8 (D6); also elsewhere on the board
a10: U22.7 (D5); also elsewhere on the board
a11: U22.6 (D4); also elsewhere on the board
a12: U22.5 (D3); also elsewhere on the board
a13: U22.4 (D2); also elsewhere on the board
a14: U22.3 (D1); also elsewhere on the board
a15: U22.2 (D0); also elsewhere on the board
ab0: U23.12 (Q7), U27.11 (LEDA10); also elsewhere on the board
ab1: U23.13 (Q6), U27.12 (LEDA9); also elsewhere on the board
ab2: U23.14 (Q5), U27.13 (LEDA8); also elsewhere on the board
ab3: U23.15 (Q4), U27.14 (LEDA7); also elsewhere on the board
ab4: U23.16 (Q3), U27.17 (LEDA4); also elsewhere on the board
ab5: U23.17 (Q2), U27.18 (LEDA3); also elsewhere on the board
ab6: U23.18 (Q1), U27.19 (LEDA2); also elsewhere on the board
ab7: U23.19 (Q0), U27.20 (LEDA1); also elsewhere on the board
ab8: U22.12 (Q7), U26.11 (LEDA10); also elsewhere on the board
ab9: U22.13 (Q6), U26.12 (LEDA9); also elsewhere on the board
ab10: U22.14 (Q5), U26.13 (LEDA8); also elsewhere on the board
ab11: U22.15 (Q4), U26.14 (LEDA7); also elsewhere on the board
ab12: U22.16 (Q3), U26.17 (LEDA4); also elsewhere on the board
ab13: U22.17 (Q2), U26.18 (LEDA3); also elsewhere on the board
ab14: U22.18 (Q1), U26.19 (LEDA2); also elsewhere on the board
ab15: U22.19 (Q0), U26.20 (LEDA1); also elsewhere on the board
d0: U21.9 (D7); also elsewhere on the board
d1: U21.8 (D6); also elsewhere on the board
d2: U21.7 (D5); also elsewhere on the board
d3: U21.6 (D4); also elsewhere on the board
d4: U21.5 (D3); also elsewhere on the board
d5: U21.4 (D2); also elsewhere on the board
d6: U21.3 (D1); also elsewhere on the board
d7: U21.2 (D0); also elsewhere on the board
db0: U21.12 (Q7), U25.11 (LEDA10); also elsewhere on the board
db1: U21.13 (Q6), U25.12 (LEDA9); also elsewhere on the board
db2: U21.14 (Q5), U25.13 (LEDA8); also elsewhere on the board
db3: U21.15 (Q4), U25.14 (LEDA7); also elsewhere on the board
db4: U21.16 (Q3), U25.17 (LEDA4); also elsewhere on the board
db5: U21.17 (Q2), U25.18 (LEDA3); also elsewhere on the board
db6: U21.18 (Q1), U25.19 (LEDA2); also elsewhere on the board
db7: U21.19 (Q0), U25.20 (LEDA1); also elsewhere on the board
~IRQ: U20.8 (A6); also elsewhere on the board
~NMI: U20.9 (A7); also elsewhere on the board
~RAM_CS: U20.5 (A3); also elsewhere on the board
~RES: U20.4 (A2); also elsewhere on the board
~ROM_CS: U20.6 (A4); also elsewhere on the board

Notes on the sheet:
Added Blinkenlights and associated latches to the board
Brightness adjuster
Blinky On Off switch
10 LED Bar Arrays - 2 central LEDs not connected
Data Blinky On Off switch
Signals Blinky On Off switch
Address Blinky On Off switch
74HCT540 NC @2
Rev 4 U20 A0 grounded

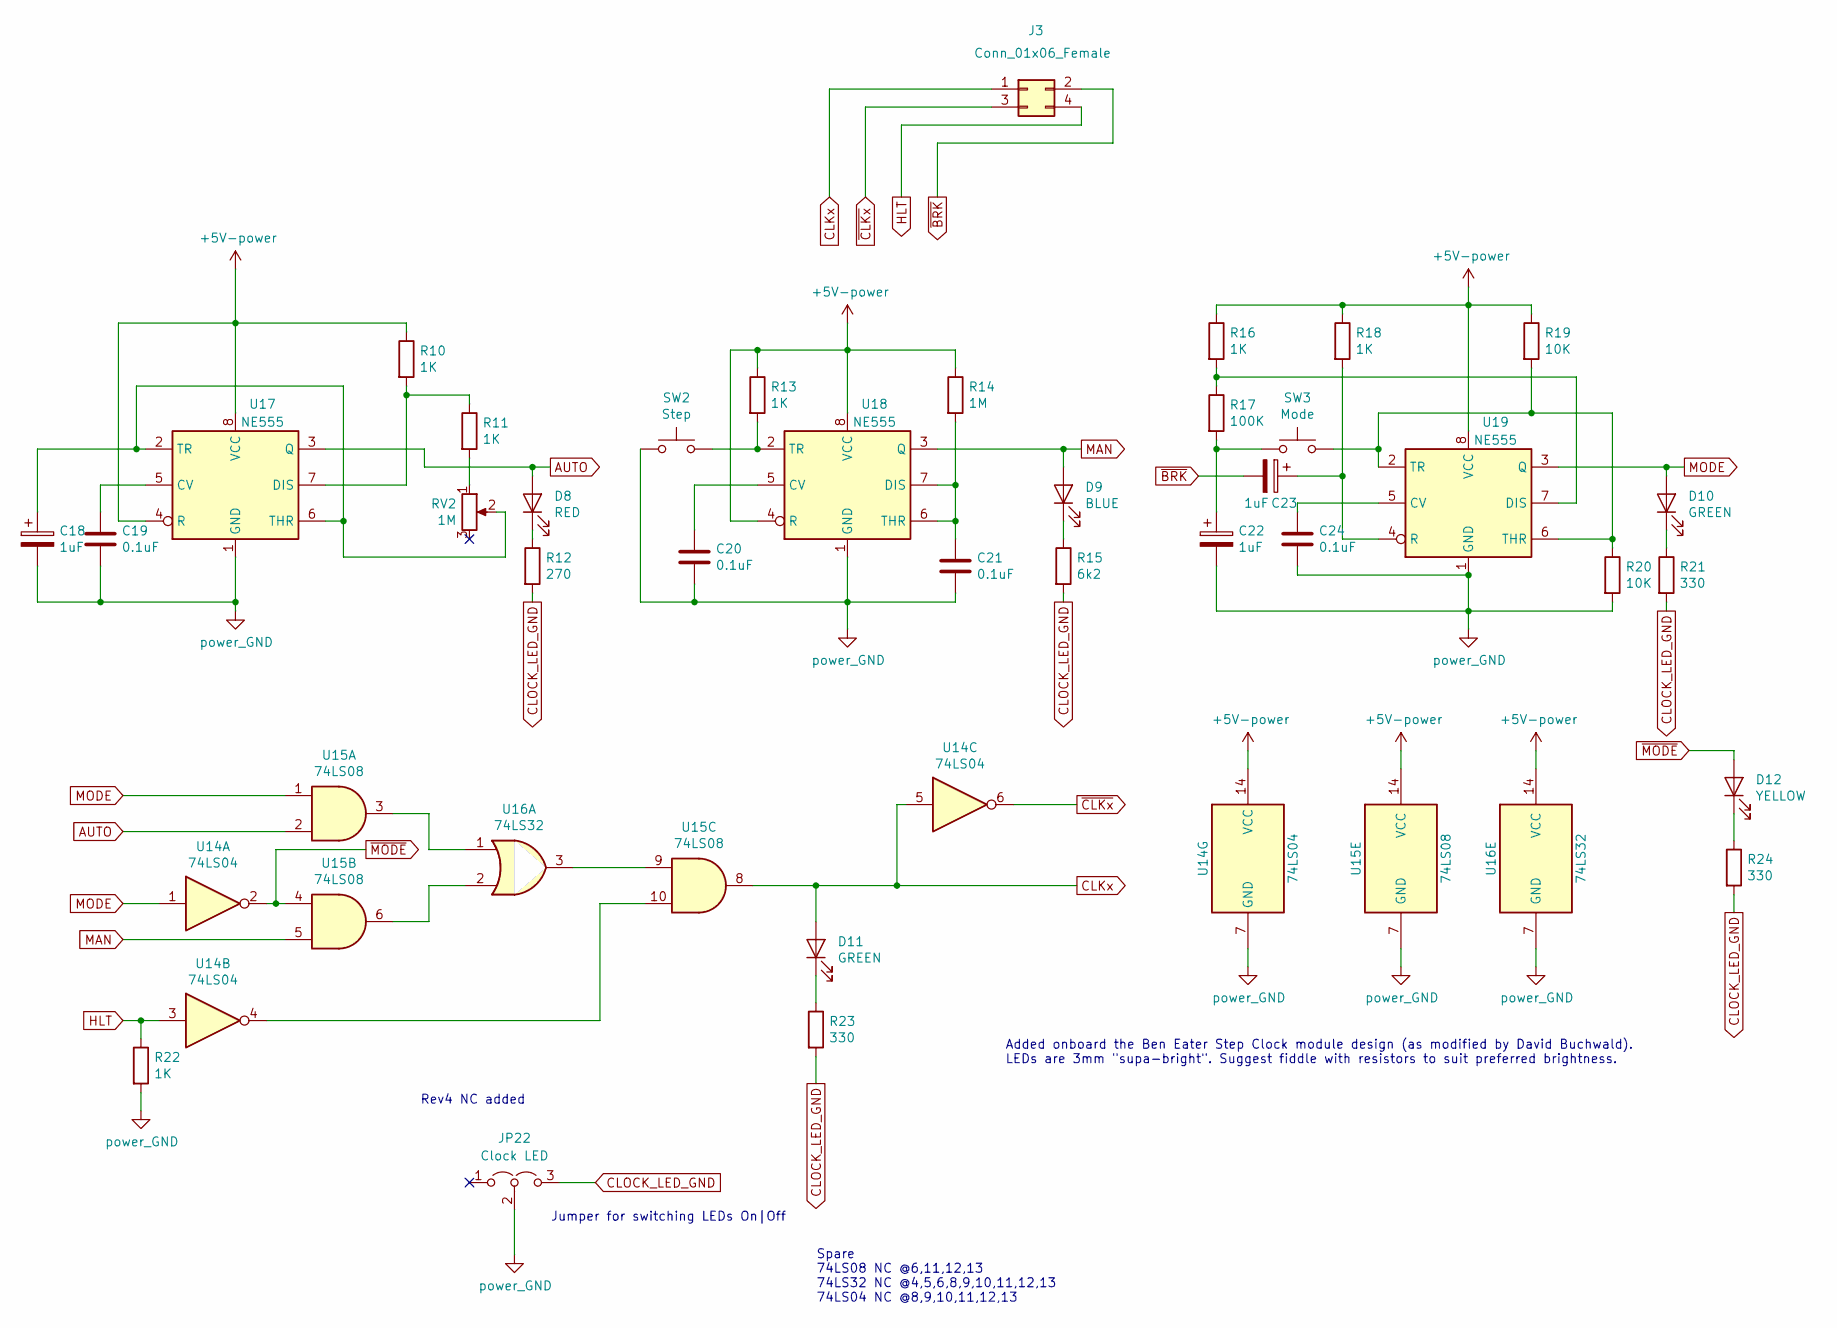
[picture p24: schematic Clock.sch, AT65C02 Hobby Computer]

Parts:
C18, C22, C23: 1uF; CP_Radial_D5.0mm_P2.50mm
C19, C20, C21, C24: 0.1uF; C_Disc_D3.4mm_W2.1mm_P2.50mm
D8: RED; LED_D3.0mm
D9: BLUE; LED_D3.0mm
D10, D11: GREEN; LED_D3.0mm
D12: YELLOW; LED_D3.0mm
J3: Conn_01x06_Female; PinSocket_2x02_P2.54mm_Vertical
JP22: Clock LED; PinHeader_1x03_P2.54mm_Vertical
R10, R11, R13, R16, R18, R22: 1K; R_Axial_DIN0207_L6.3mm_D2.5mm_P7.62mm_Horizontal
R12: 270; R_Axial_DIN0207_L6.3mm_D2.5mm_P7.62mm_Horizontal
R14: 1M; R_Axial_DIN0207_L6.3mm_D2.5mm_P7.62mm_Horizontal
R15: 6k2; R_Axial_DIN0207_L6.3mm_D2.5mm_P7.62mm_Horizontal
R17: 100K; R_Axial_DIN0207_L6.3mm_D2.5mm_P7.62mm_Horizontal
R19, R20: 10K; R_Axial_DIN0207_L6.3mm_D2.5mm_P7.62mm_Horizontal
R21, R23, R24: 330; R_Axial_DIN0207_L6.3mm_D2.5mm_P7.62mm_Horizontal
RV2: 1M; Potentiometer_Piher_PT-10-V10_Vertical
SW2: Step; SW_PUSH_6mm
SW3: Mode; SW_PUSH_6mm
U14: 74LS04; DIP-14_W7.62mm_Socket
U15: 74LS08; DIP-14_W7.62mm_Socket
U16: 74LS32; DIP-14_W7.62mm_Socket
U17, U18, U19: NE555; DIP-8_W7.62mm_Socket

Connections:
AUTO: D8.2 (A), U15.2, U17.3 (Q)
CLKx: D11.2 (A), J3.1, U14.5, U15.8; also elsewhere on the board
CLOCK_LED_GND: JP22.3 (B), R12.2, R15.2, R21.2, R23.2, R24.2
HLT: J3.4, R22.1, U14.3
MAN: D9.2 (A), U15.5, U18.3 (Q)
MODE: D10.2 (A), U14.1, U15.1, U19.3 (Q)
unnamed: C18.1, RV2.2, U17.2 (TR), U17.6 (THR)
unnamed: C19.1, U17.5 (CV)
unnamed: C20.1, U18.5 (CV)
unnamed: C21.1, R14.2, U18.6 (THR), U18.7 (DIS)
unnamed: C22.1, R17.2, SW3.1
unnamed: C23.1, R18.2, U19.4 (R)
unnamed: C24.1, U19.5 (CV)
unnamed: D8.1 (K), R12.1
unnamed: D9.1 (K), R15.1
unnamed: D10.1 (K), R21.1
unnamed: D11.1 (K), R23.1
unnamed: D12.1 (K), R24.1
unnamed: R10.2, R11.1, U17.7 (DIS)
unnamed: R11.2, RV2.1
unnamed: R13.2, SW2.2, U18.2 (TR)
unnamed: R16.2, R17.1, U19.7 (DIS)
unnamed: R19.2, R20.1, SW3.2, U19.2 (TR), U19.6 (THR)
unnamed: U14.4, U15.10
unnamed: U15.3, U16.1
unnamed: U15.6, U16.2
unnamed: U15.9, U16.3
~BRK: C23.2, J3.2
~CLKx: J3.3, U14.6
~MODE: D12.2 (A), U14.2, U15.4

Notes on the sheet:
Added onboard the Ben Eater Step Clock module design (as modified by David Buchwald). LEDs are 3mm "supa-bright". Suggest fiddle with resistors to suit preferred brightness.
Jumper for switching LEDs On|Off
Spare 74LS08 NC @6,11,12,13 74LS32 NC @4,5,6,8,9,10,11,12,13 74LS04 NC @8,9,10,11,12,13
Rev4 NC added

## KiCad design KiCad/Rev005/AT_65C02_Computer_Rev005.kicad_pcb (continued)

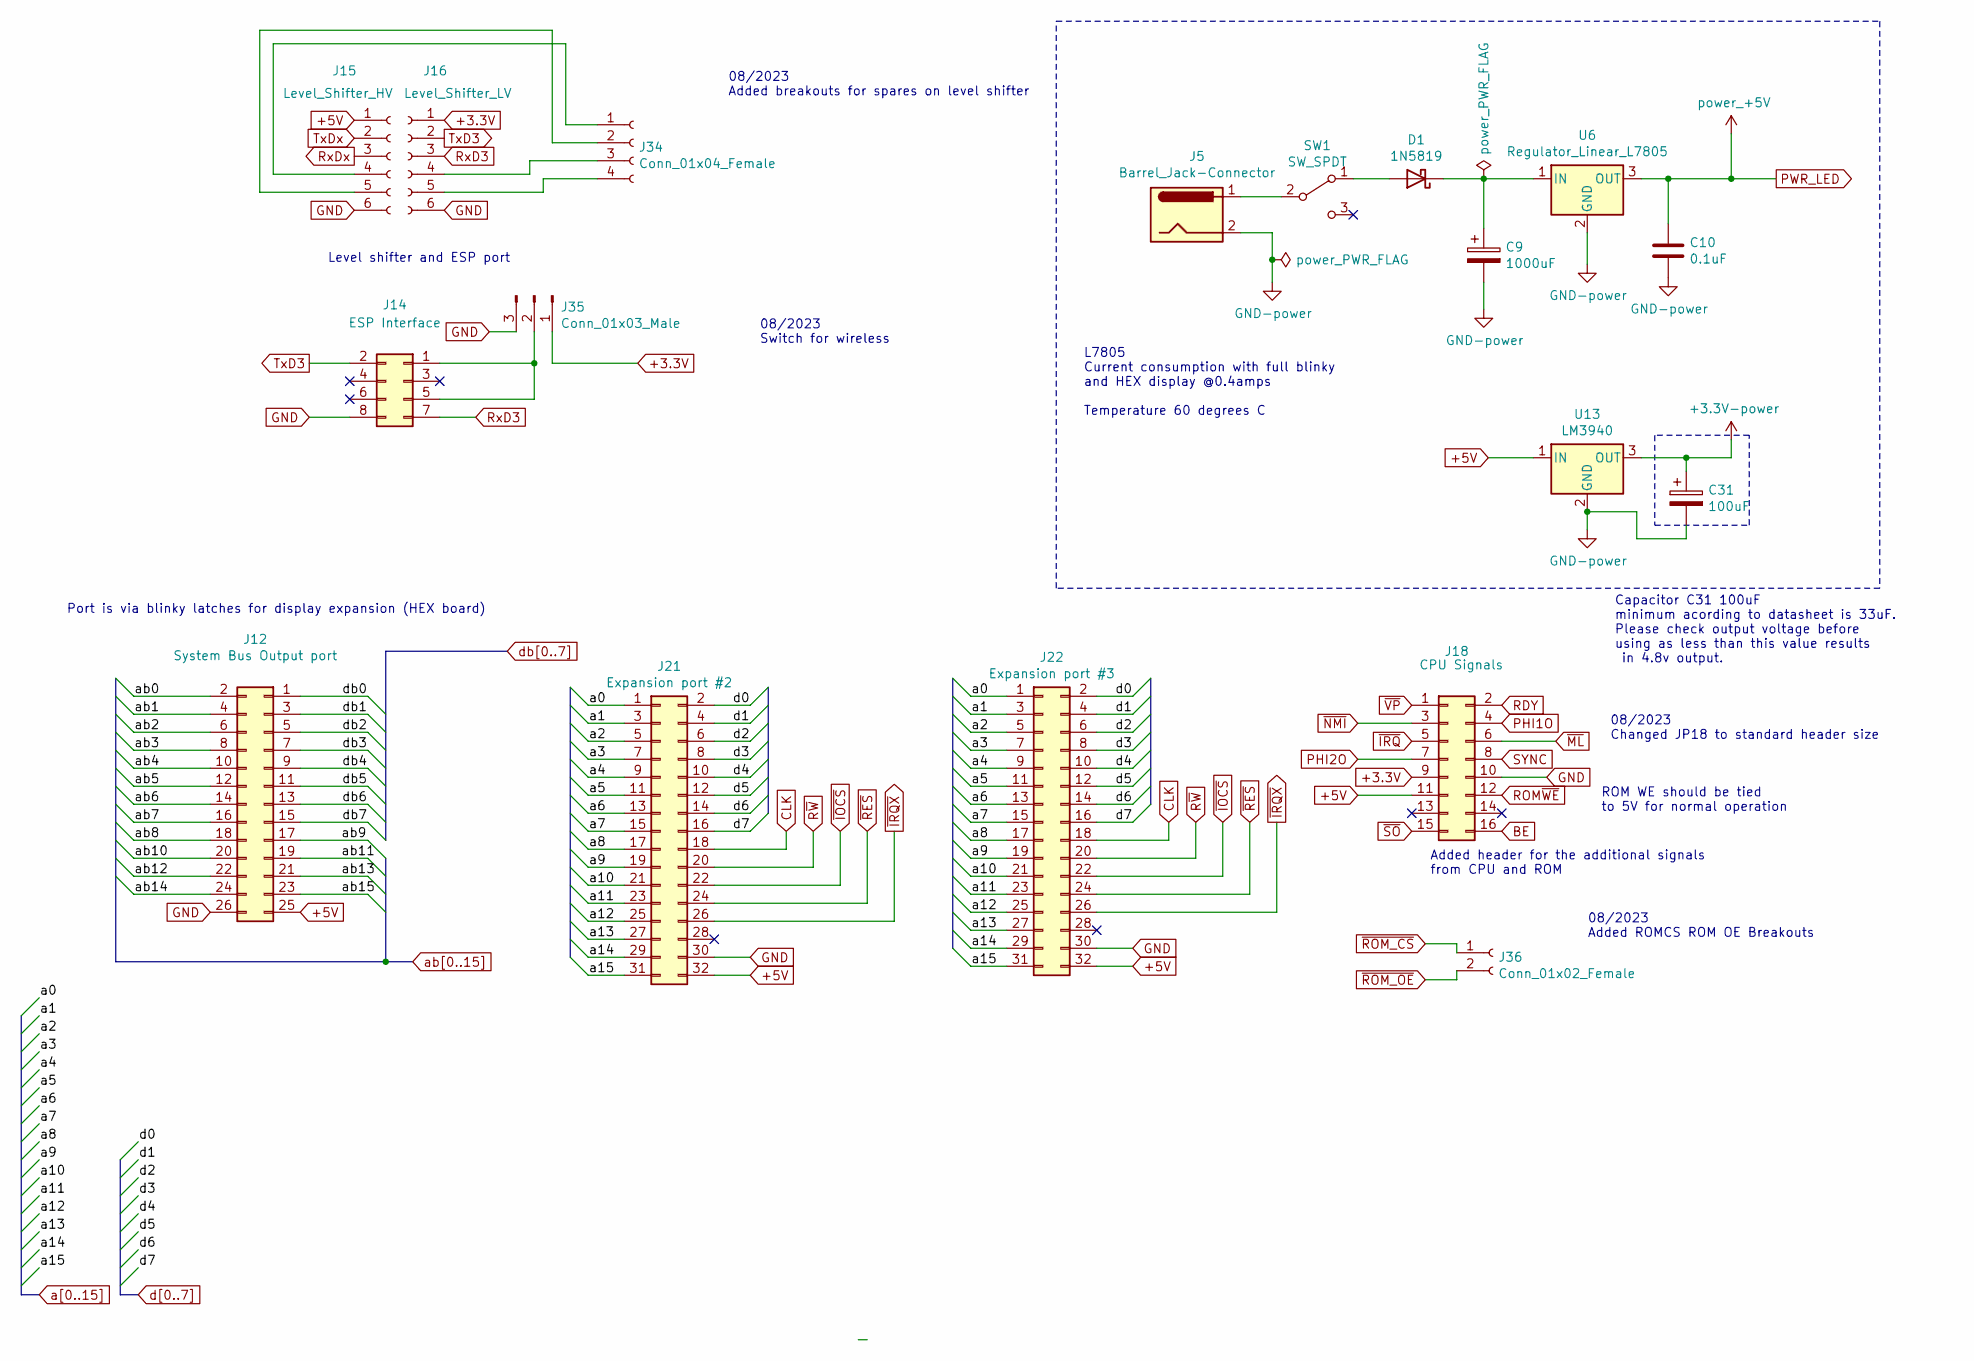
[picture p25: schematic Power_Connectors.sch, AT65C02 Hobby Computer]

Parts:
C9: 1000uF; CP_Radial_D10.0mm_P5.00mm
C10: 0.1uF; C_Disc_D3.4mm_W2.1mm_P2.50mm
C31: 100uF; CP_Radial_D5.0mm_P2.50mm
D1: 1N5819; D_DO-41_SOD81_P10.16mm_Horizontal
J5: Barrel_Jack-Connector; BarrelJack_Horizontal
J12: System Bus Output port; PinSocket_2x13_P2.54mm_Vertical
J14: ESP Interface; PinSocket_2x04_P2.54mm_Vertical
J15: Level_Shifter_HV; PinSocket_1x06_P2.54mm_Vertical
J16: Level_Shifter_LV; PinSocket_1x06_P2.54mm_Vertical
J18: CPU Signals; PinSocket_2x08_P2.54mm_Vertical
J21: Expansion port #2; PinSocket_2x16_P2.54mm_Vertical
J22: Expansion port #3; PinSocket_2x16_P2.54mm_Vertical
J34: Conn_01x04_Female; PinSocket_1x04_P2.54mm_Vertical
J35: Conn_01x03_Male; PinHeader_1x03_P2.54mm_Vertical
J36: Conn_01x02_Female; PinSocket_1x02_P2.54mm_Vertical
SW1: SW_SPDT; PinHeader_1x03_P2.54mm_Vertical
U6: Regulator_Linear_L7805; TO-220-3_Horizontal_TabDown
U13: LM3940; TO-220-3_Horizontal_TabDown

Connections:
BE: J18.16; also elsewhere on the board
CLK: J21.18, J22.18; also elsewhere on the board
unnamed: C9.1, D1.1 (K), U6.1 (IN)
unnamed: D1.2 (A), SW1.1 (A)
unnamed: J5.1, SW1.2 (B)
unnamed: J14.1, J14.5, J35.2
unnamed: J15.4, J34.1
unnamed: J15.5, J34.2
unnamed: J16.4, J34.3
unnamed: J16.5, J34.4
PHI1O: J18.4; also elsewhere on the board
PHI2O: J18.7; also elsewhere on the board
RDY: J18.2; also elsewhere on the board
ROM~WE: J18.12; also elsewhere on the board
RxD: J15.3; also elsewhere on the board
RxD3: J14.7, J16.3
R~W: J21.20, J22.20; also elsewhere on the board
SYNC: J18.8; also elsewhere on the board
TxD: J15.2; also elsewhere on the board
TxD3: J14.2, J16.2
a0: J21.1, J22.1; also elsewhere on the board
a1: J21.3, J22.3; also elsewhere on the board
a2: J21.5, J22.5; also elsewhere on the board
a3: J21.7, J22.7; also elsewhere on the board
a4: J21.9, J22.9; also elsewhere on the board
a5: J21.11, J22.11; also elsewhere on the board
a6: J21.13, J22.13; also elsewhere on the board
a7: J21.15, J22.15; also elsewhere on the board
a8: J21.17, J22.17; also elsewhere on the board
a9: J21.19, J22.19; also elsewhere on the board
a10: J21.21, J22.21; also elsewhere on the board
a11: J21.23, J22.23; also elsewhere on the board
a12: J21.25, J22.25; also elsewhere on the board
a13: J21.27, J22.27; also elsewhere on the board
a14: J21.29, J22.29; also elsewhere on the board
a15: J21.31, J22.31; also elsewhere on the board
ab0: J12.2; also elsewhere on the board
ab1: J12.4; also elsewhere on the board
ab2: J12.6; also elsewhere on the board
ab3: J12.8; also elsewhere on the board
ab4: J12.10; also elsewhere on the board
ab5: J12.12; also elsewhere on the board
ab6: J12.14; also elsewhere on the board
ab7: J12.16; also elsewhere on the board
ab8: J12.18; also elsewhere on the board
ab9: J12.17; also elsewhere on the board
ab10: J12.20; also elsewhere on the board
ab11: J12.19; also elsewhere on the board
ab12: J12.22; also elsewhere on the board
ab13: J12.21; also elsewhere on the board
ab14: J12.24; also elsewhere on the board
ab15: J12.23; also elsewhere on the board
d0: J21.2, J22.2; also elsewhere on the board
d1: J21.4, J22.4; also elsewhere on the board
d2: J21.6, J22.6; also elsewhere on the board
d3: J21.8, J22.8; also elsewhere on the board
d4: J21.10, J22.10; also elsewhere on the board
d5: J21.12, J22.12; also elsewhere on the board
d6: J21.14, J22.14; also elsewhere on the board
d7: J21.16, J22.16; also elsewhere on the board
db0: J12.1; also elsewhere on the board
db1: J12.3; also elsewhere on the board
db2: J12.5; also elsewhere on the board
db3: J12.7; also elsewhere on the board
db4: J12.9; also elsewhere on the board
db5: J12.11; also elsewhere on the board
db6: J12.13; also elsewhere on the board
db7: J12.15; also elsewhere on the board
~IOCS: J21.22, J22.22; also elsewhere on the board
~IRQ: J18.5; also elsewhere on the board
~IRQX: J21.26, J22.26; also elsewhere on the board
~ML: J18.6; also elsewhere on the board
~NMI: J18.3; also elsewhere on the board
~RES: J21.24, J22.24; also elsewhere on the board
~ROM_CS: J36.1; also elsewhere on the board
~ROM_OE: J36.2; also elsewhere on the board
~SO: J18.15; also elsewhere on the board
~VP: J18.1; also elsewhere on the board

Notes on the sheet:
Port is via blinky latches for display expansion (HEX board)
Level shifter and ESP port
L7805 Current consumption with full blinky and HEX display @0.4amps Temperature 60 degrees C
Added header for the additional signals from CPU and ROM
Capacitor C31 100uF minimum acording to datasheet is 33uF. Please check output voltage before using as less than this value results in 4.8v output.
ROM WE should be tied to 5V for normal operation
08/2023 Switch for wireless
08/2023 Added breakouts for spares on level shifter
08/2023 Changed JP18 to standard header size
08/2023 Added ROMCS ROM OE Breakouts

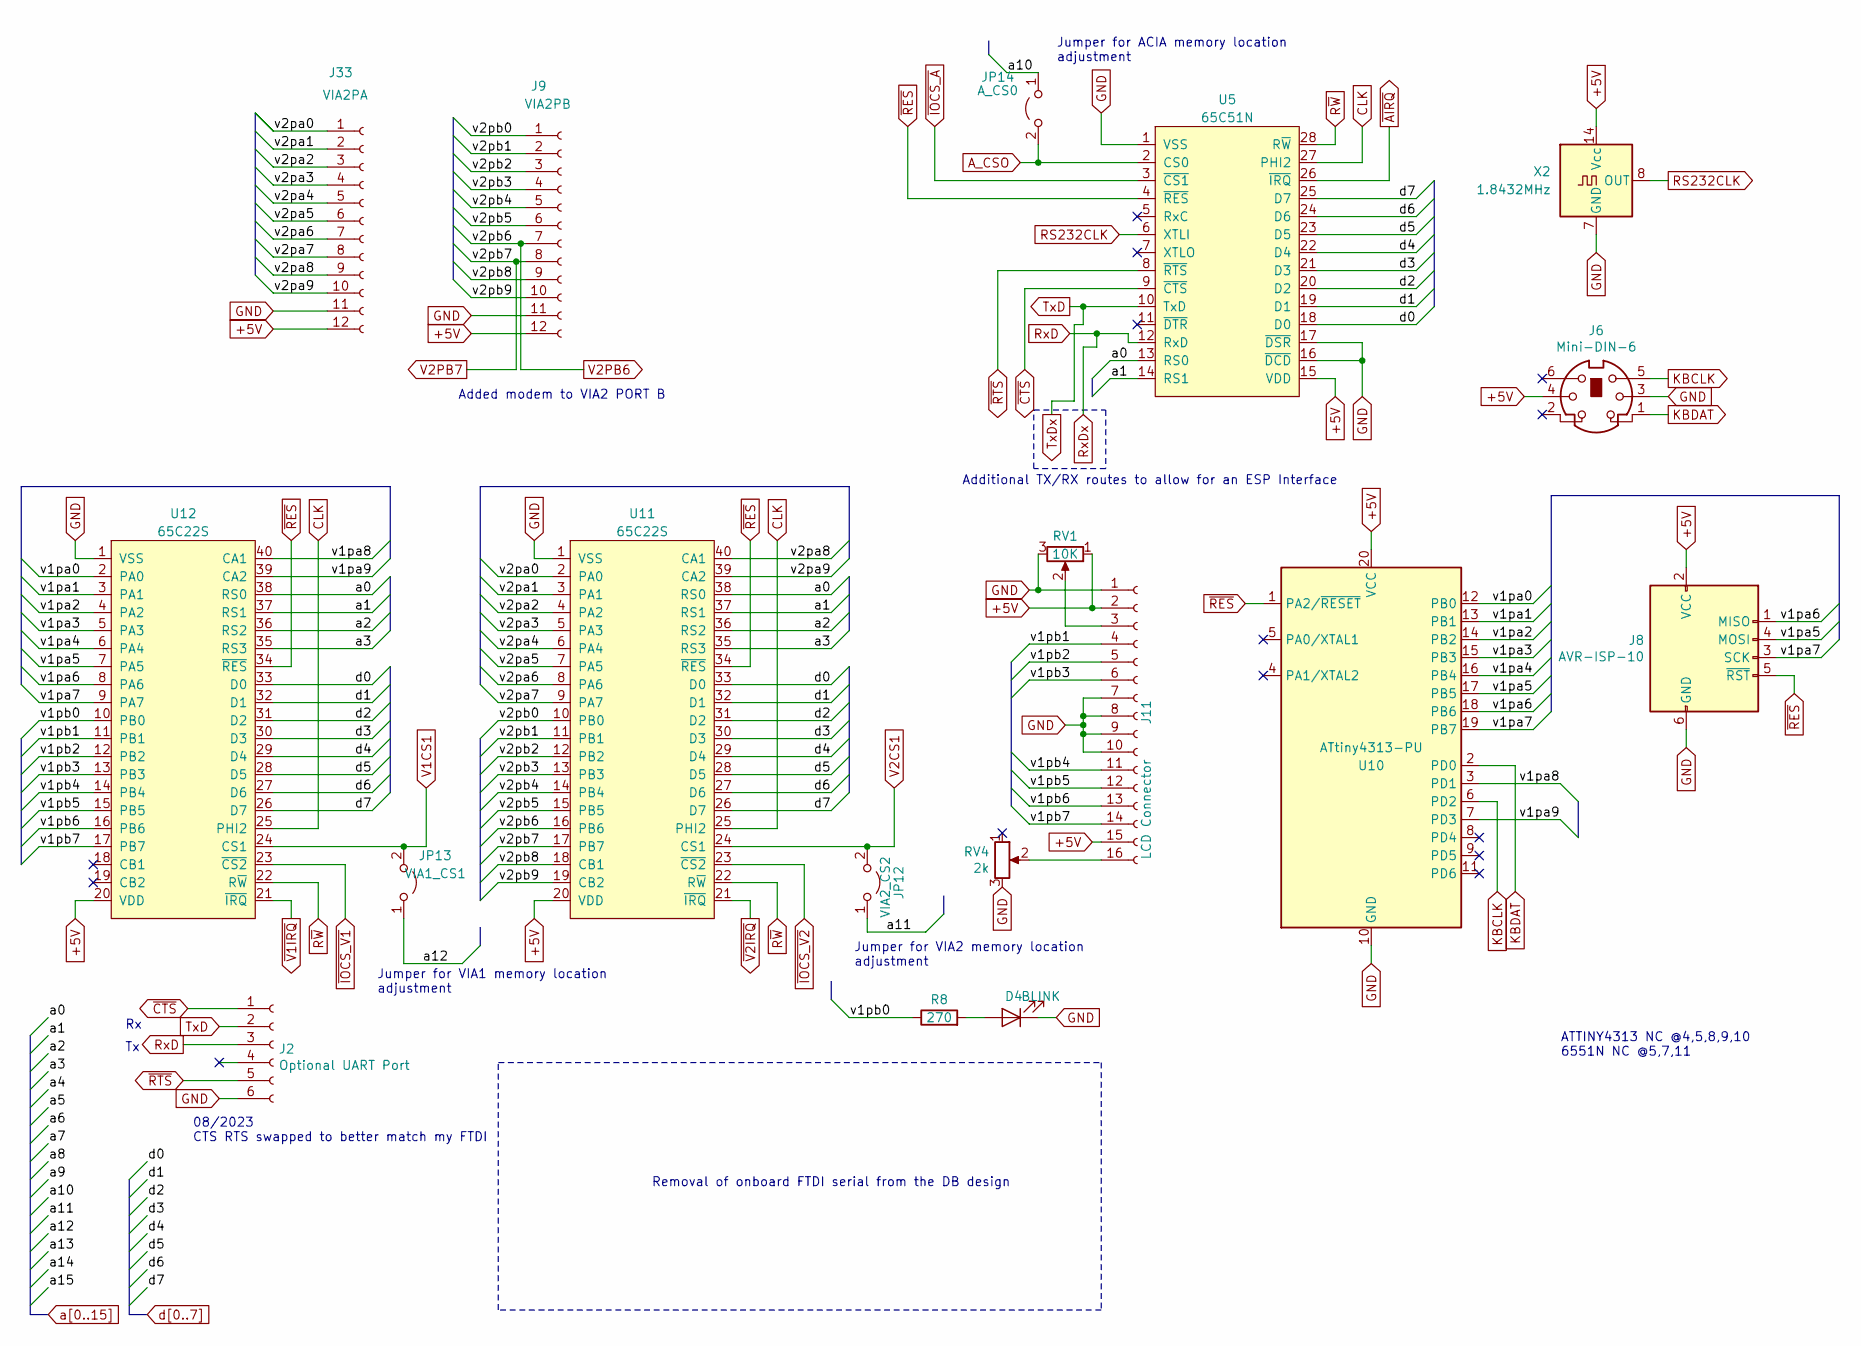
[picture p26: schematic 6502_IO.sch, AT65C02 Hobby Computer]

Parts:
D4: BLINK; LED_D3.0mm
J2: Optional UART Port; PinSocket_1x06_P2.54mm_Vertical
J6: Mini-DIN-6; mini_din-6
J8: AVR-ISP-10; PinHeader_2x03_P2.54mm_Vertical
J9: VIA2PB; PinSocket_1x12_P2.54mm_Vertical
J11: LCD Connector; PinSocket_1x16_P2.54mm_Vertical
J33: VIA2PA; PinSocket_1x12_P2.54mm_Vertical
JP12: VIA2_CS2; PinHeader_1x02_P2.54mm_Vertical
JP13: VIA1_CS1; PinHeader_1x02_P2.54mm_Vertical
JP14: A_CS0; PinHeader_1x02_P2.54mm_Vertical
R8: 270; R_Axial_DIN0207_L6.3mm_D2.5mm_P7.62mm_Horizontal
RV1: 10K; Potentiometer_Piher_PT-10-V10_Vertical
RV4: 2k; Potentiometer_Piher_PT-10-V10_Vertical
U5: 65C51N; DIP-28_W15.24mm_Socket
U10: ATtiny4313-PU; DIP-20_W7.62mm_Socket
U11, U12: 65C22S; DIP-40_W15.24mm_Socket
X2: 1.8432MHz; Oscillator_DIP-14

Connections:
/6502 Peripherals/v1pa0: U10.12 (PB0), U12.2 (PA0)
/6502 Peripherals/v1pa1: U10.13 (PB1), U12.3 (PA1)
/6502 Peripherals/v1pa2: U10.14 (PB2), U12.4 (PA2)
/6502 Peripherals/v1pa3: U10.15 (PB3), U12.5 (PA3)
/6502 Peripherals/v1pa4: U10.16 (PB4), U12.6 (PA4)
/6502 Peripherals/v1pa5: J8.4 (MOSI), U10.17 (PB5), U12.7 (PA5)
/6502 Peripherals/v1pa6: J8.1 (MISO), U10.18 (PB6), U12.8 (PA6)
/6502 Peripherals/v1pa7: J8.3 (SCK), U10.19 (PB7), U12.9 (PA7)
/6502 Peripherals/v1pa8: U10.3 (PD1), U12.40 (CA1)
/6502 Peripherals/v1pa9: U10.7 (PD3), U12.39 (CA2)
/6502 Peripherals/v1pb0: R8.1, U12.10 (PB0)
/6502 Peripherals/v1pb1: J11.4, U12.11 (PB1)
/6502 Peripherals/v1pb2: J11.5, U12.12 (PB2)
/6502 Peripherals/v1pb3: J11.6, U12.13 (PB3)
/6502 Peripherals/v1pb4: J11.11, U12.14 (PB4)
/6502 Peripherals/v1pb5: J11.12, U12.15 (PB5)
/6502 Peripherals/v1pb6: J11.13, U12.16 (PB6)
/6502 Peripherals/v1pb7: J11.14, U12.17 (PB7)
/6502 Peripherals/v2pa0: J33.1, U11.2 (PA0)
/6502 Peripherals/v2pa1: J33.2, U11.3 (PA1)
/6502 Peripherals/v2pa2: J33.3, U11.4 (PA2)
/6502 Peripherals/v2pa3: J33.4, U11.5 (PA3)
/6502 Peripherals/v2pa4: J33.5, U11.6 (PA4)
/6502 Peripherals/v2pa5: J33.6, U11.7 (PA5)
/6502 Peripherals/v2pa6: J33.7, U11.8 (PA6)
/6502 Peripherals/v2pa7: J33.8, U11.9 (PA7)
/6502 Peripherals/v2pa8: J33.9, U11.40 (CA1)
/6502 Peripherals/v2pa9: J33.10, U11.39 (CA2)
/6502 Peripherals/v2pb0: J9.1, U11.10 (PB0)
/6502 Peripherals/v2pb1: J9.2, U11.11 (PB1)
/6502 Peripherals/v2pb2: J9.3, U11.12 (PB2)
/6502 Peripherals/v2pb3: J9.4, U11.13 (PB3)
/6502 Peripherals/v2pb4: J9.5, U11.14 (PB4)
/6502 Peripherals/v2pb5: J9.6, U11.15 (PB5)
/6502 Peripherals/v2pb8: J9.9, U11.18 (CB1)
/6502 Peripherals/v2pb9: J9.10, U11.19 (CB2)
A_CSO: JP14.2 (B), U5.2 (CS0)
CLK: U5.27 (PHI2), U11.25 (PHI2), U12.25 (PHI2); also elsewhere on the board
KBCLK: J6.5, U10.6 (PD2)
KBDAT: J6.1, U10.2 (PD0)
unnamed: D4.2 (A), R8.2
unnamed: J11.3, RV1.2
unnamed: J11.16, RV4.2
RS232CLK: U5.6 (XTLI), X2.8 (OUT)
RxD: J2.3, U5.12 (RxD); also elsewhere on the board
R~W: U5.28 (R~W), U11.22 (R~W), U12.22 (R~W); also elsewhere on the board
TxD: J2.2, U5.10 (TxD); also elsewhere on the board
V1CS1: JP13.2 (B), U12.24 (CS1)
V2CS1: JP12.2 (B), U11.24 (CS1)
V2PB6: J9.7, U11.16 (PB6); also elsewhere on the board
V2PB7: J9.8, U11.17 (PB7); also elsewhere on the board
a0: U5.13 (RS0), U11.38 (RS0), U12.38 (RS0); also elsewhere on the board
a1: U5.14 (RS1), U11.37 (RS1), U12.37 (RS1); also elsewhere on the board
a2: U11.36 (RS2), U12.36 (RS2); also elsewhere on the board
a3: U11.35 (RS3), U12.35 (RS3); also elsewhere on the board
a10: JP14.1 (A); also elsewhere on the board
a11: JP12.1 (A); also elsewhere on the board
a12: JP13.1 (A); also elsewhere on the board
d0: U5.18 (D0), U11.33 (D0), U12.33 (D0); also elsewhere on the board
d1: U5.19 (D1), U11.32 (D1), U12.32 (D1); also elsewhere on the board
d2: U5.20 (D2), U11.31 (D2), U12.31 (D2); also elsewhere on the board
d3: U5.21 (D3), U11.30 (D3), U12.30 (D3); also elsewhere on the board
d4: U5.22 (D4), U11.29 (D4), U12.29 (D4); also elsewhere on the board
d5: U5.23 (D5), U11.28 (D5), U12.28 (D5); also elsewhere on the board
d6: U5.24 (D6), U11.27 (D6), U12.27 (D6); also elsewhere on the board
d7: U5.25 (D7), U11.26 (D7), U12.26 (D7); also elsewhere on the board
~AIRQ: U5.26 (~IRQ); also elsewhere on the board
~CTS: J2.1, U5.9 (~CTS)
~IOCS_A: U5.3 (~CS1); also elsewhere on the board
~IOCS_V1: U12.23 (~CS2); also elsewhere on the board
~IOCS_V2: U11.23 (~CS2); also elsewhere on the board
~RES: J8.5 (~RST), U5.4 (~RES), U10.1 (PA2/~RESET), U11.34 (~RES), U12.34 (~RES); also elsewhere on the board
~RTS: J2.5, U5.8 (~RTS)
~V1IRQ: U12.21 (~IRQ); also elsewhere on the board
~V2IRQ: U11.21 (~IRQ); also elsewhere on the board

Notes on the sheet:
Added modem to VIA2 PORT B
Additional TX/RX routes to allow for an ESP Interface
Removal of onboard FTDI serial from the DB design
Jumper for VIA1 memory location adjustment
Jumper for VIA2 memory location adjustment
Jumper for ACIA memory location adjustment
ATTINY4313 NC @4,5,8,9,10 6551N NC @5,7,11
08/2023 CTS RTS swapped to better match my FTDI

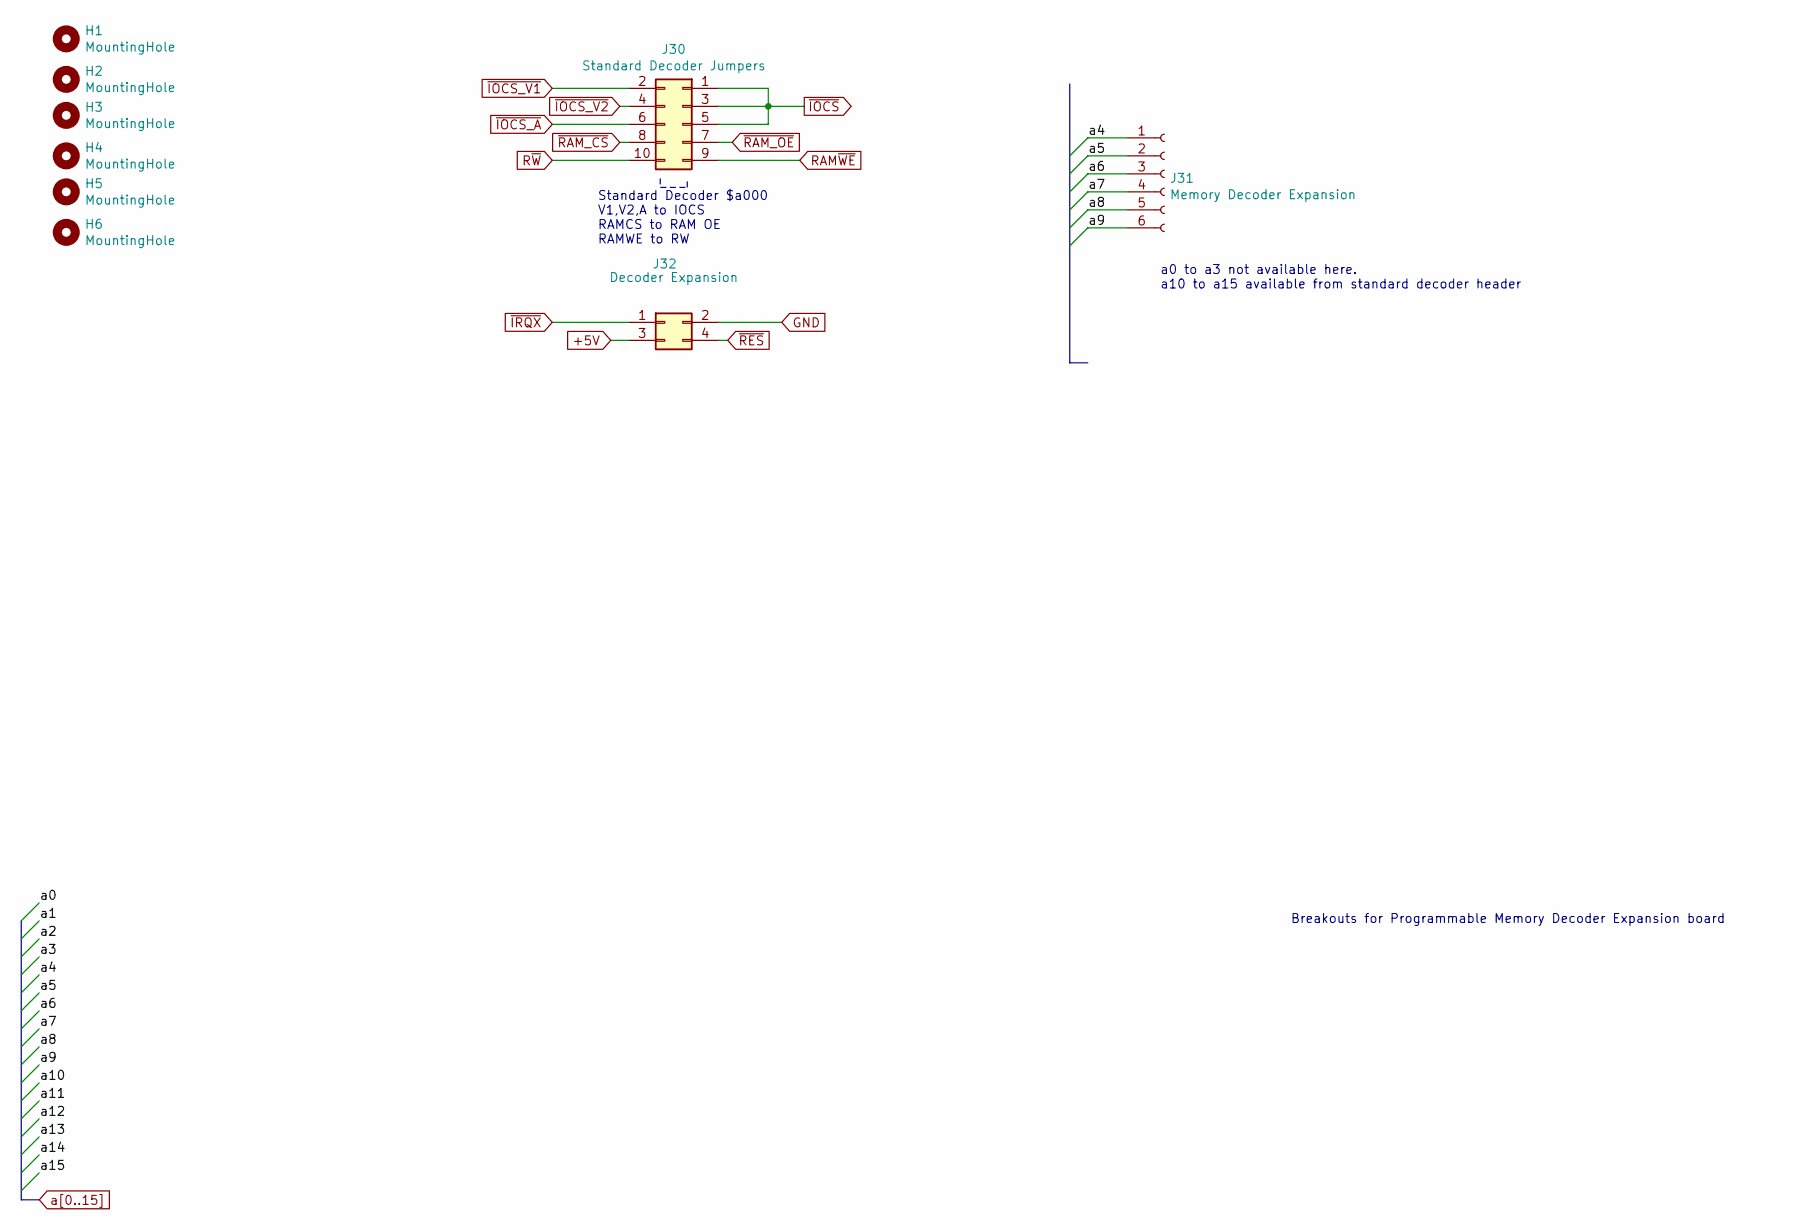
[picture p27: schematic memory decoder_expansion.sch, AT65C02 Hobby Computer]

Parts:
H1, H2, H3, H4, H5, H6: MountingHole; MountingHole_3mm_Pad
J30: Standard Decoder Jumpers; PinHeader_2x05_P2.54mm_Vertical
J31: Memory Decoder Expansion; PinSocket_1x06_P2.54mm_Vertical
J32: Decoder Expansion; PinSocket_2x02_P2.54mm_Vertical

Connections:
RAM~WE~: J30.9; also elsewhere on the board
R~W: J30.10; also elsewhere on the board
a4: J31.1; also elsewhere on the board
a5: J31.2; also elsewhere on the board
a6: J31.3; also elsewhere on the board
a7: J31.4; also elsewhere on the board
a8: J31.5; also elsewhere on the board
a9: J31.6; also elsewhere on the board
~IOCS: J30.1, J30.3, J30.5; also elsewhere on the board
~IOCS_A: J30.6; also elsewhere on the board
~IOCS_V1: J30.2; also elsewhere on the board
~IOCS_V2: J30.4; also elsewhere on the board
~IRQX: J32.1; also elsewhere on the board
~RAM_CS: J30.8; also elsewhere on the board
~RAM_OE: J30.7; also elsewhere on the board
~RES: J32.4; also elsewhere on the board

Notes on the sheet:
Standard Decoder $a000 V1,V2,A to IOCS RAMCS to RAM OE RAMWE to RW
Breakouts for Programmable Memory Decoder Expansion board
a0 to a3 not available here. a10 to a15 available from standard decoder header

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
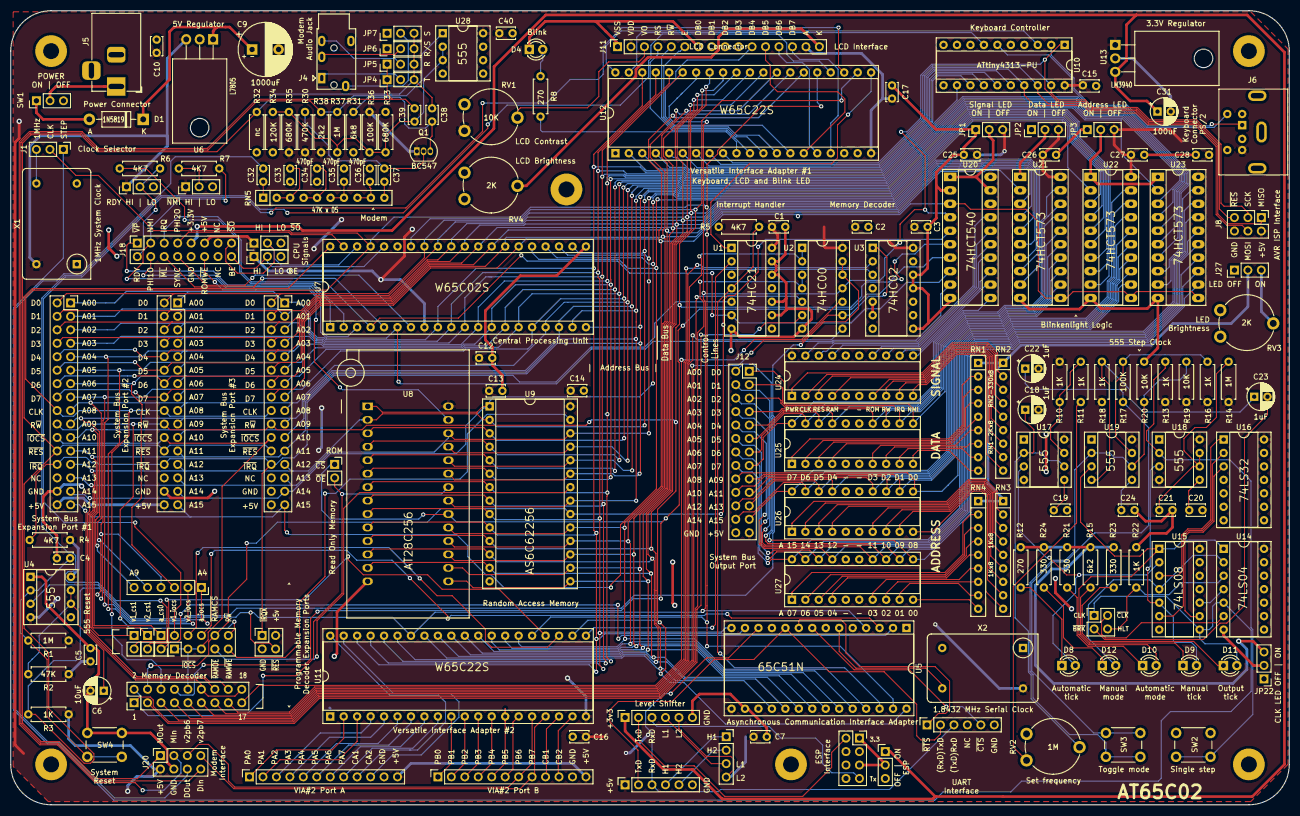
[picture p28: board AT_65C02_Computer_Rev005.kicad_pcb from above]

Board: 2 copper layers, 241.3 x 149.9 mm, 167 parts (0 on the bottom side), 245 nets.

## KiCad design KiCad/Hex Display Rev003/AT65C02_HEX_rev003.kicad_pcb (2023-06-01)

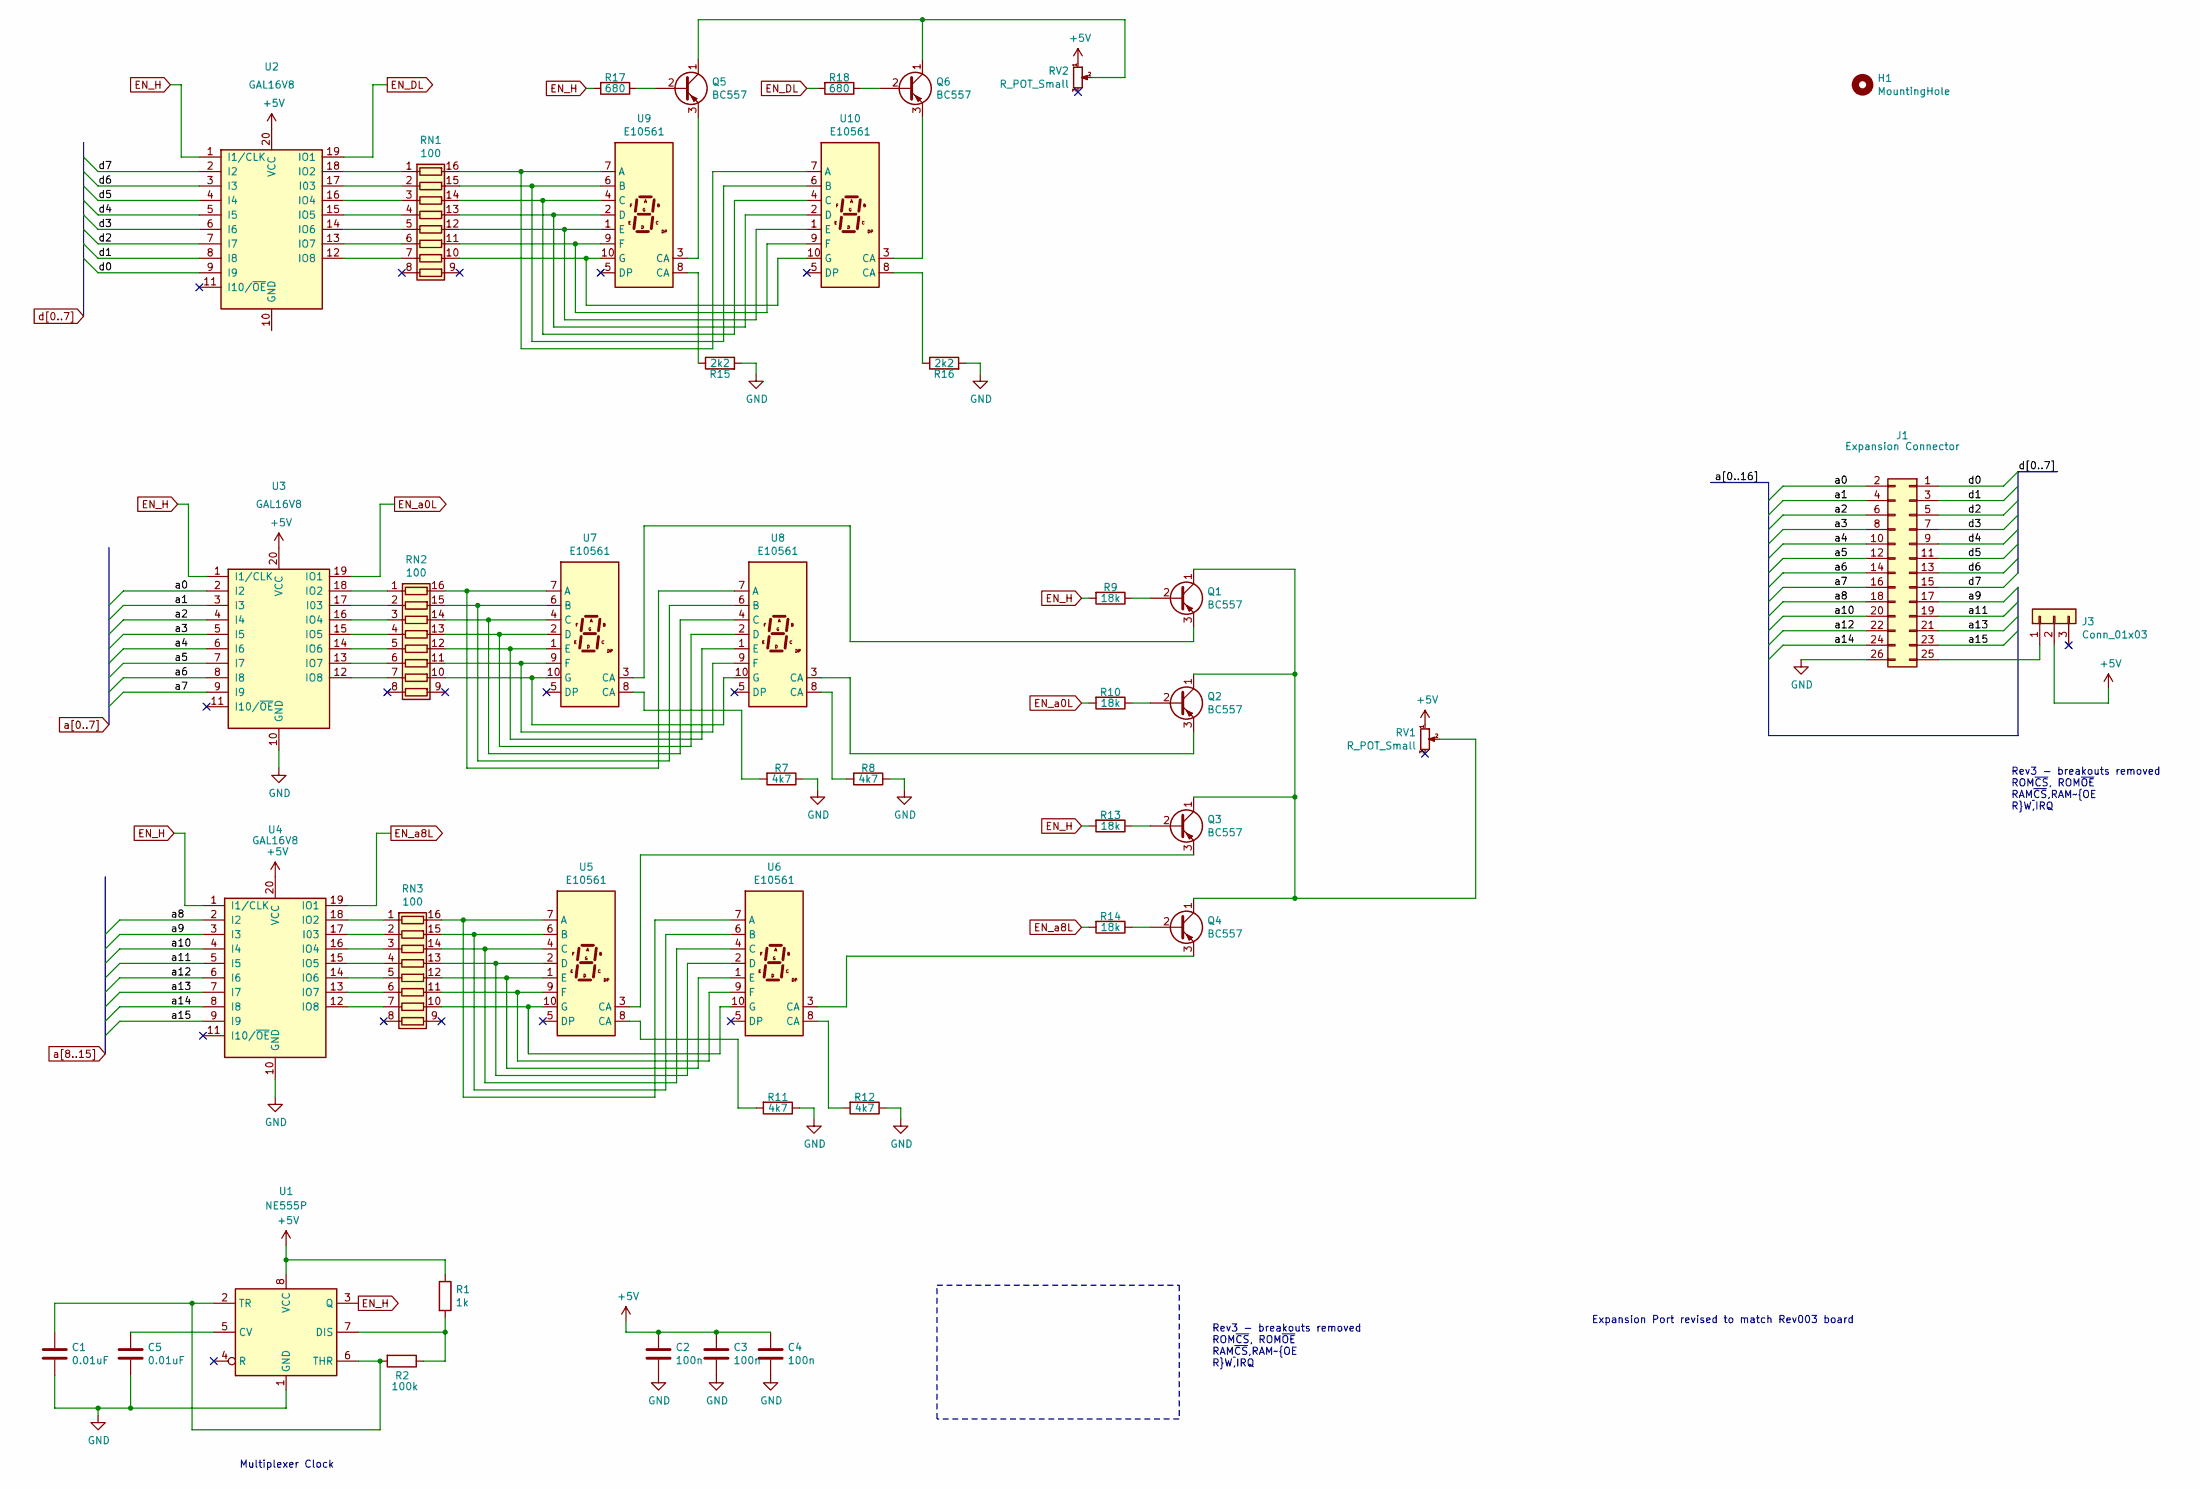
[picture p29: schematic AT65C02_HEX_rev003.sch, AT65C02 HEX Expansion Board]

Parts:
C1, C5: 0.01uF; C_Disc_D5.0mm_W2.5mm_P5.00mm
C2, C3, C4: 100n; C_Disc_D5.0mm_W2.5mm_P5.00mm
H1: MountingHole; MountingHole_2.2mm_M2
J1: Expansion Connector; PinHeader_2x13_P2.54mm_Vertical
J3: Conn_01x03; PinHeader_1x03_P2.54mm_Vertical
Q1, Q2, Q3, Q4, Q5, Q6: BC557; TO-92_Inline
R1: 1k; R_Axial_DIN0207_L6.3mm_D2.5mm_P7.62mm_Horizontal
R2: 100k; R_Axial_DIN0207_L6.3mm_D2.5mm_P7.62mm_Horizontal
R7, R8, R11, R12: 4k7; R_Axial_DIN0207_L6.3mm_D2.5mm_P7.62mm_Horizontal
R9, R10, R13, R14: 18k; R_Axial_DIN0207_L6.3mm_D2.5mm_P7.62mm_Horizontal
R15, R16: 2k2; R_Axial_DIN0207_L6.3mm_D2.5mm_P7.62mm_Horizontal
R17, R18: 680; R_Axial_DIN0207_L6.3mm_D2.5mm_P7.62mm_Horizontal
RN1, RN2, RN3: 100; DIP-16_W7.62mm_Socket
RV1, RV2: R_POT_Small; Potentiometer_Piher_PT-10-V10_Vertical
U1: NE555P; DIP-8_W7.62mm_Socket
U2, U3, U4: GAL16V8; DIP-20_W7.62mm_Socket
U5, U6, U7, U8, U9, U10: E10561; 7SegmentLED_LTS6760_LTS6780

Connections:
+5V: C2.1, C3.1, C4.1, J3.2, R1.1, RV1.1, RV2.1, U1.8 (VCC), U2.20 (VCC), U3.20 (VCC), U4.20 (VCC)
EN_DL: R18.2, U2.19 (IO1)
EN_H: R9.2, R13.2, R17.2, U1.3 (Q), U2.1 (I1/CLK), U3.1 (I1/CLK), U4.1 (I1/CLK)
EN_a0L: R10.2, U3.19 (IO1)
EN_a8L: R14.2, U4.19 (IO1)
GND: C1.2, C2.2, C3.2, C4.2, C5.2, J1.26, R7.1, R8.1, R11.1, R12.1, R15.2, R16.2, U1.1 (GND), U3.10 (GND), U4.10 (GND)
unnamed: C1.1, R2.2, U1.2 (TR), U1.6 (THR)
unnamed: C5.1, U1.5 (CV)
unnamed: J1.25, J3.1
unnamed: Q1.1 (C), Q2.1 (C), Q3.1 (C), Q4.1 (C), RV1.2
unnamed: Q1.2 (B), R9.1
unnamed: Q1.3 (E), U7.3 (CA)
unnamed: Q2.2 (B), R10.1
unnamed: Q2.3 (E), U8.3 (CA)
unnamed: Q3.2 (B), R13.1
unnamed: Q3.3 (E), U5.3 (CA)
unnamed: Q4.2 (B), R14.1
unnamed: Q4.3 (E), U6.3 (CA)
unnamed: Q5.1 (C), Q6.1 (C), RV2.2
unnamed: Q5.2 (B), R17.1
unnamed: Q5.3 (E), U9.3 (CA)
unnamed: Q6.2 (B), R18.1
unnamed: Q6.3 (E), U10.3 (CA)
unnamed: R1.2, R2.1, U1.7 (DIS)
unnamed: R7.2, U7.8 (CA)
unnamed: R8.2, U8.8 (CA)
unnamed: R11.2, U5.8 (CA)
unnamed: R12.2, U6.8 (CA)
unnamed: R15.1, U9.8 (CA)
unnamed: R16.1, U10.8 (CA)
unnamed: RN1.1 (R1.1), U2.18 (IO2)
unnamed: RN1.2 (R2.1), U2.17 (I03)
unnamed: RN1.3 (R3.1), U2.16 (IO4)
unnamed: RN1.4 (R4.1), U2.15 (IO5)
unnamed: RN1.5 (R5.1), U2.14 (IO6)
unnamed: RN1.6 (R6.1), U2.13 (IO7)
unnamed: RN1.7 (R7.1), U2.12 (IO8)
unnamed: RN1.10 (R7.2), U9.10 (G), U10.10 (G)
unnamed: RN1.11 (R6.2), U9.9 (F), U10.9 (F)
unnamed: RN1.12 (R5.2), U9.1 (E), U10.1 (E)
unnamed: RN1.13 (R4.2), U9.2 (D), U10.2 (D)
unnamed: RN1.14 (R3.2), U9.4 (C), U10.4 (C)
unnamed: RN1.15 (R2.2), U9.6 (B), U10.6 (B)
unnamed: RN1.16 (R1.2), U9.7 (A), U10.7 (A)
unnamed: RN2.1 (R1.1), U3.18 (IO2)
unnamed: RN2.2 (R2.1), U3.17 (I03)
unnamed: RN2.3 (R3.1), U3.16 (IO4)
unnamed: RN2.4 (R4.1), U3.15 (IO5)
unnamed: RN2.5 (R5.1), U3.14 (IO6)
unnamed: RN2.6 (R6.1), U3.13 (IO7)
unnamed: RN2.7 (R7.1), U3.12 (IO8)
unnamed: RN2.10 (R7.2), U7.10 (G), U8.10 (G)
unnamed: RN2.11 (R6.2), U7.9 (F), U8.9 (F)
unnamed: RN2.12 (R5.2), U7.1 (E), U8.1 (E)
unnamed: RN2.13 (R4.2), U7.2 (D), U8.2 (D)
unnamed: RN2.14 (R3.2), U7.4 (C), U8.4 (C)
unnamed: RN2.15 (R2.2), U7.6 (B), U8.6 (B)
unnamed: RN2.16 (R1.2), U7.7 (A), U8.7 (A)
unnamed: RN3.1 (R1.1), U4.18 (IO2)
unnamed: RN3.2 (R2.1), U4.17 (I03)
unnamed: RN3.3 (R3.1), U4.16 (IO4)
unnamed: RN3.4 (R4.1), U4.15 (IO5)
unnamed: RN3.5 (R5.1), U4.14 (IO6)
unnamed: RN3.6 (R6.1), U4.13 (IO7)
unnamed: RN3.7 (R7.1), U4.12 (IO8)
unnamed: RN3.10 (R7.2), U5.10 (G), U6.10 (G)
unnamed: RN3.11 (R6.2), U5.9 (F), U6.9 (F)
unnamed: RN3.12 (R5.2), U5.1 (E), U6.1 (E)
unnamed: RN3.13 (R4.2), U5.2 (D), U6.2 (D)
unnamed: RN3.14 (R3.2), U5.4 (C), U6.4 (C)
unnamed: RN3.15 (R2.2), U5.6 (B), U6.6 (B)
unnamed: RN3.16 (R1.2), U5.7 (A), U6.7 (A)
a0: J1.2, U3.2 (I2)
a1: J1.4, U3.3 (I3)
a2: J1.6, U3.4 (I4)
a3: J1.8, U3.5 (I5)
a4: J1.10, U3.6 (I6)
a5: J1.12, U3.7 (I7)
a6: J1.14, U3.8 (I8)
a7: J1.16, U3.9 (I9)
a8: J1.18, U4.2 (I2)
a9: J1.17, U4.3 (I3)
a10: J1.20, U4.4 (I4)
a11: J1.19, U4.5 (I5)
a12: J1.22, U4.6 (I6)
a13: J1.21, U4.7 (I7)
a14: J1.24, U4.8 (I8)
a15: J1.23, U4.9 (I9)
d0: J1.1, U2.9 (I9)
d1: J1.3, U2.8 (I8)
d2: J1.5, U2.7 (I7)
d3: J1.7, U2.6 (I6)
d4: J1.9, U2.5 (I5)
d5: J1.11, U2.4 (I4)
d6: J1.13, U2.3 (I3)
d7: J1.15, U2.2 (I2)

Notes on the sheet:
Expansion Port revised to match Rev003 board
Multiplexer Clock
Rev3 - breakouts removed ROM~CS~, ROM~OE~ RAM~CS~,RAM~OE R~W~,~IRQ~

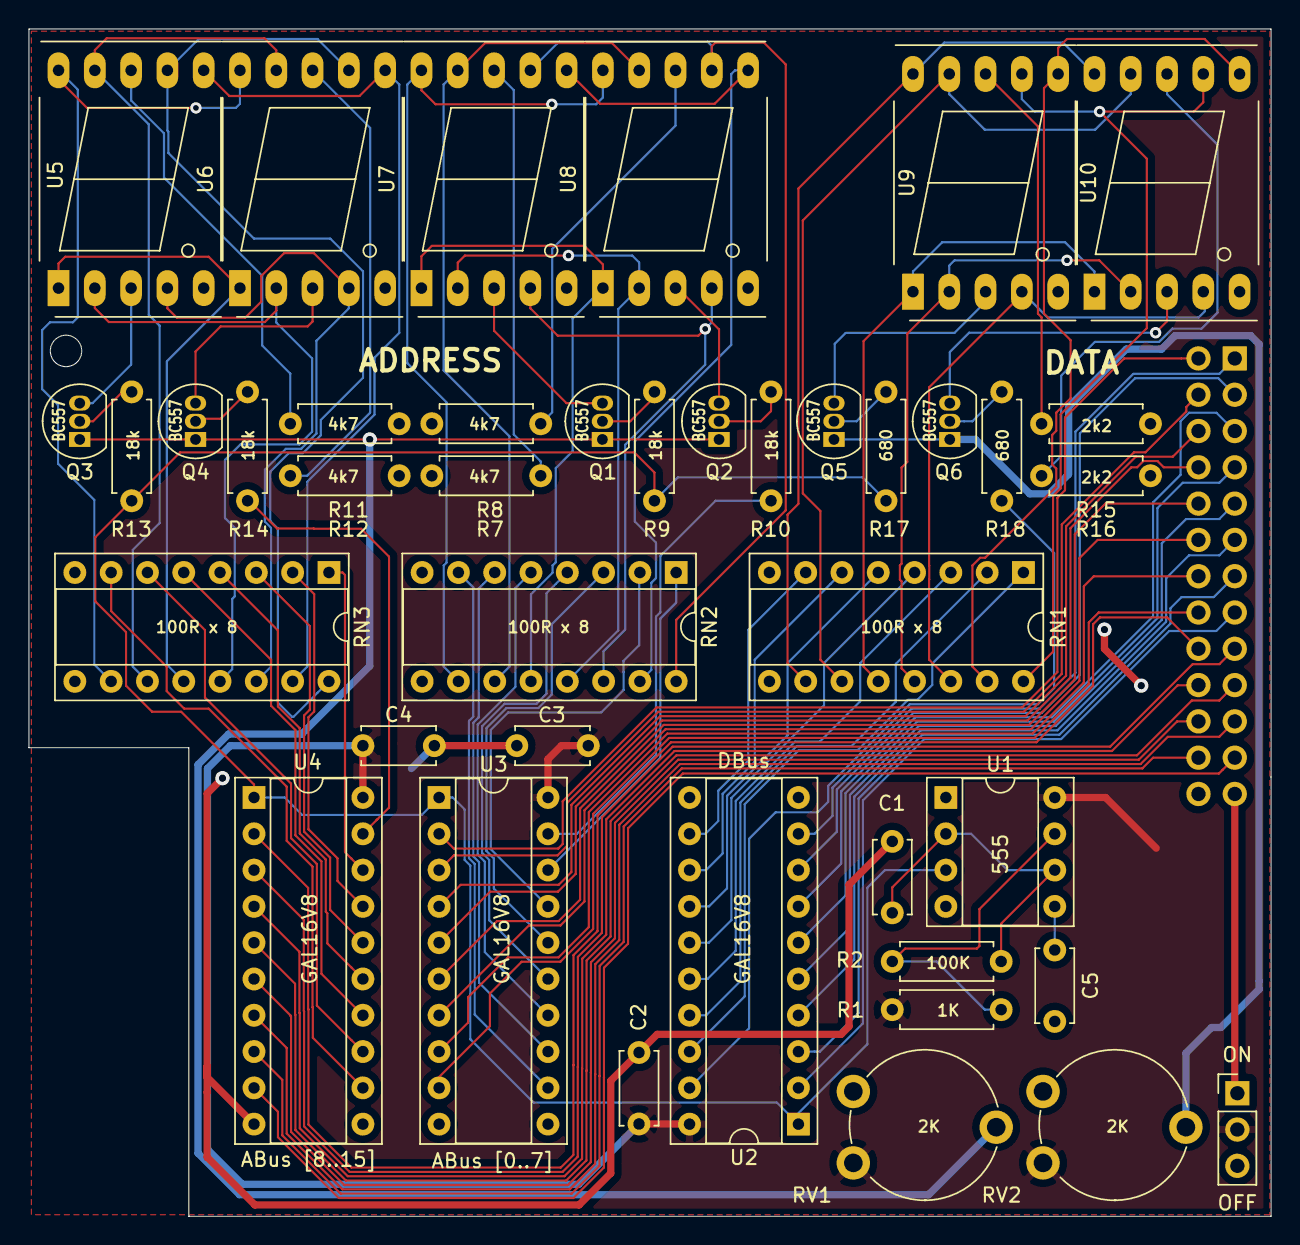
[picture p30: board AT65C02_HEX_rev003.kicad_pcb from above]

Board: 2 copper layers, 86.9 x 83.1 mm, 43 parts (1 on the bottom side), 96 nets.

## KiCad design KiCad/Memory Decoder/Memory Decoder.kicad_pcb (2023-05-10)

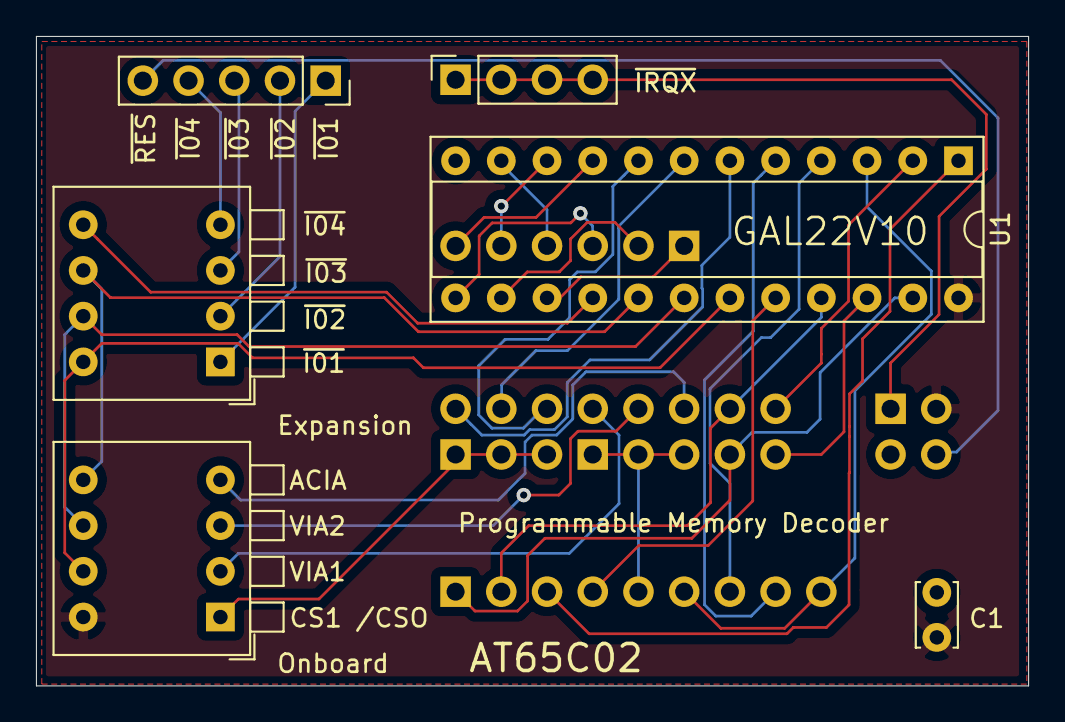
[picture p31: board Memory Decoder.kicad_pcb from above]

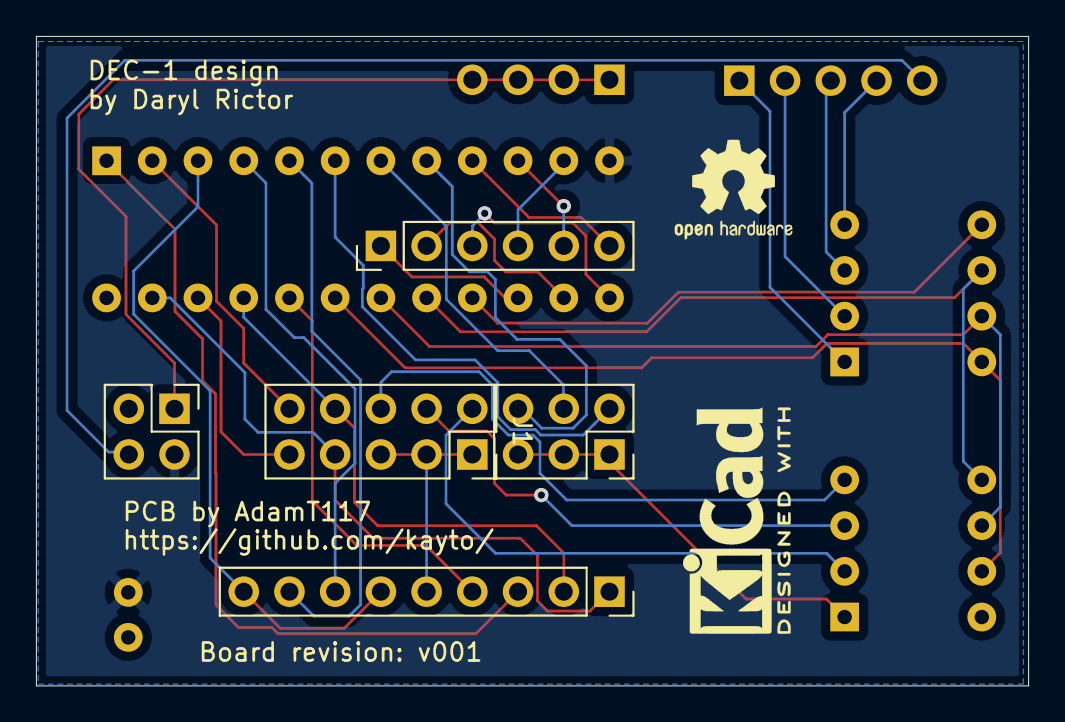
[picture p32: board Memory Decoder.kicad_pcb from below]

Board: 2 copper layers, 55.1 x 36.1 mm, 11 parts (5 on the bottom side), 35 nets.

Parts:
C1: 0.1uF; C_Disc_D3.4mm_W2.1mm_P2.50mm
J1: IOCS/Decoder Signals Expansion #5; PinSocket_2x05_P2.54mm_Vertical
J2: Conn_02x02_Odd_Even; PinHeader_2x02_P2.54mm_Vertical
J3: Decoder Signals; PinSocket_1x09_P2.54mm_Vertical
J4: Conn_02x03_Odd_Even; PinSocket_2x03_P2.54mm_Vertical
J5: Memory Decoder Expansion; PinHeader_1x06_P2.54mm_Vertical
J6: ~CS1~; PinSocket_1x05_P2.54mm_Vertical
J7: ~CS1~; PinSocket_1x04_P2.54mm_Vertical
SW1, SW2: SW_DIP_x04; SW_DIP_SPSTx04_Piano_10.8x11.72mm_W7.62mm_P2.54mm
U1: Flexible Memory Decoder; DIP-24_W7.62mm_Socket

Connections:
+5V: C1.1, J2.3, SW1.8, U1.24
/a4: J5.1, U1.15
/a5: J5.2, U1.14
/a6: J5.3, U1.13
/a7: J5.4, U1.11
/a8: J5.5, U1.10
/a9: J5.6, U1.9
/a10: J4.6, U1.8
/a11: J4.4, U1.7
/a12: J4.2, U1.6
/a13: J3.8, U1.5
/a14: J3.7, U1.4
/a15: J3.6, J3.9, U1.3
A_CSO: J4.1, J4.3, J4.5, SW1.1
CLK: J3.3, U1.1
GND: C1.2, J2.2, U1.12
RAM~WE: J1.9, U1.22
R~W: J1.10, U1.2
~IO1: SW1.7, SW2.8, U1.19
~IO1x: J6.1, SW2.1
~IO2: SW1.6, SW2.7, U1.18
~IO2x: J6.2, SW2.2
~IO3: SW1.5, SW2.6, U1.17
~IO3x: J6.3, SW2.3
~IO4: SW2.5, U1.16
~IO4x: J6.4, SW2.4
~IOCS: J1.1, J1.3, J1.5, J3.5
~IOCS_A: J1.6, SW1.4
~IOCS_V1: J1.2, SW1.2
~IOCS_V2: J1.4, SW1.3
~IRQX: J2.1, J7.1, J7.2, J7.3, J7.4
~RAM_CS: J1.8, J3.2, U1.21
~RAM_OE: J1.7, J3.1, U1.23
~RES: J2.4, J6.5
~ROM_CS: J3.4, U1.20

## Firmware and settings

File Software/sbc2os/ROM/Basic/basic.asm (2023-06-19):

; Enhanced BASIC to assemble under 6502 simulator, $ver 2.22

; $E7E1 $E7CF $E7C6 $E7D3 $E7D1 $E7D5 $E7CF $E81E $E825

; 2.00	new revision numbers start here
; 2.01	fixed LCASE$() and UCASE$()
; 2.02	new get value routine done
; 2.03	changed RND() to galoise method
; 2.04	fixed SPC()
; 2.05	new get value routine fixed
; 2.06	changed USR() code
; 2.07	fixed STR$()
; 2.08	changed INPUT and READ to remove need for $00 start to input buffer
; 2.09	fixed RND()
; 2.10	integrated missed changes from an earlier version
; 2.20	added ELSE to IF .. THEN and fixed IF .. GOTO <statement> to cause error
; 2.21	fixed IF .. THEN RETURN to not cause error
; 2.22	fixed RND() breaking the get byte routine

; zero page use ..

LAB_WARM 		= $00		; BASIC warm start entry point
Wrmjpl 		= LAB_WARM+1; BASIC warm start vector jump low byte
Wrmjph 		= LAB_WARM+2; BASIC warm start vector jump high byte

Usrjmp		= $0A		; USR function JMP address
Usrjpl		= Usrjmp+1	; USR function JMP vector low byte
Usrjph		= Usrjmp+2	; USR function JMP vector high byte
Nullct		= $0D		; nulls output after each line
TPos			= $0E		; BASIC terminal position byte
TWidth		= $0F		; BASIC terminal width byte
Iclim			= $10		; input column limit
Itempl		= $11		; temporary integer low byte
Itemph		= Itempl+1	; temporary integer high byte

nums_1		= Itempl	; number to bin/hex string convert MSB
nums_2		= nums_1+1	; number to bin/hex string convert
nums_3		= nums_1+2	; number to bin/hex string convert LSB

Srchc			= $5B		; search character
Temp3			= Srchc	; temp byte used in number routines
Scnquo		= $5C		; scan-between-quotes flag
Asrch			= Scnquo	; alt search character

XOAw_l		= Srchc	; eXclusive OR, OR and AND word low byte
XOAw_h		= Scnquo	; eXclusive OR, OR and AND word high byte

Ibptr			= $5D		; input buffer pointer
Dimcnt		= Ibptr	; # of dimensions
Tindx			= Ibptr	; token index

Defdim		= $5E		; default DIM flag
Dtypef		= $5F		; data type flag, $FF=string, $00=numeric
Oquote		= $60		; open quote flag (b7) (Flag: DATA scan; LIST quote; memory)
Gclctd		= $60		; garbage collected flag
Sufnxf		= $61		; subscript/FNX flag, 1xxx xxx = FN(0xxx xxx)
Imode			= $62		; input mode flag, $00=INPUT, $80=READ

Cflag			= $63		; comparison evaluation flag

TabSiz		= $64		; TAB step size (was input flag)

next_s		= $65		; next descriptor stack address

					; these two bytes form a word pointer to the item
					; currently on top of the descriptor stack
last_sl		= $66		; last descriptor stack address low byte
last_sh		= $67		; last descriptor stack address high byte (always $00)

des_sk		= $68		; descriptor stack start address (temp strings)

;			= $70		; End of descriptor stack

ut1_pl		= $71		; utility pointer 1 low byte
ut1_ph		= ut1_pl+1	; utility pointer 1 high byte
ut2_pl		= $73		; utility pointer 2 low byte
ut2_ph		= ut2_pl+1	; utility pointer 2 high byte

Temp_2		= ut1_pl	; temp byte for block move	

FACt_1		= $75		; FAC temp mantissa1
FACt_2		= FACt_1+1	; FAC temp mantissa2
FACt_3		= FACt_2+1	; FAC temp mantissa3

dims_l		= FACt_2	; array dimension size low byte
dims_h		= FACt_3	; array dimension size high byte

TempB			= $78		; temp page 0 byte

Smeml			= $79		; start of mem low byte		(Start-of-Basic)
Smemh			= Smeml+1	; start of mem high byte	(Start-of-Basic)
Svarl			= $7B		; start of vars low byte	(Start-of-Variables)
Svarh			= Svarl+1	; start of vars high byte	(Start-of-Variables)
Sarryl		= $7D		; var mem end low byte		(Start-of-Arrays)
Sarryh		= Sarryl+1	; var mem end high byte		(Start-of-Arrays)
Earryl		= $7F		; array mem end low byte	(End-of-Arrays)
Earryh		= Earryl+1	; array mem end high byte	(End-of-Arrays)
Sstorl		= $81		; string storage low byte	(String storage (moving down))
Sstorh		= Sstorl+1	; string storage high byte	(String storage (moving down))
Sutill		= $83		; string utility ptr low byte
Sutilh		= Sutill+1	; string utility ptr high byte
Ememl			= $85		; end of mem low byte		(Limit-of-memory)
Ememh			= Ememl+1	; end of mem high byte		(Limit-of-memory)
Clinel		= $87		; current line low byte		(Basic line number)
Clineh		= Clinel+1	; current line high byte	(Basic line number)
Blinel		= $89		; break line low byte		(Previous Basic line number)
Blineh		= Blinel+1	; break line high byte		(Previous Basic line number)

Cpntrl		= $8B		; continue pointer low byte
Cpntrh		= Cpntrl+1	; continue pointer high byte

Dlinel		= $8D		; current DATA line low byte
Dlineh		= Dlinel+1	; current DATA line high byte

Dptrl			= $8F		; DATA pointer low byte
Dptrh			= Dptrl+1	; DATA pointer high byte

Rdptrl		= $91		; read pointer low byte
Rdptrh		= Rdptrl+1	; read pointer high byte

Varnm1		= $93		; current var name 1st byte
Varnm2		= Varnm1+1	; current var name 2nd byte

Cvaral		= $95		; current var address low byte
Cvarah		= Cvaral+1	; current var address high byte

Frnxtl		= $97		; var pointer for FOR/NEXT low byte
Frnxth		= Frnxtl+1	; var pointer for FOR/NEXT high byte

Tidx1			= Frnxtl	; temp line index

Lvarpl		= Frnxtl	; let var pointer low byte
Lvarph		= Frnxth	; let var pointer high byte

prstk			= $99		; precedence stacked flag

comp_f		= $9B		; compare function flag, bits 0,1 and 2 used
					; bit 2 set if >
					; bit 1 set if =
					; bit 0 set if <

func_l		= $9C		; function pointer low byte
func_h		= func_l+1	; function pointer high byte

garb_l		= func_l	; garbage collection working pointer low byte
garb_h		= func_h	; garbage collection working pointer high byte

des_2l		= $9E		; string descriptor_2 pointer low byte
des_2h		= des_2l+1	; string descriptor_2 pointer high byte

g_step		= $A0		; garbage collect step size

Fnxjmp		= $A1		; jump vector for functions
Fnxjpl		= Fnxjmp+1	; functions jump vector low byte
Fnxjph		= Fnxjmp+2	; functions jump vector high byte

g_indx		= Fnxjpl	; garbage collect temp index

FAC2_r		= $A3		; FAC2 rounding byte

Adatal		= $A4		; array data pointer low byte
Adatah		= Adatal+1	; array data pointer high  byte

Nbendl		= Adatal	; new block end pointer low byte
Nbendh		= Adatah	; new block end pointer high  byte

Obendl		= $A6		; old block end pointer low byte
Obendh		= Obendl+1	; old block end pointer high  byte

numexp		= $A8		; string to float number exponent count
expcnt		= $A9		; string to float exponent count

numbit		= numexp	; bit count for array element calculations

numdpf		= $AA		; string to float decimal point flag
expneg		= $AB		; string to float eval exponent -ve flag

Astrtl		= numdpf	; array start pointer low byte
Astrth		= expneg	; array start pointer high  byte

Histrl		= numdpf	; highest string low byte
Histrh		= expneg	; highest string high  byte

Baslnl		= numdpf	; BASIC search line pointer low byte
Baslnh		= expneg	; BASIC search line pointer high  byte

Fvar_l		= numdpf	; find/found variable pointer low byte
Fvar_h		= expneg	; find/found variable pointer high  byte

Ostrtl		= numdpf	; old block start pointer low byte
Ostrth		= expneg	; old block start pointer high  byte
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

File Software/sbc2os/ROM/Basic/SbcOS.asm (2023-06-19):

;---------------------------------------------------------------------
;  SBC Firmware V5.1, 5-30-05, by Daryl Rictor
;
; ----------------- assembly instructions ---------------------------- 
;               *=   $E800                ; start of operating system
Start_OS       jmp   MonitorBoot         ; easy access to monitor program
Jmp_CR	   jmp   Print_CR		
Jmp_1sp	   jmp   Print1SP			; jump table for usable monitor
Jmp_2sp	   jmp   Print2SP			; routines
Jmp_xsp	   jmp   PrintXSP			; This will not change in future
Jmp_nib	   jmp   PrintDig			; releases, only be added to
Jmp_byte	   jmp   Print1Byte
jmp_wrd	   jmp   Print2Byte
jmp_bell	   jmp   Bell
jmp_delay	   jmp   Delay
jmp_scan	   jmp   Scan_input
jmp_inp        jmp   Input_chr  
jmp_out        jmp   Output
jmp_input	   jmp   Input
jmp_input1     jmp   Input1
;
;
;*********************************************************************       
;  local Zero-page variables
;
Prompt         =     $32               ; 1 byte   
linecnt        =     $33               ; 1 byte
Modejmp        =     $34               ; 1 byte
Hexdigcnt      =     $35               ; 1 byte
OPCtxtptr      =     $36               ; 1 byte
Memchr         =     $37               ; 1 byte
Startaddr      =     $38               ; 2 bytes
Startaddr_H    =     $39
Addrptr        =     $3a               ; 2 bytes
Addrptr_H       =    $3b
Hexdigits      =     $3c               ; 2 bytes
Hexdigits_H    =     $3d
Memptr         =     $3e               ; 2 bytes
Memptr_H       =     $3f
;
; Local Non-Zero Page Variables
;
buffer         =     $0300             ; keybd input buffer (127 chrs max)
PCH            =     $03e0             ; hold program counter (need PCH next to PCL for Printreg routine)
PCL            =     $03e1             ;  ""
ACC            =     $03e2             ; hold Accumulator (A)
XREG           =     $03e3             ; hold X register
YREG           =     $03e4             ; hold Y register
SPTR           =     $03e5             ; hold stack pointer
PREG           =     $03e6             ; hold status register (P)
ChrInVect      =     $03eb             ; holds Character Input Address
ScanInVect     =     $03ee             ; holds Character Scan Input address
ChrOutVect     =     $03f1             ; holds Character Output Address
BRKvector      =     $03f4             ; holds application break vector
RESvector      =     $03f7             ; 2F7,8,9 holds application reset vector & checksum
INTvector      =     $03fa             ; 2FA,B,C holds application interrupt vector & checksum
NMIvector      =     $03fd             ; 2FD,E,F holds application NMI vector & checksum

;               
; *************************************************************************
; kernal commands
; *************************************************************************
; PrintRegCR   - subroutine prints a CR, the register contents, CR, then returns
; PrintReg     - same as PrintRegCR without leading CR
; Print2Byte   - prints AAXX hex digits
; Print1Byte   - prints AA hex digits
; PrintDig     - prints A hex nibble (low 4 bits)
; Print_CR     - prints a CR (ASCII 13)and LF (ASCII 10)
; PrintXSP     - prints # of spaces in X Reg
; Print2SP     - prints 2 spaces
; Print1SP     - prints 1 space
; Input_assem  - Alternate input prompt for Assember
; Input        - print <CR> and prompt then get a line of input, store at buffer
; Input_Chr    - get one byte from input port, waits for input
; Scan_Input   - Checks for an input character (no waiting)
; Output       - send one byte to the output port
; Bell         - send ctrl-g (bell) to output port
; Delay        - delay loop
; *************************************************************************
;
RegData        .byte" PC=  A=  X=  Y=  S=  P= (NVRBDIZC)="
;
PrintReg       Jsr   Print_CR          ; Lead with a CR
               ldx   #$ff              ;
               ldy   #$ff              ;
Printreg1      iny                     ;
               lda   Regdata,y         ;
               jsr   Output            ;
               cmp   #$3D              ; "="
               bne   Printreg1         ;
Printreg2      inx                     ;
               cpx   #$07              ;
               beq   Printreg3         ; done with first 6
               lda   PCH,x             ;  
               jsr   Print1Byte        ;
               cpx   #$00              ;
               bne   Printreg1         ;
               bra   Printreg2         ;
Printreg3      dex                     ;
               lda   PCH,x             ; get Preg
               ldx   #$08              ; 
Printreg4      rol                     ;
               tay                     ;
               lda   #$31              ;
               bcs   Printreg5         ;
               dec                     ;
Printreg5      jsr   Output            ;
               tya                     ;
               dex                     ;
               bne   Printreg4         ;
; fall into the print CR routine
Print_CR       PHA                     ; Save Acc
               LDA   #$0D              ; "cr"
               JSR   OUTPUT            ; send it
               LDA   #$0A              ; "lf"
               JSR   OUTPUT            ; send it
               PLA                     ; Restore Acc
               RTS                     ;
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

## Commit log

2022-11-09 Initial Release
    [16 bit Hex.sch, 6502_IO.sch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]
2022-11-15 Rev001 Publish - Rev002 WIP
    General folder tidy. Rev001 tidied to publish. Rev002 WIP.
    [16 bit Hex.sch, 6502_IO.sch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]
2022-11-15 Rev001 Gerbers added
    [AT_65C02_Computer-B_Cu.gbl, AT_65C02_Computer-B_Mask.gbs, AT_65C02_Computer-B_SilkS.gbo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]
2022-11-15 Silk Screen Modifications - Hex Display WIP
    [AT_65C02_Computer-B_Cu.gbl, AT_65C02_Computer-B_Mask.gbs, AT_65C02_Computer-B_SilkS.gbo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]
2022-11-15 Hex Display Updates WIP
    [16 bit Hex.sch, 8bit Hex.sch, AT_HEX.kicad_pcb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]
2022-12-02 HEX Board Mods
    Hex board changes. Main board Hex to Latches
    [16 bit Hex.sch, 6502_IO.sch, AT65C02_Blinkenlights.sch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]
2022-12-05 release revisions
    REv001,002 and HEX
    [AT65C02_Blinkenlights.sch, AT_65C02_Computer.kicad_pcb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]
2023-03-14 rev003 started
    [6502_IO.sch, AT65C02_Blinkenlights.sch, AT_65C02_Computer_Rev002.csv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]
2023-03-15 schematic updates
    [6502_IO.sch, AT65C02_Blinkenlights.sch, AT_65C02_Computer_Rev003.sch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]
2023-03-31 kicad gitignore
2023-03-31 Rev003 tidy
    [6502_IO.sch, AT65C02_Blinkenlights.sch, AT_65C02_Computer.kicad_pcb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]
2023-03-31 clean old revs
    [AT_65C02_Computer-B_Cu.gbl, AT_65C02_Computer-B_Mask.gbs, AT_65C02_Computer-B_SilkS.gbo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]
2023-04-05 PDF Schematic Added
    [16 bit Hex.sch, 6502_IO.sch, 8bit Hex.sch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]
2023-04-05 BOM added
    [6502_IO.sch, AT65C02_Blinkenlights.sch, AT_65C02_Computer_Rev003.csv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]
2023-04-05 Images added
    [16 bit Hex.sch, 8bit Hex.sch, AT65C02_HEX_rev002.csv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]
2023-04-05 Gerbers Added
    [AT65C02_HEX_rev002-B_Cu.gbl, AT65C02_HEX_rev002-B_Mask.gbs, AT65C02_HEX_rev002-B_Paste.gbp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]
2023-04-05 Pads changed
    [AT_65C02_Computer_Rev003-B_Cu.gbl, AT_65C02_Computer_Rev003-B_Mask.gbs, AT_65C02_Computer_Rev003-B_Paste.gbp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]
2023-04-19 memory decoder revised
    [Memory Decoder-B_Cu.gbl, Memory Decoder-B_Mask.gbs, Memory Decoder-B_Paste.gbp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]
2023-05-01 Silkscreen updates
    [AT_65C02_Computer_Rev003-B_Cu.gbl, AT_65C02_Computer_Rev003-B_Mask.gbs, AT_65C02_Computer_Rev003-B_Paste.gbp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]
2023-05-01 U8 ZIF socket
    [6502_IO.sch, AT65C02_Blinkenlights.sch, AT_65C02_Computer_Rev003.kicad_pcb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]
2023-05-01 ZIF Gerbers added
    [AT_65C02_Computer_Rev003-B_Cu.gbl, AT_65C02_Computer_Rev003-B_Mask.gbs, AT_65C02_Computer_Rev003-B_Paste.gbp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]
2023-05-09 Rev004 WIP updates
    Work in Progress
    [6502_IO.sch, AT65C02_Blinkenlights.sch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]
2023-05-09 BOM update
    [AT_65C02_Computer_Rev004.csv]
2023-05-09 HEX board Rev003
    [AT65C02_HEX_rev002.csv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]
2023-05-10 Rev004 revisions
    [AT65C02_HEX_rev002-B_Cu.gbl, AT65C02_HEX_rev002-B_Mask.gbs, AT65C02_HEX_rev002-B_Paste.gbp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]
2023-05-10 Rev004 updates
    [Memory Decoder-B_Cu.gbl, Memory Decoder-B_Mask.gbs, Memory Decoder-B_Paste.gbp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]
2023-05-22 debugger wip
    [debugger.kicad_pcb, debugger.kicad_sch]
2023-05-22 silkscreen black and white
    [AT_65C02_Computer_Rev004.kicad_pcb]
2023-06-01 Hex board Resistor value update
    [AT65C02_HEX_rev003-B_Cu.gbl, AT65C02_HEX_rev003-B_Mask.gbs, AT65C02_HEX_rev003-B_Paste.gbp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]
2023-06-01 Hex Board BOM update
    [AT65C02_HEX_rev003.csv]
2023-06-12 Code Added
    [basic.cfg, boot.cfg, program.cfg]
2023-06-17 readme update
    [debugger.kicad_pcb]
2023-08-06 minor PCB revisions
    [6502_IO.sch, AT65C02_Blinkenlights.sch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]
2023-08-06 Minor PCB updates
2023-08-23 Jumper explanation added
    [6502_IO.sch, AT_65C02_Computer_Rev004.kicad_pcb, Power_Connectors.sch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]
2024-06-06 Delete Software/ATOS1 directory
    WIP removed from Public
    [applesoft.cfg, cbmbasic1.cfg, cbmbasic2.cfg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]
2024-06-06 Delete KiCad/Debugger directory
    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
    [debugger_plugin.kicad_pcb, debugger_plugin.kicad_sch, debugger_shield.kicad_pcb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]
2025-05-29 Refresh 2025
    No changes just a refresh and update to readme.
    [6502_IO.sch, AT65C02_Blinkenlights.sch, AT65C02_HEX_rev003.sch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]
2025-12-15 ATOS Software added
    ATOS release
    [atos.cfg, load.cfg]
